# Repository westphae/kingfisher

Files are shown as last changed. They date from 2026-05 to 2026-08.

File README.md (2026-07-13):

# Kingfisher

Kingfisher is a flight data recorder for light aircraft. It runs on a
Raspberry Pi mounted in the cabin, reads sensors over IIO and ancillary
links, derives quantities like pressure altitude, magnetic declination,
and an AHRS-based attitude estimate, persists everything to a SQLite
flight database, and exposes a live cockpit UI over HTTP/WebSocket.

## Hardware

* **Main unit** mounted near the aircraft CG, inside the cabin.
  * Main controller is a `Raspberry Pi 5`.
  * Accel/gyro is a `ICM45686`.
  * GPS is a `NEO-M9N` attached via UART.
* **Pod unit** mounted out under the wing.
  * Pod controller is an `ESP32-C3-Mini-1`, variant `ESP32-C3FH4`.
  * Airspeed sensor is a `MS4525DO-DS5AI001DP`.
  * Static pressure (altimeter) sensor is a `BMP581`.
  * Magnetometer (compass) sensor is a `MMC5983MA`.

The pod is battery-powered and transmits sensor data to the main unit
wirelessly. See `internal/pod/` (Pi side) and `firmware/pod/` (ESP32
side) for the implementation.

## GPS

The `NEO-M9N` is wired to the Pi 5's GPIO UART (GPIO 14/15, header pins
8/10), enabled by `dtoverlay=uart0-pi5` in `/boot/firmware/config.txt`.

Kingfisher assumes the host wall clock is already sane. For offline operation,
discipline the Pi with `gpsd` + `chrony` first; see `docs/time-sync.md`.

**Pi 5 gotcha:** that UART is `/dev/ttyAMA0`, *not* `/dev/serial0`. On a
Pi 5 `/dev/serial0` points at the dedicated 3-pin debug-UART connector
(`ttyAMA10`), so gpsd must be told to use `/dev/ttyAMA0`. In
`/etc/default/gpsd`:

```
DEVICES="/dev/ttyAMA0"
GPSD_OPTIONS="-n -b -s 115200"
```

The `-b` (read-only) flag is deliberate. If you configured the M9N for 115200 baud
(saved to flash), you must also pass `-s 115200`; with `-b`, gpsd will not autobaud
and otherwise opens the port at 19200, which produces no fix and no TPV output. Left to manage the receiver,
gpsd subscribes a heavy set of UBX messages (NAV-SAT/SIG/POSECEF/…) that
saturate the link and drop the effective fix rate. Read-only keeps the
lean NAV-PVT-only stream the receiver is configured to emit, so we get a
clean 10 Hz.

For time discipline, prefer chrony's SOCK integration over SHM and keep
`chronyd` ahead of `gpsd` in the service order (and restart `gpsd` after any
`chronyd` restart). The repo-owned examples live in `deploy/time-sync/`. With PPS
wired, PPS disciplines the clock and the GPS serial source is marked `noselect`
(time-of-day only) — no per-receiver `offset` tuning is needed. See
`docs/time-sync.md`.

The receiver itself is configured once with `ubxtool` and the settings
are saved to its flash (they survive power-off). With gpsd running:

```bash
export UBXOPTS="-P 32.01"                      # M9N protocol version
ubxtool -z CFG-NAVSPG-DYNMODEL,7,7             # Airborne <2g (vs 0=portable)
ubxtool -z CFG-RATE-MEAS,100,7                 # 10 Hz (100 ms)
ubxtool -z CFG-RATE-NAV,1,7                    # 1 nav solution per measurement
```

To bump the link to 115200 and emit only UBX-NAV-PVT (do this with gpsd
*stopped*, talking to the port directly), set `CFG-UART1-BAUDRATE` to
`115200`, `CFG-MSGOUT-UBX_NAV_PVT_UART1` to `1`, and the other
`CFG-MSGOUT-UBX_NAV_*_UART1` items to `0`. The `,7` layer suffix writes
RAM+BBR+Flash so the config persists. The **Airborne dynamic model is the
most important setting** — the factory "portable" default filters motion
in ways that lag or drop fixes during climbs, descents, and turns.

### Rate (5 / 10 Hz)

The receiver always runs at 10 Hz; the GPS tab in the cockpit UI selects
the **recorded** rate (`rate_hz`, 5 or 10). Because gpsd is read-only,
kingfisher doesn't reconfigure the receiver — it decimates the 10 Hz
stream in software (`internal/gps`), publishing/recording every fix at
10 Hz or every other fix at 5 Hz. The setting persists in
`config.json` under `gps.rate_hz`.

### Timestamps (`ts_ns` vs fix time)

Each row in the `gps` table (and every other sensor table) has **`ts_ns`**: nanoseconds
on the Pi's disciplined wall clock. For GPS, **`ts_ns` is not the fix epoch** — it
is when kingfisher **received** the gpsd report. The receiver's fix time is stored
separately as the **`fix_time_unix_s`** column (typically **~600–700 ms earlier**
than `ts_ns` on this M9N + gpsd setup; that gap is receiver/pipeline lag, not clock
error).

For sensor fusion: align GPS with cabin IMU and pod data on **`ts_ns`**; use
**`fix_time_unix_s`** when you need GNSS solution time. Full per-source semantics
(buffered IIO, pod reconstruction, derived devices, fusion checklist) are in
**[`docs/timestamps.md`](docs/timestamps.md)**.

## Timestamps

All flight DB sensor tables store **`ts_ns`** (nanoseconds, Unix epoch) on the
Pi host wall clock (`CLOCK_REALTIME`), ideally GNSS-disciplined before recording.

| Source | `ts_ns` meaning (summary) |
|---|---|
| Buffered IIO (ICM45686, …) | Kernel capture time when `current_timestamp_clock == realtime` |
| Polled IIO | Time when the periodic sysfs read completed |
| GPS | Pi time when the TPV was **received**; fix epoch is **`fix_time_unix_s`** |
| Pod (BMP581, MS4525, MMC5983) | Sample time reconstructed onto Pi clock from pod uptime + `age_us` |
| Derived (AHRS, press_alt, geo, compass) | Time when the value was **computed** (inputs may be slightly older) |

See **[`docs/timestamps.md`](docs/timestamps.md)** for measurement error vs true
sample time, GPS fusion guidance, and implementation references.

## Building

```
go build ./cmd/kingfisher
```

Pod firmware lives under `firmware/pod/`; see
[`firmware/pod/README.md`](firmware/pod/README.md) for the wiring,
toolchain, and flashing steps.

## Running

```
./kingfisher
```

Kingfisher listens on **`http_addr`** (default **`:8080`**) and is meant to sit
behind a reverse proxy on the aircraft LAN. Configuration lives in
`~/.config/kingfisher/config.json`.

### HTTPS with Caddy (recommended)

[Caddy](https://caddyserver.com/) terminates TLS on port **443**, redirects HTTP
port **80** to HTTPS, and reverse-proxies to kingfisher on `localhost:8080`
(including WebSocket traffic for the live cockpit and `/terminal`).

Example Caddyfile (also in **`deploy/caddy/Caddyfile`**). Adjust the hostname and
LAN IP for your Pi:

```caddyfile
https://kingfisher.lan, https://kingfisher, https://192.168.10.1, https://192.168.86.151, https://127.0.0.1 {
    tls internal
    reverse_proxy localhost:8080
}

http://kingfisher.lan, http://kingfisher, http://192.168.10.1, http://192.168.86.151, http://127.0.0.1 {
    redir https://{host}{uri} permanent
}
```

`tls internal` uses a **local certificate authority** managed by Caddy — fine for
a private LAN; not a public-trusted cert.

**Install on Debian / Raspberry Pi OS** (official apt repo):

```bash
sudo apt install -y debian-keyring debian-archive-keyring apt-transport-https curl
curl -1sLf 'https://dl.cloudsmith.io/public/caddy/stable/gpg.key' \
  | sudo gpg --dearmor -o /usr/share/keyrings/caddy-stable-archive-keyring.gpg
curl -1sLf 'https://dl.cloudsmith.io/public/caddy/stable/debian.deb.txt' \
  | sudo tee /etc/apt/sources.list.d/caddy-stable.list
sudo chmod o+r /usr/share/keyrings/caddy-stable-archive-keyring.gpg \
  /etc/apt/sources.list.d/caddy-stable.list
sudo apt update && sudo apt install -y caddy
sudo cp deploy/caddy/Caddyfile /etc/caddy/Caddyfile
sudo caddy validate --config /etc/caddy/Caddyfile
sudo systemctl enable --now caddy
```

Keep kingfisher on the loopback port only:

```json
"http_addr": ":8080"
```

**Trust the CA**

On the Pi (so curl and local browsers trust HTTPS):

```bash
sudo caddy trust
```

On laptops, phones, and tablets, install Caddy's root certificate once. After
Caddy has started at least once, the file is usually:

```text
/var/lib/caddy/.local/share/caddy/pki/authorities/local/root.crt
```

Copy it to the device and add it to the system/browser trust store (or use
`sudo caddy trust` on each Linux machine). Until then, browsers show a
certificate warning — you can proceed for testing, but trusting the CA removes
the nag and enables secure-context APIs (clipboard, etc.) over HTTPS.

Open the cockpit at **`https://<pi-hostname-or-ip>/`** (port 443; HTTP on port 80
redirects automatically).

### EFB apps (ForeFlight, iFlyEFB)

Kingfisher can broadcast **Stratux-compatible GDL90** over UDP port **4000** so
tablets on the Pi access point receive GPS position and AHRS attitude without a
separate Stratux box. Enable in `config.json`:

```json
"gdl90": {
  "enabled": true,
  "static_ips": ["192.168.10.141", "192.168.10.40"]
}
```

On the Pi AP (NetworkManager + dnsmasq), list each tablet’s reserved IP in
`static_ips` — see **`deploy/efb/ap-setup.md`** for DHCP reservations, MAC
privacy settings, and verification.

**ForeFlight:** connect to the Pi Wi‑Fi → *More* → *Devices* → enable GDL90 at
**`192.168.10.1`**.

**iFlyEFB:** *Menu* → *About* → *Connected Devices* → Stratux/FlightBox;
*Setup* → *ADS-B* → Stratux/Flightbox (manual). Expect **GPS Data Only**.

Requires `ahrs.enabled` for attitude. Traffic and weather are not sent (no ADS-B
receiver). Check `/api/status` → `gdl90` for client count and last send time;
`tcpdump -i wlan0 udp port 4000` should show steady packets when an EFB is
connected.

### systemd user service (boot)

Kingfisher is normally run as your Pi login user (IIO device access, config under
`~/.config/kingfisher/`, flight DBs under `~/kingfisher/flights`). A **systemd user
unit** starts it at boot without keeping an SSH session open.

**Prerequisites:** gpsd and chrony configured per **`docs/time-sync.md`**. If you
use Caddy for HTTPS, enable **`caddy.service`** separately (system unit); start
kingfisher first so the reverse proxy has a backend on `:8080`.

1. **Install the binary** with `go install` (default: `$(go env GOPATH)/bin`, usually
   `~/go/bin`; override with `GOBIN` if you use it):

   ```bash
   cd ~/go/src/github.com/westphae/kingfisher
   go install ./cmd/kingfisher
   ```

2. **Install the user unit** from the repo example (path must match step 1):

   ```bash
   mkdir -p ~/.config/systemd/user
   bin="$(go env GOBIN)"
   [ -z "$bin" ] && bin="$(go env GOPATH)/bin"
   sed "s|__KINGFISHER_BIN__|$bin/kingfisher|g" \
     deploy/systemd/kingfisher.service.example \
     > ~/.config/systemd/user/kingfisher.service
   ```

3. **Enable linger** so the user service starts at boot (not only after login):

   ```bash
   sudo loginctl enable-linger "$USER"
   loginctl show-user "$USER" -p Linger   # expect Linger=yes
   ```

4. **Enable and start:**

   ```bash
   systemctl --user daemon-reload
   systemctl --user enable --now kingfisher.service
   ```

5. **Check status and logs:**

   ```bash
   systemctl --user status kingfisher.service
   journalctl --user-unit=kingfisher.service -f
   curl -s http://127.0.0.1:8080/api/status | head
   ```

   Use **`--user-unit`** (not `journalctl --user`): on Raspberry Pi OS the user
   manager logs to the **system** journal; there is no separate per-user journal
   file under `/run/user/$UID/journal`, so `journalctl --user` shows nothing even
   though `systemctl --user status` does.

The unit starts kingfisher **immediately** — there is no chrony pre-wait (the
old `kingfisher-prestart.sh` gate is retired). The UI and recording come up in
seconds on the RTC clock:

| Situation | Behavior |
|---|---|
| **RTC sane (normal)** | Timestamp-named flight DB; red cockpit banner until chrony locks |
| **Any chrony step/slew ≥ 20 ms** | Row in the DB's `clock_offsets` table (see `docs/timestamps.md`) |
| **RTC dead (clock reads 1970)** | DB named `unsynced_NNNN_<tail>.db`; renamed at close once true time is known |

Startup metadata, the `clock_offsets` mapping table, and the cockpit clock
badge/banner record discipline state. `RestartSec=30` retries a failed main
process.

**After upgrading:** `go install ./cmd/kingfisher`, then
`systemctl --user restart kingfisher.service`.

**Stop/disable:**

```bash
systemctl --user disable --now kingfisher.service
```

Example unit file: **`deploy/systemd/kingfisher.service.example`**.

### Browser terminal (optional)

Kingfisher can expose a full-screen web terminal at **`/terminal`** (footer link
on the cockpit page). It is **disabled by default**; enable in `config.json`:

```json
"terminal": {
  "enabled": true,
  "user": "eric",
  "authorized_keys": [
    "ssh-ed25519 AAAA... kingfisher-terminal"
  ],
  "allow_password": false,
  "session_timeout_min": 480,
  "max_sessions": 2
}
```

**Public-key login (recommended):** put one or more OpenSSH `authorized_keys` lines in
`authorized_keys` and set `user` to the Unix account the shell should run as. The
browser signs a one-time challenge with a private key stored locally (generate in
the terminal UI, or import an unencrypted Ed25519 `id_ed25519`). Your password is
never sent. Set `"allow_password": true` to keep PAM login as a fallback.

**Password login:** when `authorized_keys` is omitted, login uses **Linux PAM**
(same username/password as SSH). The shell runs as the authenticated user when
kingfisher runs as that user; logging in as a different user requires root or
`cap_setuid` on the kingfisher binary.

**Security:** with Caddy **`tls internal`** in front (see above), terminal traffic
including WebSockets is encrypted on the LAN. Without HTTPS, password login sends
credentials in cleartext; public-key login avoids sending passwords but session
cookies and shell I/O are still visible on the wire.

Building on Linux requires **`libpam0g-dev`** for CGO (`apt install libpam0g-dev`).

If you want DB filenames, session start times, and buffered IIO timestamps to be
meaningful immediately after boot, start kingfisher only after GNSS time sync is
healthy. `docs/time-sync.md` includes a `chronyc waitsync` systemd pattern and a
verification checklist. Per-table **`ts_ns`** semantics and sensor-fusion usage
(including GPS **`fix_time_unix_s`**) are documented in **`docs/timestamps.md`**.

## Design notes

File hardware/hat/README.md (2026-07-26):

# Kingfisher Sensor HAT (rev 0.2)

Custom Raspberry Pi HAT that consolidates the cabin sensors currently on SparkFun /
breakout boards + ribbon cable:

| Ref | Part | Role |
|-----|---|---|
| U1 | ICM-45686 | Cabin IMU (I²C `0x68`, INT → GPIO17) |
| U2 | BMP581 | Cabin baro / temp (I²C `0x47`) |
| U3 | AP2112K-3.3 | 5 V → 3.3 V for GPS |
| U4 | NEO-M9N | GNSS (UART0 + PPS → GPIO18); `V_BCKP` diode-OR’d |
| U5 | RV-3028-C7 | I²C RTC (`0x52`), `VBACKUP` ← CR2032 |
| BT1 | CR2032 + Keystone 3002 | Replaceable backup for RTC + GPS |
| D1, D2 | BAT54 | Schottky OR: `+3V3_GPS` / `VBAT` → `V_BCKP` |
| J1 | 2×20 pin socket | Mates **extended GPIO pins above the M.2 HAT+** (bottom side) |
| J2 | U.FL | Antenna → existing SMA bulkhead pigtail |

Form factor: official Pi HAT outline (65 × 56.5 mm, M2.5 holes 58 × 49).

**Why RV-3028 not DS3231?** DS3231 sits on `0x68` and would collide with the ICM.
**Why CR2032 not CR1220?** ~5× capacity for multi-year GPS/`V_BCKP` + RTC backup;
Keystone 3002 is a common replaceable HAT holder (check lid height).

See [docs/DESIGN.md](docs/DESIGN.md) for the backup topology, I²C map, retention
estimates, and the “what else” resilience shortlist (test points / DNP pull-ups
recommended; second watchdog / LED forest skipped).

## Open in KiCad

Requires **KiCad 9** (project generated against 9.0.2).

```bash
kicad hardware/hat/kingfisher-hat.kicad_pro
```

Project-local libraries:

- `libs/Kingfisher.kicad_sym` — ICM-45686, BMP581, NEO-M9N
- `libs/Kingfisher.pretty` — BMP581 land pattern (adapted from SparkFun Qwiic BMP581, CC-BY-SA 4.0)

Regenerate libraries / schematic scaffolding (stdlib only — **no uv project**):

```bash
python3 hardware/hat/scripts/build_libs.py
python3 hardware/hat/scripts/build_sch.py   # overwrites schematic
kicad-cli sch export netlist hardware/hat/kingfisher-hat.kicad_sch
```

Any future `pcbnew` automation must use **system** Python with apt KiCad
(`python3-pcbnew`), not a uv venv — the PCB API is not a PyPI package.

## Status (rev 0.2)

Done:

- HAT mechanical from KiCad Raspberry Pi HAT template (outline, holes, bottom GPIO socket)
- Custom symbols + BMP581 footprint
- **Loadable** schematic rev 0.2 (ICM, BMP581, GPS, LDO, U.FL, RV-3028, CR2032, diode-OR)
  — netlist exports 18 components; open in eeschema to tidy wire/label geometry
- PCB: 4-layer stack selected; major footprints placed (not yet routed); BT1/U5/D1–D2 placement TBD
- Design notes for RTC address, GPS backup, and resilience add-ons

Not done yet:

1. Schematic pin–label wiring cleanup + ERC green
2. Place BT1 / U5 / diodes / test points; full routing
3. Cardboard / 3D mockup (pin engagement + CR2032 lid clearance)
4. JLCPCB BOM / CPL export
5. Software: cabin BMP581 reader + `i2c-rtc` for RV-3028

## Attribution

- Board outline / GPIO placement: KiCad `RaspberryPi-HAT` template
- BMP581 pad geometry: adapted from [SparkFun Qwiic Pressure Sensor BMP581](https://github.com/sparkfun/SparkFun_Qwiic_Pressure_Sensor_BMP581) hardware (CC-BY-SA 4.0)
- NEO-M9N symbol derived from KiCad library `NEO-M8N` (same NEO pinout family)
- GPS backup idea: SparkFun NEO-M9N breakout (diode-OR backup supply; we use replaceable CR2032)

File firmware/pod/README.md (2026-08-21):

# Pod firmware

Rust no_std firmware for the wing-pod `ESP32-C3-Mini-1` (variant
`ESP32-C3FH4`). The pod associates to the cabin Pi's WiFi AP and
transmits postcard-encoded `Frame`s (defined in `pod_wire/`) over UDP.

**Status: Phase 3c — all three I²C sensors coded.** BMP581 uses NORMAL mode +
on-chip FIFO (PT frames); the poll loop drains all pending frames each tick with
per-sample capture times. Mag and airspeed use the tick poll loop with per-sensor
pending queues (default **10 Hz** = uplink rate). Uplink ships up to
`MAX_READINGS` readings total per datagram; firmware logs
`dropped … (pending full)` or `(batch full)` when a queue or the wire batch
overflows.
**No sensor is required** at boot; missing devices are re-probed every 5 s.

## Bill of materials

| Part | Role |
| --- | --- |
| ESP32-C3-Mini-1 (C3FH4) | MCU + radio |
| MS4525DO-DS5AI001DP | Airspeed (differential pressure), I²C 0x28 |
| BMP581 | Static pressure, I²C 0x46 (or 0x47 if SDO tied) |
| MMC5983MA | Magnetometer, I²C 0x30 |
| SparkFun Battery Babysitter | BQ27441 fuel gauge, I²C 0x55 (optional) |
| LiPo cell, 3.7 V nominal | Power (via Battery Babysitter or direct) |
| 3.3 V LDO (≥250 mA) | Regulator, e.g. AP2112-3.3 or MCP1700 |
| 2× 4.7 kΩ | I²C pull-ups (SDA / SCL → 3V3) |
| Pitot/static plumbing tubing  | Routes airflow to MS4525DO and BMP581 |
| Antenna (chip or U.FL pigtail)| 2.4 GHz |

The ESP32-C3-Mini-1 has an on-module PCB antenna; the variant with the
U.FL connector (`ESP32-C3-MINI-1U`) is preferable for a wing pod since
the module sits inside a (probably composite or sheet-metal) fairing.

## Wiring

BMP581 and MMC5983 run at **3.3 V** on the Qwiic bus. The **MS4525DO-DS5**
variant needs **5 V on VCC** (separate from the ESP 3.3 V); I²C lines still
join the same Qwiic chain (confirm your breakout is 3.3 V I²C-tolerant).
Use **4.7 kΩ pull-ups to 3V3** once on the bus; each Qwiic board may also
ship 2.2 kΩ — cut **I2C** on one board if the bus misbehaves when daisy-chaining.

| ESP32-C3 pin | Net | To |
| --- | --- | --- |
| `IO5` | `SDA` | Qwiic / MS4525DO, BMP581, MMC5983MA, BQ27441 |
| `IO6` | `SCL` | Qwiic / MS4525DO, BMP581, MMC5983MA, BQ27441 |

Desk bench with [SparkFun Pro Micro ESP32-C3](https://docs.sparkfun.com/SparkFun_Pro_Micro-ESP32C3/hardware_overview/) + Qwiic cable: firmware uses **IO5/IO6** (matches SparkFun `pins_arduino.h`). A plug-in Qwiic BMP581 (SEN-20170, default **0x47**) needs no extra wiring.

**Battery Babysitter (PRT-13777):** connect the Qwiic port to the same bus. Tie **VPU** to **3.3 V** (ESP `3V3`). A LiPo must be plugged into the Babysitter for the BQ27441 to respond. Pick **750** or **2000** mAh (or type a custom value) in cockpit Settings on the `bq27441` tab. The G1A data memory is RAM-only: unplugging the pack (ITPOR) restores ROM defaults (Design Capacity 1340 mAh). Firmware rewrites **Design Capacity** and **Design Energy** only (TI/SparkFun). It does **not** write State Qmax Cell 0 (`Qmax_mAh = QmaxCell0 × DesignCap / 16384`; default QmaxCell0 is 16384, so Qmax starts at Design Capacity) or Default Design Cap (chem-ID scale). Poking learned FCC into Qmax Cell 0 left FullChargeCapacity stuck at 1340.

Planned wing pod PCB may move the bus to **IO4/IO5**; update `main.rs` when that layout is fixed.
| `IO8`        | `LED`   | Status LED (active-low, with 1 kΩ)    |
| `IO3` (ADC)  | `VBATT` | LiPo cell + ÷2 voltage divider        |
| `3V3`        | `3V3`   | LDO output to all sensors             |
| `GND`        | `GND`   | Common ground                         |
| `IO18`/`IO19`| USB D-/+| USB-C connector for flashing          |
| `EN`         | `EN`    | 10 kΩ pull-up to 3V3, optional button |

**Bench Qwiic chain:** Pro Micro → BMP581 (0x47) → [MMC5983MA](https://www.sparkfun.com/products/19921) (0x30) → MS4525 (0x28) when powered. Firmware re-probes MS4525 every 5 s if it was missing at boot.

The native USB peripheral on `IO18`/`IO19` lets `espflash` talk
directly to the chip — no external USB-UART bridge needed. A single
USB-C connector with ESD protection is sufficient.

### Pitot plumbing

* MS4525DO has two pressure ports labelled `+` and `-`.
  - `+` → pitot (total) tube on a probe ahead of the wing leading edge
  - `−` → static port on the side of the pod
* BMP581 sits in a chamber connected to the same static port (it is a
  silicon MEMS device — keep it out of the airflow stream).
* Mount the MMC5983MA on the same PCB but as far as possible from
  current-carrying traces and the LiPo, and orient it so its X axis
  is aligned with the airframe longitudinal axis when the pod is
  level. Axis corrections happen on the Pi (see the plan), so an
  approximate mount is fine — just keep it consistent.

**TODO — MMC5983 data-ready `INT`:** Wire the breakout’s Qwiic **INT** pin (active-high,
hi-Z until enabled) to a spare ESP32-C3 GPIO on the wing PCB (candidate **IO7** on the
bench Pro Micro; document the net in the table above when fixed). Firmware already sets
`INT_meas_done_en` and polls `Meas_M_Done` over I²C today; still to do: EXTI/GPIO
interrupt handler, read the 7-byte `XOUT` burst on INT (no status polling in the hot
path), and coordinate bus access with the existing async poll task.

### Power & current budget

Steady-state draw with WiFi STA active is ~120 mA average and ~350 mA
peak on transmit. A 1000 mAh LiPo gives ≥ 5 h flight time at 50 Hz
mag / 10 Hz airspeed/static. The LDO must handle the TX peak; AP2112
is OK to 600 mA. Add a 22 µF tantalum + 100 nF ceramic at the LDO
output to keep the radio happy.

A 5 V boost option (so the pod accepts a wider supply range) is fine
to add downstream but doesn't change anything firmware-side.

## Toolchain

ESP32-C3 is a RISC-V 32-bit core (`riscv32imc`). The Rust ESP ecosystem
supports it natively under stable Rust — no nightly or xtensa-llvm
required (that's only the Xtensa-core ESP32 variants).

```bash
# Once per machine:
rustup target add riscv32imc-unknown-none-elf
cargo install espflash
```

`espflash` provides both `cargo espflash` (subcommand) and a standalone
`espflash` binary. It speaks USB-CDC directly to the C3 over the
on-module USB port, so no separate driver/bridge tool is needed on
Linux.

If you also need to read the on-chip serial console while running:

```bash
espflash monitor
```

## Build & flash

Once the source tree exists:

```bash
cd firmware/pod
cargo build --release             # builds the .elf
espflash flash target/riscv32imc-unknown-none-elf/release/pod --monitor
```

The `--monitor` flag stays attached after flash and prints `defmt`
log lines from the running firmware over the same USB connection.

### Pre-shared configuration

Until provisioning lands (v2), pod WiFi and UDP settings live in the
same kingfisher JSON config as the Pi runtime (`~/.config/kingfisher/config.json`).
See [`config.example.json`](../../config.example.json) for the `pod` block shape.

```json
"pod": {
  "wifi_ssid": "kingfisher",
  "wifi_password": "",
  "udp_addr": "192.168.10.1:47808",
  "battery_capacity_mah": 850,
  "burst_soc_pct": 30,
  "burst_window_s": 60,
  "burst_voltage_v_uncalibrated": 3.60,
  "protect_voltage_v": 3.50,
  "protect_soc_pct": 5,
  "low_debounce_s": 45,
  "modem_power_save": false,
  "buffer_max_readings": 128,
  "flush_interval_s": 3,
  "flush_high_watermark": 24
}
```

`pod.udp_addr` must be the AP gateway (`ipv4.addresses` on the Pi AP
connection) and the port kingfisher listens on. `build.rs` reads the
file at compile time and injects values into `src/cfg.rs` via `env!`.
Cross-machine builds: `KINGFISHER_CONFIG=/path/to/config.json cargo build --release`.

## Deferred bench validation (Phase 3c / MS4525)

Not required for Phase 4 firmware work. Run when 5 V is available for the
MS4525DO-DS5:

| Step | Action | Pass criteria |
|---|---|---|
| Power | Apply **5 V** to MS4525 VCC (3.3 V I²C on Qwiic) | Serial: `ms4525 attached at 0x28` within 5 s hot-attach |
| Flash | `cargo build --release` + `espflash flash` (FW `0x0003_0002` or later) | `uplink ok` with non-empty batches |
| Pi | `go run ./cmd/kingfisher` (not podprobe on `:47808`) | `pod` device: `static_*`, `mag_*` |
| Airspeed | Rest + light suction/blow on **+** port | `airspeed_dp_pa` ~0 at rest; moves with ΔP; `airspeed_temp_c` plausible |

## Verification

Pre-condition: Pi WiFi AP running; `~/.config/kingfisher/config.json`
`pod` block matches the AP; sensors on Qwiic (Pro Micro **IO5/IO6**).

1. **Flash**: `cargo build --release` then
   `espflash flash --monitor target/.../release/pod`. Monitor should show:
   - `pod: i2c scan: 0x47(id=0x50) … 0x30(id=0x30)` and `0x28(st=0)` when MS4525 powered
   - `pod: sensor board ready …` (ms4525 line optional if no 5 V)
   - WiFi + `sent Hello` + `uplink ok, … pkts`
2. **Kingfisher**: `go run ./cmd/kingfisher` — `pod` shows `static_*`, `mag_*`, and
   `airspeed_*` when MS4525 is on the bus.
3. **MS4525 bench** (5 V applied): `airspeed_dp_pa` near 0 at rest; suction/blow on
   the `+` port moves ΔP. Without 5 V, `ms4525 not present` is expected.

### Power protocol validation (see docs/pod-power.md)

Bench-verified 2026-07-14 with forced thresholds (temp `KINGFISHER_CONFIG`
with `burst_soc_pct: 100` / `protect_soc_pct: 100`, short `low_debounce_s`,
plus a temporary `CHARGE_CURRENT_A` bump so USB charge current doesn't force
Active):

1. **Burst cycling:** `power_mode` 3/4 in Status; radio drops between
   windows (Pi shows `burst_quiet`); each window drains the full backlog
   (tx counter jumps by ~backlog/8) and DB rows stay continuous across
   radio-off periods (max inter-row gap ≈ sample period, not window
   length). At 50 Hz static the 90% ring-fill trigger fires at ~27 s —
   expected.
2. **Protect:** `power_mode` 5 → 6 in Status, then USB/WiFi drop (deep
   sleep). Timer wake every `PROTECT_WAKE_CHECK_S`: gauge read pre-WiFi;
   recovered/charging resumes a normal boot (fresh uptime + Hello),
   still-low goes straight back to sleep.
3. **Keepalive:** exactly one Hello per association — the Pi's 5 s Ping
   refreshes `last_inbound` (a Ping that doesn't would re-Hello every
   30 s and re-trigger SetRate churn; that bug shipped in Phase 4 and was
   fixed here).

### BQ27441 gauge learning

Design capacity (`pod.battery_capacity_mah`, 750 or 2000 typically) is a **config write** to
the gauge after ITPOR or when 0x3C still shows the G1A factory 1340 mAh. Firmware patches
State subclass 82 **Design Capacity** (offset 10) and **Design Energy** (offset 12), then
SOFT_RESET. **Do not host-write Qmax Cell 0** (offset 0): TI’s default is 16384 Num, and
`Qmax_mAh = QmaxCell0 × Design Capacity / 2^14`. **Do not change Default Design Cap**
(offset 14): it is the chem-ID scale. The Pi may still Ack `QmaxCapacity` and store last FCC in
`pod.battery_learned_mah` for the Settings readout — that value is not programmed
into the chip.

The G1A has **no flash** for these parameters. Unplugging the LiPo JST sets ITPOR.
**Impedance Track learning** (Qmax, resistance profile) still needs a real
charge/discharge at representative load after Design Capacity is correct. Do not
re-enter CFGUPDATE every minute if FCC lags — that suspends gauging.

**Calibration run (bench or wing, pod at normal WiFi/sensor load):**

1. **Full charge** to 4.2 V (charger taper complete), then **rest 30–60 min**.
2. **Discharge** with the pod running normally until **~3.35–3.45 V under load**
   (or SOC ~5–10% once `full` reads near design capacity). That includes the
   discharge knee; **stop there** — do not chase ≤3.1 V for calibration.
3. **Rest ≥2 h** (overnight is fine), then **full charge** again.

One or two such cycles is usually enough. After that, partial cycles maintain
accuracy; repeat a full anchor cycle every few months or after long storage.

**Pass criteria:** serial `bq27441 design 2000 mAh verified` with `0x3C=2000`; live
`battery_capacity_full_mah` is the chip FCC (factory leftover ~1340 until IT
resims — not a Pi last-saved substitute); `battery_gauge_learned` once FCC is
70–120% of the configured pack; SOC tracks voltage on the next partial cycle.

**Cell note:** a single deep discharge to ~3.1 V loaded is unlikely to harm the pack
if it charges normally afterward, but it adds wear without much extra gauge benefit.
Treat **3.4 V under load** as the calibration target, not the operating floor.

**Status: Phase 4 — control plane and link keepalive.** Firmware answers Pi
`Ping` with `Pong`, gates `Hello` when the link is active (30 s rediscover),
handles `Cmd`/`Ack` (including `SetRate`), sends dynamic caps and periodic
`Status`. Pi assigns cmd seq, tracks pending `Ack`, and reverts failed rate changes.

### Persisted settings (Pi config)

Sampling rates set in the web UI are written to `~/.config/kingfisher/config.json`
under `pod.attrs` (e.g. `in_mag_sampling_frequency`) and survive power cycles.
Kingfisher reapplies
them on startup and after each pod Hello; changing config and saving also re-sends
`SetRate` to the pod. Firmware does not read this file — only the Pi pushes rates
over UDP after restart.

### Sampling rates and autonomic recovery (FW `0x0004_0002+`)

BMP581 uses on-chip FIFO at the configured ODR; MMC5983 runs in **continuous mode**
with **CM_Freq** matched to `SetRate` (1–100 Hz at BW=00). Each sample is a 7-byte
burst from `XOUT` after checking `Meas_M_Done` over I²C (see **TODO** above for GPIO
`INT`). Multiple mag readings per 100 ms tick are queued in the uplink batch like
static FIFO frames; airspeed uses the same pending queue (default 10 Hz). The firmware
enforces a **75 ms I²C work budget per 100 ms tick** and rejects unsustainable
combinations at `SetRate` time (Ack `ok=false`). Example: **50 Hz static + 50 Hz
mag is rejected**; **25 + 50** is OK. Hello **max Hz** shrinks when more sensors
are attached so the UI does not offer impossible pairs.

If reads fail repeatedly, a tick overruns (>80 ms of I²C), or many errors occur in
one tick, the pod **backs off** the last changed rate (or halves it) and runs
**I²C recovery** (re-init attached sensors, safe 10 Hz defaults). Serial log:
`pod: backing off …` / `pod: i2c recovery`. No wing visit required for that flight.

### Phase 4 verification

1. Flash FW `0x0004_0002` (or later); start kingfisher on the Pi AP.
2. Serial: `sent Hello` once at boot, then quiet; `uplink ok` when sensors present.
3. Pi log: no repeated `pod: ping` errors after the pod appears; `ack for_seq=…` when
   changing `sampling_frequency` on the pod settings channels (`mag`, `static`, `airspeed`) in the UI.
4. Stop kingfisher for ~30 s: Hello resumes on the pod serial log.
5. Hot-plug a sensor: next Hello lists only attached caps.

## Troubleshooting

* **`espflash` can't find a device**: hold the `BOOT` button while
  plugging USB-C, or pulse `EN` low while `IO9` is held low. If the
  C3 is in deep sleep the USB CDC interface disappears — same fix.
* **I²C reads return all-0xFF**: pull-ups missing or wrong rail; or
  two devices configured to the same address (rare here since all
  three are distinct).
* **WiFi never associates**: the Pi-side AP must be on a 2.4 GHz
  channel — the C3 has no 5 GHz radio. The bench AP also matters: a
  Pi 5 running `hostapd` on `wlan0` is the supported topology.
* **Packets arrive at the Pi but kingfisher never shows the pod**:
  check `tcpdump -i wlan0 udp port 47808` for raw frames. If frames
  are present, the issue is either the CRC (most likely — re-verify
  the postcard schema matches `pod_wire/`) or the kingfisher pod
  listener is bound to a different interface; confirm with `ss -lup`.

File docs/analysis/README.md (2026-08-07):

# Flight data analysis

Tools to catalog kingfisher SQLite sessions, grade sampling health, and keep an
ongoing ledger for modeling (compass, AHRS, performance) and cleanup.

## Quick start

Uses **uv** (workspace member `analysis/`; see [`docs/python.md`](../python.md)).
From repo root (Pi or workstation with a copy of `flights/`):

```bash
uv sync --all-packages   # or: uv sync --project analysis
uv run --project analysis python scripts/analyze_flights.py all
```

Outputs:

| Artifact | Default path |
|---|---|
| Catalog JSON | `~/kingfisher/analysis-cache/catalog.json` |
| Health JSON | `~/kingfisher/analysis-cache/health.json` |
| Motion windows | `~/kingfisher/analysis-cache/windows/` (parquet) |
| Noise study | `~/kingfisher/analysis-cache/noise/` + `docs/analysis/sensor_noise.md` |
| Full plan | [`PLAN.md`](PLAN.md) |
| Ledger (git) | `docs/analysis/ledger.md` |

Commands:

```bash
uv run --project analysis python scripts/analyze_flights.py catalog
uv run --project analysis python scripts/analyze_flights.py health --flights-only
uv run --project analysis python scripts/analyze_flights.py windows
uv run --project analysis python scripts/analyze_flights.py noise
uv run --project analysis python scripts/analyze_flights.py report
uv run --project analysis python scripts/analyze_flights.py cal-accel --json ~/kingfisher/calibration/cabin_accel_….json --plot
uv run --project analysis python scripts/analyze_flights.py windows --file 20260722T203620Z_n456t.db

# Bench cal UI (cabin accel six-face + cabin gyro still + pod mag TBD): [calibrate.md](calibrate.md)
# Roadmap status: [PLAN.md](PLAN.md)

# Legacy sampling plots (matplotlib):
uv run --project analysis python scripts/analyze_flight_sampling.py --help
```

Dependencies (locked in root `uv.lock`): Python ≥3.11, `numpy`, `matplotlib`, `pyarrow`, `pandas`.

## Layout

```
analysis/                 # Python package (importable from scripts/)
scripts/analyze_flights.py
docs/analysis/
  README.md               # this file
  ledger.md               # ongoing catalog (regen preserves hand notes)
~/kingfisher/
  flights/                # *.db (+ optional *.md sidecars)
  flights-archive/        # move no_info here after review
  analysis-cache/         # regenerable JSON
  imu_tempcal/            # bias/TCO experiments
  engine/                 # planned: engine-monitor dumps
  weather/                # planned: METAR/TAF/winds aloft/turb
```

Recording stays on the Pi. Heavy modeling can run on a workstation against an
`rsync`/`scp` of `flights/` (and later `engine/`, `weather/`).

## Classification

| Class | Rule (v1) |
|---|---|
| `flight` | GPS max groundspeed ≥ 40 kt, or sidecar `class: flight` |
| `taxi_only` | 5 ≤ max gs &lt; 40 kt |
| `soak` | Longer stationary session (desk/hangar/overnight) |
| `experiment` | Sidecar `class: experiment` or tags |
| `no_info` | Tiny (&lt;2 MB) or short (&lt;5 min) — archive candidate |

Override with a sidecar next to the DB, e.g. `20260621T185102Z_n456t.md`:

```yaml
---
class: flight
flightaware: https://...
engine_dump: ../engine/raw/foo.csv
tags: pattern, kcxo
---

Free-form notes…
```

## Motion windows (Phase 0)

Label every session in `flights/` (aircraft *and* desk soaks) into 1 s epochs,
then merge contiguous runs into segments:

| Label | Meaning |
|---|---|
| `stationary` | Still — use for calibration ("level windows") |
| `taxi` | GPS gs in taxi band (default 5–40 kt) |
| `flight` | GPS gs ≥ 40 kt |
| `transient` | Bump / pick-up, or motion without GPS taxi/flight (desk handling) |

Without reliable GPS, only `stationary` / `transient` are used (so desktop
sessions never become fake taxi/flight).

### Parquet layout (append-friendly)

One giant file would work for epochs (~1 Hz × hours × tens of sessions is only
tens–hundreds of MB), but **rewriting it on every run is painful**. Instead:

```
~/kingfisher/analysis-cache/windows/
  manifest.json
  epochs/session_id=<stem>/part.parquet    # 1 Hz labels + features
  segments/session_id=<stem>/part.parquet  # contiguous runs (small)
  segments_all.parquet                     # compacted segments (optional)
```

Re-running one session overwrites only that `session_id=` partition. Read with
pandas/pyarrow datasets:

```python
import pyarrow.dataset as ds
epochs = ds.dataset(".../windows/epochs", format="parquet", partitioning="hive")
segments = ds.dataset(".../windows/segments", format="parquet", partitioning="hive")
# or: pd.read_parquet(".../windows/segments_all.parquet")
```

## Health grades

For `class=flight` sessions:

- Per-table median Δt / mean Hz / gaps (threshold ≈ max(3×nominal, 250 ms))
- Aligned multi-sensor pod holes &gt;1 s → batch/link loss
- Coverage: time before first taxi, airborne minutes (gs≥40), after last motion
- Missing core cabin (`gps`, IMU, `ahrs`, …) or pod (`bmp581`, `mmc5983`, `bq27441`)

**Pre-session pod backlog is ignored for gap scoring.** Normal workflow is to
power the wing pod first, then start the cabin hub: aged UDP readings can land
with `ts_ns` before `_session.start_time`. Rates/gaps use only
`ts_ns >= start_time`. Pre-session row counts are noted but do not lower the
grade.

`icm45686_*` chip ODR in `sensor_attrs` (e.g. 800 Hz) vs ~10 Hz stored rows is
expected, not a dropout.

## Ledger hand notes

`docs/analysis/ledger.md` is regenerated by `report`. Content between
`<!-- HAND_NOTES_BEGIN -->` and `<!-- HAND_NOTES_END -->` is preserved.

## Modeling path (later)

| Goal | Primary inputs | Correlated later |
|---|---|---|
| Mag → compass | `mmc5983`, `geo`, taxi GPS | — |
| IMU → AHRS | `icm45686_*`, GPS, baro, temp | see `docs/icm45686-bias-compensation.md` |
| Pitot / airspeed | `ms4525`, baro, GPS | only flights with pitot tables |
| Performance | GPS, AHRS, howgozit | **engine monitor**, **weather** |

### Planned: engine monitor

Drop exports under `~/kingfisher/engine/raw/`, normalize + time-align to
kingfisher `ts_ns` / UTC, link from sidecar `engine_dump:`.

### Planned: weather

Observations and forecasts (METAR/TAF, winds and temperatures aloft, turbulence
products) under `~/kingfisher/weather/`, keyed by flight time and route/region.
Used for TAS/wind consistency checks and atmosphere context in flight models —
not required for v1 catalog/health.

## Related

- `scripts/analyze_flight_sampling.py` — earlier gap/plot tool; health logic is
  being folded into `analysis/health.py` (legacy script kept for now).
- `docs/timestamps.md` — what `ts_ns` means per source.

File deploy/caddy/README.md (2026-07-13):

# Caddy reverse proxy

Caddy terminates TLS in front of kingfisher (which stays plain HTTP on
`localhost:8080`) and serves it as HTTPS on the AP and home LAN. TLS keeps the
`eric` password (ssh + web terminal) unsniffable on the deliberately-open
`kingfisher` AP — see `deploy/system-rebuild-playbook.md` Appendix A.

## Files

- [`Caddyfile`](Caddyfile) — the site config. Install to `/etc/caddy/Caddyfile`.

```sh
sudo install -m 644 deploy/caddy/Caddyfile /etc/caddy/Caddyfile
sudo caddy validate --config /etc/caddy/Caddyfile
sudo systemctl reload caddy
sudo caddy trust          # trust the internal CA locally (for curl over https on the Pi)
```

## Trusting the internal CA (why devices show "Not Secure")

Caddy signs the site cert with its own **internal CA**, which no device trusts
by default. Each device must install and trust the CA **root** certificate
once. The root lives on the Pi at:

```
/var/lib/caddy/.local/share/caddy/pki/authorities/local/root.crt
```

> **The CA regenerates whenever the caddy data dir is wiped — i.e. on any SSD
> rebuild/reflash.** After a rebuild every device shows "Not Secure" again and
> must re-trust the *new* root. (This bit us on the 2026-07-12 rebuild.)

### Get the root off the Pi

It is root-owned, so copy it somewhere world-readable first, then pull it:

```sh
# on the Pi:
sudo cp /var/lib/caddy/.local/share/caddy/pki/authorities/local/root.crt /tmp/kingfisher-root.crt
sudo chmod a+r /tmp/kingfisher-root.crt

# on your workstation:
scp eric@kingfisher:/tmp/kingfisher-root.crt .
```

Then get `kingfisher-root.crt` onto each device (AirDrop, email, USB, a web
download — it's a public certificate, not a secret).

### iOS / iPadOS (the EFBs) — two steps, both required

1. Open `kingfisher-root.crt` on the device → **Settings → General → VPN &
   Device Management → Install** the profile.
2. **Then also enable full trust**: **Settings → General → About →
   Certificate Trust Settings** → toggle the "Caddy Local Authority" root
   **on**. Without this second step iOS installs but does **not** trust the CA,
   and Safari/EFB apps still reject HTTPS.

### macOS

Double-click the `.crt` → Keychain Access → add to the **System** keychain →
open it → Trust → **Always Trust**. (Or on the Pi itself, `sudo caddy trust`
already handles the local trust store.)

### Android

**Settings → Security → Encryption & credentials → Install a certificate → CA
certificate** → pick the file. Some apps ignore user CAs; browsers honour it.

### Linux workstation

```sh
sudo cp kingfisher-root.crt /usr/local/share/ca-certificates/kingfisher-root.crt
sudo update-ca-certificates
```

## Access control (app-enforced, AP-scoped)

**Enforcement lives in kingfisher, not Caddy** (see `internal/web/access.go`).
kingfisher binds `127.0.0.1:8080` (loopback), so Caddy is the sole ingress — a
public bind would let AP clients skip the gate by hitting `:8080` directly.
Caddy just terminates TLS and passes the real client IP:

```caddyfile
reverse_proxy 127.0.0.1:8080 {
    header_up X-Real-Client-IP {remote_host}
}
```

`{remote_host}` is the TCP peer and `header_up` overwrites any client-sent
value, so the IP kingfisher trusts cannot be spoofed.

Gated paths (return `403` for untrusted AP clients):

| Path | Why it's gated |
|---|---|
| `/terminal*` | browser root shell (page) |
| `/api/terminal/*` | its login, challenge, and PTY WebSocket |
| `/api/power/*` | `POST /api/power/off` is unauthenticated poweroff |
| `/api/access*` | the trusted-device management API itself |

The **only untrusted network is the open kingfisher AP** (`config.access.ap_subnet`,
default `192.168.10.0/24`), so the gate restricts *only there*: those paths are
blocked for AP clients whose IP is not in `config.access.trusted_ips`. Everything
**off** the AP is always allowed — loopback, the home LAN over `wlan1`, and any
future Tailscale peer — so no home subnet is hardcoded and it survives a network
change. The EFBs (`192.168.10.158`, `192.168.10.230`) are seeded trusted because
in the aircraft `wlan1` is down and the pilot's tablet is the sole external
control surface (the cockpit power-off button posts `/api/power/off`).

**Managing trusted devices:** in the cockpit UI, **More → Trusted devices** lists
the devices on the AP (from `/proc/net/arp`, filtered to the AP subnet) and lets
an already-trusted device grant/revoke each and give it a friendly name (the ARP
table has no hostname). Names and the trusted list persist in
`~/.config/kingfisher/config.json` under `access` — no config editing or Caddy
reload.

**Accepted limitations** (threat model, Appendix A): same-L2 IP spoofing defeats
this; and because only the AP is guarded, any non-AP network `wlan1` joins is
implicitly trusted for these paths.

Verify (uses the Pi's own AP address `192.168.10.1`, not a trusted device, as a
stand-in stranger):

```sh
curl -sk https://127.0.0.1/terminal -o /dev/null -w '%{http_code}\n'                              # off-AP → not 403
curl -sk --interface 192.168.10.1 https://192.168.10.1/terminal -o /dev/null -w '%{http_code}\n'  # AP stranger → 403
```

## The wlan1 (home-LAN) address

The `Caddyfile` lists `192.168.86.151`, the Pi's wlan1 address, as a **site
address** so Caddy serves TLS on it over the home LAN. It is DHCP-reserved on
the home router (by the wlan1 MAC), so it stays put; if it ever changes, update
only the two site-address lists. mDNS names (`kingfisher.lan`, `kingfisher`) are
also served and don't depend on the lease.

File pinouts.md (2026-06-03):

# Kingfisher
A Raspberry Pi-based project to gather sensor data for improving flight performance.

## Main Unit Header Pinout
--------------------------------------
|  ICM45686       | GPS              |
--------------------------------------
|  1 3.3V         |  2 5V            |
|  3 SDA (GPIO 2) |  4 5V            |
|  5 SCL (GPIO 3) |  6 GND           |
|  7 GPIO 4       |  8 TXD (GPIO 14) |
|  9 GND          | 10 RXD (GPIO 15) |
| 11 GPIO 17      | 12 GPIO 18       |
--------------------------------------

## GPS Pinout
-------
| GND |
| 5V  |
|     |
|     |
| RXD |
| TXD |
|     |
-------
Other side of board: PPS

### Notes:
* Enable UART0 (GPIO 14/15) on RPI5 with `/boot/firmware/config.txt: dtoverlay=uart0-pi5`
* GPIO 18 (physical pin 12) is the PPS input with `dtoverlay=pps-gpio,gpiopin=18`

## ICM45686 Pinout
-------
| VCC |
| GND |
| SCL |
| SDA |
|     |
|     |
| INT |
------- 

### Notes:
* Supports 8K FIFO buffer (default is 2K, extend to 8K by disabling APEX: SS 2.4)
* FIFO has 20-bit data format for high resolution
* Digital filters for sensors
* 1 MHz I2C
* User-configurable internal pull-up/pull-downs
* User-configurable ODR & FDR (FIFO Data Rate)
* GPIO 17 (physical pin 11) is the INT for the ICM45686 (GPIO 17 is the default in the driver).

## Case
* PLA+ not good for temp, PETG a little better, ASA might be optimal

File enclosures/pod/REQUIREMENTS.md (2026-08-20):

# Wing pod v3 — non-negotiable requirements

Source of truth for agents and humans editing `wing_pod_v3.py`.
After any geometry change: regenerate, then run `validate_pod.py` (must exit 0)
before calling an STL print-ready.

```bash
cd enclosures/pod && uv run --project .. python wing_pod_v3.py
cd enclosures/pod && uv run --project .. python validate_pod.py
```

## P0 — Build volume (governing constraint)

**This is the requirement that decides every other length in the design.** It
was only implicit in v2, and the cost of leaving it implicit was a 12 mm tail.

| ID | Requirement |
|----|---|
| P0 | Every printed part fits the **AnkerMake M5C** build volume **220 × 220 × 250 mm** with ≥10 mm margin in X/Y for skirt/brim — a rotated AABB of **210 × 210 × 250**. Body halves print flange-down and may be rotated **45° about Z**, so for a half of length `L` and height `H` the governing inequality is `(L + H)/√2 ≤ 210`, i.e. **`L + H ≤ 297 mm`**. Asserted at import and re-checked per exported solid. **Do not buy bed fit by silently shortening the nose or tail** — re-proportion the section, or split the part and say so. |

v2: 216 + 77 = 293 (and a 12 mm tail). v3: 235 + 61 = 296, 45° AABB 209.3 mm.

## Envelope & aero

| ID | Requirement |
|----|---|
| A1 | Overall **~235 × 52 × 61 mm** (L×W×H); asymmetric about the seam (thin left cover, wider right for the electronics land). `OUTER_H` is set by the battery pocket between the flange rails (see L1), `OUTER_W` by the board land. |
| A2 | The **entire outer mold line is ONE loft over ONE parametric section family** (`section_wire`). Nose, midbody and boattail are stations of that family. There is no `mid ∪ nose ∪ tail` fuse and there must never be one again. |
| A3 | Nose fairing ≥ **0.8 × D_eq**, boattail ≥ **1.1 × D_eq**. Nose mouth fairs into the SUN **Ø10.65 smooth barrel** with a print-durable lip (`NOSE_LIP_WALL` ≥ 1.5 mm radial — 0.7 mm PETG tore on the left half). Tips sit **on the seam**; v2 had to hold them off it to keep an OCCT fuse alive, and that constraint is gone. |
| A5 | **No planar freestream-facing butt** anywhere. This now holds *by construction*: the section laws are C1 (`_nose_law` has f'(1)=0, `_tail_law` has g'(0)=0), so the fairing↔midbody joins have no slope step to create one. |
| A6 | **Flat top** for the wing-fairing mate, running the full length aft of the nose: real chord width, genuinely planar (validated as planar faces at `z = OUTER_H`, not merely "near" it). Top edge may be square; a ~1.2 mm radius is kept so OCCT never sees a zero-length arc. |
| A7 | **Flat bottom** forward so the pod stands upright; the boattail sweeps it up. Bottom↔side edge carries an aero radius (`BOTTOM_EDGE_R`) that is **section-native** — a corner radius in the wire, not a post-hoc fillet. v2 disabled it entirely because a fillet would not fuse with the ogives. |
| A8 | Both halves reach a real nose tip (xmin ≈ 0). |
| A9 | Tail tip stays **fused** to each half (xmax ≈ `OUTER_L`); no dropped scrap, no flat nub. |
| A10 | The OML is **C1-continuous**: max slope jump across the section laws < 0.06. Validator samples 2000 stations. |
| A11 | Max boattail surface angle to the freestream ≤ **12°**. Each of the three tapers (left side, right side, bottom upsweep) is budgeted separately — a *proportional* split loads ~12 mm of the 15 mm width reduction onto the +Y side alone and measures 13.2°. |
| A12 | Report and bound **fineness ratio** (≥ 3.70) and **base/frontal** (≤ 0.70). Current: 3.71 and 0.61. Fineness is payload-limited, not shape-limited — `OUTER_H` is the 50 mm battery and `OUTER_W` is the board land. |

## Shell seal

| ID | Requirement |
|----|---|
| S1 | The closed L+R cavity has **no freestream openings** except: (1) Prandtl/SUN tip mouth, (2) multi-hole static array into the isolated BMP bay, (3) the **aft service panel** opening and its cluster cuts, (4) the **labyrinth drain**. **Nothing pierces the +Y skin except the static array** — the service cluster moved to the aft face precisely so the side skin has no cutouts and no local pad. No exterior battery door: the pack goes in from the open mating face before close-up. |
| S2 | Mating faces seal with an O-cord in the right-half groove and/or RTV on the flange. The groove **hugs the skin** (`WALL + GASKET_W/2`) so the battery notch cannot reach it. |
| S3 | Static-port holes open **only** into an isolated BMP plenum, formed by a **separate cup** (`static_bay.stl`) that seals to a flat land on the +Y wall with a foam/RTV gasket and four M2.5 into inserts (Qwiic gland in the cup). The BMP mounts and its inserts are heat-set on a **completely open wall** before the cup goes on. Integral walls plus a service window cannot do both jobs: the window must pass a heat-set iron yet leave a sealing frame, and at that board size it does neither — all four BMP bosses ended up behind the frame and the cover screws landed inside the board footprint. |
| W1 | **Minimum wall.** Stepping inward from the outer skin by `0.55 × WALL` along the surface normal must land in material at every sampled point, except inside a declared S1 opening. This is the direct gate on the v2 failure. |

## Interior must stay interior

| ID | Requirement |
|----|---|
| I1 | Flange rail, pitot bulkheads, electronics land, standoffs and static-bay walls are **intersected with the outer envelope** before union. No locating nubs as a board mount. |
| I2 | Built halves must not protrude outside `full_body_solid(0)` (extra volume ≈ 0). |
| I3 | Board mounts, static bay and static holes exist **only on `pod_right`**; left is cover + pitot cradle. Clamshell: heat-set inserts in the **right** flange; clearance + counterbore through the left. **Aft-panel inserts are also right-side only** — an insert boss runs along X and would straddle the seam if placed near y=0, so all four sit at y ≥ 5.5 and the flange runs aft to `OUTER_L − 6` to hold the left tail. |
| I4 | Mating face stays **open for install**, and the validator samples the cover's bay plus the battery and SUN insertion volumes to prove it. Every other check looks for *missing* material or material *outside* the envelope; none of them notices unwanted material sitting in the cavity. The flange is a **perimeter rail + local screw bosses**, not a bulkhead across the bay. |
| I5 | Boards **wall-mount** on the right +Y inner skin (XZ plane) on **raised standoffs** (PCB not flush on the land). Standoff/insert axes are **±Y** so heat-set irons enter from the open mating face — no floor posts in wells. |
| I6 | Each board's **3-D keepout** stays inside the cavity and clear of neighbours, the battery and the cradle, with `BOARD_GAP` between columns. **Every separately-printed part must also fit where it sits**: `pm_tray`, `static_bay` and `tail_panel` are built in assembly position and intersected against both halves. A part that is in neither half cannot foul either half until something checks — which is how `pm_tray`'s rim came to overlap the wall land by 1 mm. |
| I7 | **Every insert pilot must be physically reachable by a heat-set iron.** The validator sweeps a Ø`BOARD_POST_D` corridor along the iron's path — from the open mating face to the pilot for seam-access inserts — and fails if anything is in it. `insert_inventory()` in the model is the explicit list of all 44 inserts and the axis each is entered on. This is not a geometry property: the old static bay was a perfectly valid, watertight solid whose −Y frame simply left no corridor to the BMP's four pilots. Aft-panel inserts are entered from outside the base and are free by construction. |
| I8 | **Every board** mounts with M2.5 screws into heat-set inserts on standoffs (`STANDOFF_H` ≥ 4 mm), ≥2 insert positions each. The validator **fails** an empty `holes=[]` — that skip is how v2's wall-mount rework silently dropped the Pro Micro's fasteners. |

## Print / export (AnkerMake M5C)

| ID | Requirement |
|----|---|
| P1 | Each of `pod_left.stl`, `pod_right.stl`, `tail_panel.stl`, `static_bay.stl`, `pm_tray.stl` is a **single solid**. |
| P2 | Each STL is **watertight** (zero boundary edges after tessellation). |
| P3 | Tessellation tight enough for P2 (`tol ≤ 0.03`, `ang ≤ 0.05`). |
| P4 | Body halves export **flange/mating-face down**, curved outer up, **rotated 45°** for the bed diagonal. Signs are per-side; v2 shipped them swapped once and printed the flange on top. |
| P5 | SUN-B protrudes **45 mm** and is stopped by the Ø10.65→Ø11.76 step on the nose bulkhead's aft face. The aft pin must not bottom in the cup before that step seats: `SUN_RECESS_BOSS_LEN` ≤ cup depth − 2.5 mm (print-1: 0.5 mm extra was ~2 mm too long). |
| P6 | **All printed-joint screws** (clamshell, board, tray, static cover, aft panel) are **M2.5 into heat-set inserts** with **screw relief deeper than the insert**. No self-tap into PETG. LED holders use their own jam nuts. CAB-15464 USB ears are **M3 through-holes Ø3.3 + nuts behind the plate**. Rocker is snap-in. |
| P7 | Nose lip survives print/handling (`NOSE_LIP_WALL` ≥ 1.5 mm). |
| P8 | `static_bay.stl` is a single watertight solid, and prints **closed face down** so its flange tabs are a short overhang rather than a 29 mm bridge. |
| P9 | `pm_tray.stl` is a single watertight solid. |
| P10 | `tail_panel.stl` is a single watertight solid and prints flat, no supports. |

Slicer settings live in [`PRINT_RECIPE.md`](PRINT_RECIPE.md) — not in the STLs.

## Layout & pneumatics (do not silently change)

| ID | Requirement |
|----|---|
| L1 | Battery **68.5 × 5.9 × 49.3 mm** (X×Y×Z), **measured** 2026-08-18 ([`BATTERY_CALIPERS.md`](BATTERY_CALIPERS.md)) — **laid down**, not standing. Leads exit the **aft** edge, the only one with more than 2.5 mm of clearance. Y is thin across the seam. Pocket adds 1 mm/side in X/Y and 0.5 mm/side in Z. **The pocket must clear the flange rails**: usable height is `OUTER_H − 2×(WALL + BATT_SEAL_KEEP)`, and that inequality is what actually sets `OUTER_H`. The pocket notches interior material only and never reaches the sealing land or a screw boss. |
| L2 | Pitot: **ESA SUN-B**, protruding **45 mm**, clamped on its **Ø11.76 threaded band** — the feature ESA put there for mounting. Caliper ODs are the source; printed bores add per-station FDM allowance (print-1: 0.20 mm radial slip was OK on the aft barrel; 0.08 mm on the clamp was far too tight). |
| L3 | SUN aft barb → pitot → MS4525 `+`; middle → static → MS4525 `−`; forward TE capped. Multi-hole **skin** array → isolated BMP581 bay only, positioned at **40–60 % of body length** where a side port reads closest to freestream. |
| L4 | SUN barbs: **6 mm ID** hose → COTS reducer → MS4525 3/32″ ID (~2.38 mm). |
| L5 | Hose/Qwiic/USB **routes are a layout aid**, not geometry. `build_routes()` names every run and the assembly render draws them, so each one is shown to have somewhere to go before the pod is closed; the long runs use the corridor at y≈5–15, clear between the battery on the seam and the boards on the wall. `build_routes()` polylines are drawn in the QC PNGs and cut nothing, so the validator does not pretend to test them against real solids — v2's L5 check compared imaginary routes with real geometry. If a route ever needs real clearance, cut it and say so here. |
| L6 | Service cluster **locked and on the aft face**, on `tail_panel.stl`: SparkFun **COM-08837** rocker (E-Switch R1966A, snap-in **19.6 × 13.0** for a 2.0–3.0 mm panel — plate is 3.0 mm, no rebate), SparkFun **CAB-15464** Micro-B (10.5 × 7.5 window, M3 ears at **17 mm**, through-holes + nuts, RTV under the flange), two **Ø8.2 mm** holes for 5 mm chrome ABS LED holders. Stacked in Z: rocker high, USB centre, LEDs low. Switch → Babysitter **SYSOFF** (JP12 + GND); red LED = VOUT; blue = `!CHG!`. |
| L7 | SparkFun Pro Micro has **no OEM mounting holes**. It sits in `pm_tray.stl`, screwed to M2.5 insert standoffs. The tray's retaining rim runs in **-Y**, away from the wall — the board drops in from the open mating face. A rim running +Y retains nothing and fouls the land it bolts against. |
| L8 | **Labyrinth drain** at the aft end of the flat bottom (the cavity low point), clear of the battery and the flange rails: cavity → floor-level slot in the aft end wall → channel → down through the skin. No straight path from freestream to interior. |

## Process for agents

1. Read this file and `pod_enclosure.md` before editing.
2. Prefer changing params over inventing a new section family.
3. **Never** rebuild the OML as a union of separate solids. If the shape must
   change, change `section_params` / the scale laws.
4. After regen: `validate_pod.py` green; unique preview PNG name per revision.
5. Do not call STLs print-ready unless validate exits 0.
6. **Printed artifacts (`.stl` / `.step`) are committed only once the parts
   have been printed and checked**, and only with the user's explicit
   agreement for that commit. A green validator is not sufficient: every
   printed revision so far passed validation and still had defects that only
   the physical part revealed. The QC PNGs are small and meaningful, so they
   travel with the code. **P11** flags any STL not built from the current
   `wing_pod_v3.py`, so artifacts lagging the script is visible rather than
   silent. Verify reproducibility before an artifact commit: a fresh run must
   reproduce the STLs byte-for-byte.
7. Enclosure-only work stays on `master` (no PR) unless the user asks otherwise.

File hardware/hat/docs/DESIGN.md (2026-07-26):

# Kingfisher Sensor HAT — design notes (rev 0.2)

## Goals

Replace the rear-bay SparkFun NEO-M9N + ICM-45686 breakouts (and ribbon) with a
single board that plugs onto the **extra-tall GPIO header** protruding through
the official M.2 HAT+. Lower profile than the IDC ribbon connector.

CO sensing is **out of scope** (separate cabin CO monitor). Pod SHT45 humidity
is a later pod change, not on this HAT.

## Stack fit

```
X1200 UPS → Pi 5 → Active Cooler → M.2 HAT+ → [extended GPIO pins +9 mm]
                                              → this HAT (female socket on bottom)
```

Constraints from `enclosures/x1200_m2hat_stack.md`:

- Pins above M.2 HAT top: **9.0 mm**
- Current IDC ribbon stack: **~19.4 mm** above HAT — we must stay under that
- Corner M2.5 bolts currently start at M.2 HAT top; HAT may need longer bolts
  or light pin-only seating for v1 prototypes
- **CR2032 holder height** (Keystone 3002 ~5–6 mm above PCB) must clear the
  case lid — verify in cardboard/3D mockup before fab

**Action before fab:** 3D-print or cardboard blank with chosen female header
and confirm engagement + lid clearance (especially BT1).

## Electrical map (matches `pinouts.md`)

| Pi header | Net | Destination |
|---|-----|---|
| 1 | +3V3 | ICM, BMP581, RV-3028 |
| 2, 4 | +5V | AP2112K VIN |
| 3 | SDA | ICM + BMP581 + RV-3028 |
| 5 | SCL | ICM + BMP581 + RV-3028 |
| 6, 9, … | GND | common |
| 8 (GPIO14 TXD) | UART_TX | NEO RXD |
| 10 (GPIO15 RXD) | UART_RX | NEO TXD |
| 11 (GPIO17) | IMU_INT | ICM INT1 (active-low in DT) |
| 12 (GPIO18) | GPS_PPS | NEO TIMEPULSE |

All other GPIO pins are passed through the 40-pin socket (X1200 fuel gauge
`0x36` and PLD GPIO6 remain available on the bus).

### I²C addresses (cabin bus 1)

| Addr | Device | Notes |
|---|---|---|
| `0x36` | X1200 MAX17040 | existing UPS |
| `0x47` | BMP581 | SDO=1 |
| `0x52` | **RV-3028-C7** | RTC (not DS3231) |
| `0x68` | ICM-45686 | AP_AD0=0 |

**Why not DS3231?** Stock DS3231 is almost always at **`0x68`**, which collides
with the ICM. Moving the ICM to `0x69` (AP_AD0=1) is possible but forces a
device-tree / software change for no gain. Micro Crystal **RV-3028-C7** is a
common low-power I²C RTC at **`0x52`**, has a dedicated `VBACKUP` pin, and is
already in the KiCad symbol library with a SON-8 footprint.

DTO overlay (software follow-up): `dtoverlay=i2c-rtc,rv3028` (or equivalent
for the Pi 5 I²C-1 bus). Gives wall-clock before GPS/chrony lock; chrony/PPS
remain the in-flight truth once locked.

### Sensor strap notes

- **ICM-45686:** AP_CS → +3V3 (I²C mode); AP_AD0 → GND (`0x68`); 100 nF on VDD and VDDIO.
- **BMP581:** CSB → +3V3 (I²C); SDO → +3V3 (`0x47`); INT → GND (unused); 100 nF on VDD/VDDIO. No vias under package (Bosch).
- **RV-3028-C7:** VDD → +3V3; VBACKUP → **VBAT** (direct, no diode — RTC expects the cell); SCL/SDA on bus; INT/CLKOUT/EVI unused (NC or test pad).
- **NEO-M9N:** VCC from +3V3_GPS; **V_BCKP from diode-OR** (not tied to VCC); D_SEL open (UART+I2C); TIMEPULSE → PPS; RF_IN → U.FL. Follow u-blox integration manual for RF keepout / GND.

## Power

- Digital sensors + RTC on Pi **+3V3**
- GPS on dedicated **AP2112K-3.3** from Pi **+5V** (same approach as SparkFun M9N breakout; avoids starving the Pi 3V3 rail)
- LDO input/output caps per AP2112 datasheet (1 µF class)

## Backup power (CR2032)

### Cell choice: CR2032 (not CR1220)

| | CR2032 | CR1220 |
|---|---|---|
| Typical capacity | ~220 mAh | ~35–40 mAh |
| Holder | Keystone **3002** (common HAT part) | smaller, less common |
| Height | taller (~5–6 mm holder) | lower profile |
| Retention | years at µA loads | months–~1 year depending on GPS backup draw |

**Pick CR2032:** GPS `V_BCKP` + RTC backup are both microamp-class, but we want
multi-year cold-cabin / hangar storage without babysitting a tiny cell. Height
is the trade-off — check lid clearance. Replaceable holder (not soldered tab
cell) so the pilot can swap without desoldering.

### Topology (SparkFun-style, primary cell)

```
                 BAT54 D1
  +3V3_GPS ──|>|──┐
                   ├── V_BCKP ──► NEO-M9N pin V_BCKP
  VBAT ──────|>|──┘
         BAT54 D2

  VBAT ──────────────► RV-3028 VBACKUP
  BT1 CR2032 (+) = VBAT, (−) = GND
```

- **Do not** tie NEO `V_BCKP` to `VCC` — that loses ephemeris/RTC state on every
  power-off (the failure mode of a naive breakout clone).
- **Do not** provide a charge path into the CR2032 (primary LiMnO₂). Schottky
  OR from `+3V3_GPS` only *supplies* `V_BCKP` when the rail is up; when the rail
  is down, the cell feeds `V_BCKP` through D2. RTC `VBACKUP` is fed from `VBAT`
  directly (chip isolates internally).
- SparkFun’s NEO-M9N board uses a similar diode-OR (cell/supercap vs VCC). We
  prefer a **replaceable cell** over a supercap for hangar-week retention
  without a charge circuit.

### Current draw / retention (order-of-magnitude)

| Load | Typical | Source |
|---|---|---|
| NEO-M9N `V_BCKP` | ~15 µA (backup mode) | u-blox NEO-M9N datasheet (backup supply) |
| RV-3028 timekeeping on `VBACKUP` | ~45 nA | Micro Crystal datasheet |
| Combined (power off) | **~15 µA** | dominated by GPS |

CR2032 ~220 mAh → **~220e3 / 15 ≈ 14 000 h ≈ 1.6 years** continuous backup at
that draw (ideal; self-discharge and cold reduce this). In practice the aircraft
is powered often enough that calendar life / self-discharge dominate — still
plan on **annual cell check** at annual / condition inspection.

## PCB

- Outline: KiCad Raspberry Pi HAT template
- Copper: **4 layers** (RF / return for GPS)
- J1: pin socket on **bottom** copper (already in template)
- Major parts placed in rev 0.1; **routing TBD**; place BT1 / U5 / D1–D2 next

Suggested placement:

| Part | Approx. location |
|---|---|
| J1 | GPIO edge (template) |
| U1 ICM | near mid-left |
| U2 BMP581 | near mid-right |
| U4 NEO | center |
| J2 U.FL | toward outer edge for pigtail |
| U3 LDO | near GPS |
| U5 RTC | away from RF / near I²C |
| BT1 CR2032 | board edge, lid-accessible, clear of antenna |

Silk: mark ICM +X/+Y/+Z to match AHRS convention (verify against package pin-1 and TDK figure before fab).

## BOM notes (backup / RTC deltas)

| Ref | Value | Footprint / notes |
|-----|---|---|
| U5 | RV-3028-C7 | `Package_SON:MicroCrystal_C7_SON-8_1.5x3.2mm_P0.9mm` |
| BT1 | CR2032 (cell) | holder `Battery:BatteryHolder_Keystone_3002_1x2032` |
| D1, D2 | BAT54 | SOD-123 (or BAT54C dual if layout prefers) |
| C8 | 100 nF | RTC VDD decouple |

Do **not** populate a charging resistor/IC for BT1.

## What else along these lines? (resilience shortlist)

Given **X1200 UPS already present**, **chrony + PPS already in software**, and
tight stack/lid height, only add HAT features that earn their keep.

### Recommend (ship or leave pads)

| Item | Verdict | Why |
|---|---|-----|
| **I²C pull-ups (2×2.2–4.7 kΩ to +3V3)** | **Yes if bus needs them** | Pi usually has onboard pull-ups; with X1200 + HAT + ribbon history, measure SCL/SDA rise time. Prefer **DNP** footprints so we can populate only if the stack is flaky. |
| **Test points** | **Yes** | TP for `+3V3`, `+3V3_GPS`, `VBAT`, `V_BCKP`, SDA, SCL, UART_TX/RX, PPS, IMU_INT. Cheap, saves debug time in the aircraft. |
| **Power-good LED (Pi +3V3 or GPS 3V3)** | **One LED, optional** | Single green on `+3V3_GPS` (or +3V3) with ~1–2 mA resistor — confirms HAT power without a scope. Skip per-rail LED forest. |
| **SAFE_BOOT / nRPI_BOOT test pad** | **Pad only** | Handy if the stack bricks boot; no connector needed — just a labeled pad to GND. |
| **Series R on UART (22–100 Ω)** | **Optional DNP** | Helps edge-rate / EMI if the GPS UART rings; start without, add footprints if layout allows. |
| **HAT ID EEPROM (CAT24C256)** | **Keep template footprint, DNP OK** | Template already has it. Useful for `hat_map` / inventory; not required for kingfisher software today. |

### Skip

| Item | Why skip |
|---|---|
| **Second hardware watchdog** | Pi + systemd + X1200 cover brownout/reset; another WDT on the HAT is complexity without a clear failure mode. |
| **IMU / GPS “activity” LEDs** | Clutter, current, and no pilot value in a closed case; use the cockpit UI. |
| **Supercap on V_BCKP** | CR2032 diode-OR already covers hangar retention; supercap needs charge path and dies in days–weeks. |
| **Rechargeable ML-type cell** | Charge circuitry + aviation preference for primary coin cells you can swap dry. |
| **Separate RTC coin cell + GPS coin cell** | One CR2032 is enough at ~15 µA; two holders burn lid space. |
| **Extra baro / humidity on HAT** | BMP581 is enough for cabin pressure altitude; humidity deferred to pod. |
| **CO sensor** | Cabin CO monitor already exists. |

## Software impact (after hardware)

- ICM: existing `icm45686` overlay / kingfisher path — unchanged at `0x68`
- GPS: existing `uart0-pi5` + `pps-gpio,gpiopin=18` — unchanged; backup battery improves cold-start TTFF after power cycles
- BMP581 cabin: **new** — Linux IIO or userspace reader; altitude derive already has cabin pressure fallback
- RTC: **new** — `i2c-rtc` / `rv3028` overlay so the Pi has time before GPS lock; chrony remains primary when locked

## Fab checklist (later)

- [ ] Female header part number chosen for 9 mm pin engagement
- [ ] Lid clearance for Keystone 3002 + cell
- [ ] ERC / DRC clean (tidy label–pin wires in eeschema)
- [ ] u-blox RF review (short RF_IN, continuous GND, no cutouts under module)
- [ ] Place BT1, U5, D1/D2, test points; route
- [ ] JLCPCB: ICM + BMP581 + RTC + passives SMT; NEO module availability check
- [ ] Order 5 boards

## Schematic toolchain note

`scripts/build_sch.py` embeds symbols into `lib_symbols`. KiCad unit children
must keep the **short** name (`Name_0_1`), not `Lib:Name_0_1` — the latter
makes `kicad-cli` fail with “Failed to load schematic”. Regenerate with:

```bash
python3 hardware/hat/scripts/build_sch.py
kicad-cli sch export netlist hardware/hat/kingfisher-hat.kicad_sch
```

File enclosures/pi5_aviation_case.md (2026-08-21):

# `case/pi5_aviation_case.py` — hub enclosure script notes

Parametric CadQuery model of the cabin "hub" enclosure. **v3** (2026-07-17)
houses the full stack: Geekworm **X1200 UPS** (18650s down) → Raspberry **Pi 5**
(pogo-pin powered) → Active Cooler → official **M.2 HAT+** on 16 mm standoffs →
IDC ribbon connector on extended GPIO pins — plus the SparkFun NEO-M9N GPS and
ICM-45686 IMU in a rear bay. One script generates `case_base.{step,stl}`,
`case_lid.{step,stl}` (print-oriented, flipped), and `case_assembly.step`.

- Printer/material: AnkerMake M5C, PETG. Fasteners: M2.5 heat-set inserts
  (bay + lid posts); the stack mounts on its own metal standoffs (below).
- Outer envelope: **97.0 × 113.1 × 76.2 mm** (base 72.2 + lid 4).
- Hardware measurements + mounting rationale: **`x1200_m2hat_stack.md`**.
- Archives: `KingfisherCase.zip` = v1, `KingfisherCase2.zip` = v2 as printed
  (85×112×35, Pi + bay only, incl. the old `relief.png` render),
  `KingfisherPod.zip` = wing-pod **v1** insert (archived). Live pod model:
  [`pod/wing_pod_v3.py`](pod/wing_pod_v3.py) / [`pod/pod_enclosure.md`](pod/pod_enclosure.md).
- **OLED lid (2026-08-21):** SparkFun Qwiic OLED 1.3″ (LCD-23453, 128×64) recessed
  in the lid rear over the GPS bay, facing up, with a GPIO button to the +X
  side of the panel (toward the IMU). QC preview: `case/case_lid_oled_qc_20260821.png`.

## OLED lid IDs

| ID | Requirement |
|---|---|
| O1 | Viewing aperture ≥ active area 29.42×14.7 mm + 1 mm (`OLED_WIN_CLR`) |
| O2 | Underside pocket for PCB 41.0×27.5 mm (datasheet panel 34.5×23.0; **caliper-tune `OLED_PCB_*` before print**) |
| O3 | Qwiic cable slot into the GPS bay; do not pinch on lid close |
| O4 | Tactile button hole Ø7.2 mm, +X of the PCB (toward the IMU), clear of lid posts and flank vents |
| O5 | Window must not overlap cooler intake grille (`INTAKE_R`) |
| O6 | Keep flanking 3×22 mm exhaust slots left/right of the bezel |
| O7 | 1.5 mm visor around the window (cabin glare) |

Wiring: daisy-chain Qwiic from the SparkFun NEO-M9N in the bay (cut the OLED I²C pull-up jumper). Button is GPIO4 / pin 7 to GND pin 9 (active-low).

## Regenerating

Python deps are managed with **uv** (workspace member `enclosures/`, CadQuery
2.8.0; see [`docs/python.md`](../docs/python.md)):

```bash
uv sync --all-packages   # from repo root → ./.venv
cd enclosures/case && uv run --project .. python pi5_aviation_case.py
```

Exports land in the CWD — run from `enclosures/case/` so STEP/STL sit beside
the script.

**nlopt:** `uv sync` currently pulls an `nlopt` wheel (incl. aarch64). If that
ever regresses, the old fallback was a source build into
`~/.venvs/cadquery` (cmake + swig); prefer fixing the lock/wheel first.

## Coordinate system & layout

Origin = outer bottom-left-front corner. X = Pi long axis, Y = depth (stack in
front/low-Y, GPS/IMU bay behind/high-Y), Z = up. `io(x, y)` maps interior →
global coords (adds `WALL`). Interior size derives from contents; **all deck
heights derive from the Z-stack parameters** — `PI_DECK_Z` (Pi PCB top) is the
master deck that wall cutouts follow automatically.

```
Z-stack (abs mm): floor 3 → pads 5 → [20 standoffs] → X1200 25..26.6 →
  [4.5 pogo spacers] → Pi 31.1..32.7 → cooler →46.7 → HAT 48.7..50.3 →
  IDC ribbon conn →69.7 → headroom → lid underside 72.2
```

Top view: unchanged from v2 — stack forward, bay (GPS left, IMU right, SMA
bulkhead low on the +X wall) behind a 4 mm gap.

## Stack mounting (no inserts)

Four M2.5 M-F **20 mm standoffs** thread into the X1200's threaded bosses from
below; M2.5×20 screws clamp Pi + pogo spacers from above; **case screws
(M2.5×8 pan) come up from outside the floor** through counterbored holes in
Ø11×2 raised pads, into the standoffs' female ends. Bottom face stays flat for
Dual-Lock. Scheme proven by Printables model 1288473 (same stack) and
Geekworm's X1200-C1 case. Loose standoffs → poor pogo contact.

## Parameter groups (v3)

| Group | Key params | Notes |
|---|---|---|
| Shell | `WALL=3`, `LID_T=4` | `WALL_H`/`OZ` are now **derived** from the stack |
| Z-stack | `PAD_H`, `UPS_STANDOFF_H=20`, `UPS_UNDERSIDE=18.5`, `POGO_SPACER_H=4.5`, `HAT_STANDOFF_H=16`, `IDC_*`, `RIBBON_ON_TOP`, `STACK_HEADROOM=2.5` | `RIBBON_ON_TOP=False` (discrete harness instead of IDC) shortens the case ~10 mm |
| Base screws | `BASE_HOLE_D`, `BASE_CB_D/DEPTH` | counterbored flush from below |
| Clearances | `CLR_L=6` (FPC ribbon bulge + Pi/X1200 buttons), `CLR_F=4.3` (**drop-in past the front lid posts**, was Ethernet-limited), `IO_CLR=0`, `BAY_GAP`, `BACK_CLR` | |
| X1200 walls | `UPSC_*` (front USB-C charge window + interior pilaster → plug seats ~flush), `BTN_*` (left Ø17 finger recess, button ~6 mm inside the face), `LED_*` (left bank slot + Ø3.2 charge-LED light-pipe hole) | back-edge LEDs face the bay interior — unpiped by design |
| Inserts/bosses | `INSERT_*`, `BOSS_D`, `POST_*` | unchanged from v2 (bay pedestals + floating lid posts) |
| Pi/IO | `PI_*`, `USBC_X`, `IO_WIN_*` | I/O window + Pi USB-C cutout track `PI_BOT_Z` |
| Bay | `GPS_*`, `IMU_*`, `SMA_*`, cable clips (`INSTALL_CLIPS=False`) | unchanged from v2; **designed to be deletable wholesale** if a custom GPS/IMU HAT happens later |
| Vents | `INTAKE_*` (lid grille over cooler), `SLOT_W` + `vent_ys` | left-wall slots moved up to cooler level, two groups flanking the FPC keep-out |

## Guard asserts

The script self-checks on every run; keep these healthy when changing params:
cells-off-floor ≥1 mm; counterbore floor ≥2 mm; stack-to-lid headroom ≥2 mm;
FPC ribbon and button overhang inside `CLR_L`; **drop-in**: the assembled
stack lowers past the floating front posts (`PIy0` vs post OD — this is what
pins `CLR_F=4.3`); front-right post vs Ethernet; button hole above the floor;
vent slots outside the FPC keep-out; all v2 bay asserts (GPS↔IMU gap, SMA
position, clip spacing).

## v3 design notes

- The stack is assembled outside the case (standoffs → X1200 → spacers → Pi →
  cooler → HAT standoffs → HAT → pins/IDC), then drops in and is fastened by
  4 screws from below.
- The lid grille sits above the HAT; fan air comes through the lid, around the
  HAT edges, into the cooler; exhaust via left-wall slots at cooler level and
  the (large, open) I/O window.
- microSD access dropped (NVMe boot). Pi USB-C cutout retained for bench use.
- The X1200's fuel gauge (I2C 0x36) + power-loss GPIO run over the user's
  GPIO ribbon — a candidate future kingfisher battery device.
- Charging: X1200 USB-C is 5 V/5 A (2.3–3.2 A charge) — never from the Pi's
  own USB; see the VBUS over-current history in `~/.claude/CLAUDE.md`.
- Bench stack total measured 52.2 vs 53.3 summed — `STACK_HEADROOM=2.5`
  absorbs the disagreement in the safe direction.

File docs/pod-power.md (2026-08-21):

# Pod power protocol

The wing pod's power policy exists to serve one goal: **the stored data is the
product**. No stage ever discards sensor data to save power — low battery
defers delivery; only imminent LiPo damage stops collection.

## Why (assessment, July 2026)

Measured board draw (bq27441, 2026-07-11 flight): **~100 mA** ≈ radio
RX-always-on ~65-70 mA + CPU ~20-25 mA + sensors ~5 mA. 2000 mAh ≈ 20 h.
The retired Phase-4 "sleep" quiesced sensors (losing all data) while leaving
radio + CPU powered — ~10-20% saving for 100% data loss, and its 20% SOC
threshold was sized for the old 750 mAh pack.

Burst-cycle math: reconnect costs ~3 s at ~110 mA per cycle. At 60 s windows
that is +5 mA average on a ~30 mA radio-off floor; longer windows change
little (120 s saves only 2.5 mA more), so window length is a RAM choice, not a
power choice.

| Mode | Draw | 2000 mAh | Last 20% |
|---|---|---|---|
| Live streaming (today) | ~100 mA | ~20 h | ~4 h |
| Burst (radio off between syncs) | ~31-37 mA | ~55-65 h | ~11-13 h |
| Deep sleep (protect) | ~5 µA | — | — |

## The three stages (`firmware/pod/src/power.rs`)

1. **Active** — live streaming, exactly as before.
2. **Burst** — on battery with SOC ≤ `burst_soc_pct` (default 30%; voltage
   fallback `burst_voltage_v_uncalibrated` 3.60 V when FullChargeCapacity does
   **not** match the configured pack), debounced `low_debounce_s` (45 s): the radio is stopped
   (`esp_wifi_stop` via `radio.rs` — esp-radio 0.18 has no public stop/start;
   its event-driven state machine stays coherent with the raw calls). Sensors
   keep sampling at full rate into `burst.rs` — compact per-sensor rings
   (~149 KB .bss) sized for 50 Hz mag/static over one `burst_window_s`
   (default 60 s). Each window (or early at 90% ring fill) the radio comes up,
   the backlog drains as normal wire batches, and the radio goes back down.
   Ring overflow overwrites oldest and is counted in `dropped_readings`.
   Hysteresis +5% SOC / +0.05 V to return to Active; charging returns
   instantly.
3. **Protect** — voltage ≤ `protect_voltage_v` (3.50) or (only if FCC matches
   the configured pack) SOC ≤ `protect_soc_pct` (5%), debounced; immediate below 3.40 V:
   final drain + Status, then true deep sleep. `gauge_trusted` compares live FCC
   to the **configured pack**, not chip 0x3C — a factory 1340/1340 leftover must
   not SOC-trip Protect on a 2000 mAh pack (voltage floors still apply). Healthy
   voltage (above burst + 0.05 V) leaves Protect even if charging current has
   tapered off.

## Wire / Pi contract

No wire-format change. `Status.power_mode` values: 0 active, 1/2 legacy
quiesce-sleep (retired), 3 burst-collect, 4 burst-uplink, 5 protect-pending,
6 protect. Drained batches carry fresh `pod_uptime_us` with per-reading
`age_us`, so the Pi's EMA clock offset stays valid across bursts
(`tsClampPast` is 10 min to admit the backlog).

Pi side (`internal/pod`): burst/protect modes are not staleness-gated in
`LinkStats`; `burst_quiet` marks silence within one window + 90 s as healthy
(chip shows a neutral "burst" state, warn when overdue; "protect" warns).
The pod's `dropped_readings` counter is **no longer re-baselined after quiet
gaps** — since burst mode, anything the pod drops is stored-data loss and must
warn; only a counter reset (pod reboot) re-baselines.

## Modem power-save: verified working — ON in the aircraft config

esp-radio 0.18 has `Controller::set_power_saving(PowerSaveMode::Minimum)`
(unstable feature), set once on first association when
`pod.modem_power_save` is true. An initial bench run looked like the Pi's
brcmfmac AP dropped unicast to the dozing STA (re-Hello every 30 s, SetRate
never applied) — that was actually a pre-existing firmware bug:
`cmd::handle_datagram` did not `touch_inbound` for Ping frames, so the 5 s
keepalive never suppressed the 30 s Hello rediscovery. With that fixed,
power-save ran clean on the real AP (2 min, zero re-Hellos, cmds acked).
The build default stays false (conservative for fresh setups); the aircraft
config sets it true. Expected: ~100 → ~55-65 mA while staying fully live.

## Config (`~/.config/kingfisher/config.json`, `pod` section)

`burst_soc_pct` 30 · `burst_window_s` 60 · `burst_voltage_v_uncalibrated`
3.60 · `protect_voltage_v` 3.50 · `protect_soc_pct` 5 · `low_debounce_s` 45 ·
`modem_power_save` false. All build-time (`build.rs` → `cfg.rs`); the Pi reads
`burst_window_s` for the link-quiet allowance. Replaced: `sleep_soc_pct`,
`sleep_voltage_v_uncalibrated`, `sleep_debounce_s`, `sleep_emergency_voltage_v`.

## Deliberate v1 simplifications

- 60 s f32 rings instead of 5 min compressed: ~3 mA from optimal, no
  quantization layer. Revisit with delta/quantized packing if longer windows
  are wanted.
- Rings assume ≤50 Hz; higher rates shorten the effective window via the 90%
  early-uplink trigger rather than growing buffers.
- No flash-backed store: an AP outage longer than the ring keeps only the
  newest window (counted as drops).

## Bench hazard: charging the pod from Pi USB

Plugging the pod into the Pi's USB with a deeply discharged battery attached
makes the BQ25185 draw its full input current the instant VBUS appears
(charge current + ESP32 load, plus inrush). Under the Pi 5's default 600 mA
downstream budget this trips the RP1's *shared* VBUS over-current switch in a
continuous storm: **every** USB device drops, including a wifi dongle, so the
Pi can look dead while it is running fine (observed 2026-07-15; the 5 V rail
never sagged). The Pi now sets `usb_max_current_enable=1` (1.6 A budget,
5 V/5 A supply required). Even so: detach or pre-charge the battery before
connecting the pod to the Pi, or strap the BQ25185 ILIM ≤ 500 mA.

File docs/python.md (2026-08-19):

# Python tooling (uv)

Kingfisher’s Python side projects use **[uv](https://docs.astral.sh/uv/)** as a
workspace. From the repo root:

| Path | Purpose |
|---|---|
| `pyproject.toml` | Workspace root (`members = analysis, enclosures`) |
| `uv.lock` | Committed lockfile for both members |
| `.venv/` | Shared workspace venv (gitignored) |
| `analysis/pyproject.toml` | Flight DB catalog / health / windows (`numpy`, `matplotlib`, `pyarrow`, `pandas`) |
| `enclosures/pyproject.toml` | CadQuery case models |
| `hardware/hat/scripts/` | Stdlib only — **no** uv project; KiCad/`pcbnew` = apt |

```bash
# Install uv once (also in deploy/system-rebuild-playbook.md)
curl -LsSf https://astral.sh/uv/install.sh | sh

# Sync workspace (analysis + enclosures) into ./.venv
uv sync --all-packages

# Analysis CLI
uv run --project analysis python scripts/analyze_flights.py all

# Enclosure regen (cwd = script dir so STEP/STL land beside the script)
cd enclosures/case && uv run --project .. python pi5_aviation_case.py
cd enclosures/pod  && uv run --project .. python wing_pod_v3.py
```

Do **not** put KiCad’s `pcbnew` module in the uv venv — use Debian/RPi
`python3-pcbnew` for any PCB API scripts.

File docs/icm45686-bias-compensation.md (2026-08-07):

# ICM-45686 bias and temperature compensation

Plan for characterizing IMU bias vs die temperature, then applying a **two-step
correction pipeline** while **always persisting raw sensor readings** and
**logging on-chip offset registers at every startup**:

1. **Step 1 — pre-AHRS IMU bias layer** (two phases, same compensator):
   - **Phase 1a:** first-order temperature correction from characterized TCO/b₀
   - **Phase 1b:** inertial refinement when GPS + IMU indicate stationary
2. **Layer 2 — AHRS slow drift:** online bias states inside the AHRS engine to
   absorb residuals, nonlinearities, and effects Step 1 does not model

Scope: **ICM-45686 first** (cabin hub IMU). Pod and other IMUs follow once this
path is proven.

---

## Glossary

Terms used in the TDK/InvenSense datasheet and app notes:

| Term | Meaning |
|---|---|
| **ZRO** (Zero-Rate Output) | Gyroscope **bias**: the non-zero rate the sensor reports when it is not rotating. Specified as initial tolerance at 25°C and as change vs temperature (°/s/°C). Same idea as “gyro offset” or “zero-rate offset.” |
| **Zero-G output** | Accelerometer **bias**: the output when no linear acceleration is applied (except gravity on the vertical axis). Specified as initial tolerance (mg) and change vs temperature (mg/°C). |
| **TCO** (Temperature Coefficient of Offset) | How much **bias** changes per °C: Δbias/ΔT. For ICM-45686 the datasheet gives **±0.005 °/s/°C** (gyro, board-level) and **±0.15 mg/°C** (accel, board-level). AN-000257 uses TCO in offset budgeting: `offset_over_T = TCO × TempVar`. |
| **TCS** (Temperature Coefficient of Sensitivity) | How much **scale factor** changes per °C (%/°C). ICM-45686: **±0.01 %/°C** for both gyro and accel. Affects apparent bias when the true input is non-zero; usually second-order for our use case. |
| **LDO** (Low-Dropout regulator) | On-chip **voltage regulator** that generates stable supply/reference for the MEMS front end. Datasheet §4.18 “Bias and LDOs” refers to this **power/reference block**, not sensor zero-rate bias. LDO drift with temperature contributes to TCO indirectly but is not user-calibratable. |
| **OFFUSER** | User-writable **on-chip bias trim** registers (`GYRO_*_OFFUSER`, `ACCEL_*_OFFUSER`). Exposed in Linux IIO as per-axis **`calibbias`**. Range ±62.5 dps (gyro) / ±1 g (accel). |
| **BoardVar** | Offset variation from **PCB assembly, mounting stress, and bending** (AN-000257). Partly permanent after install; not captured by die temperature alone. |
| **BalancedGyro** | TDK hardware gyro architecture aimed at low vibration- and temperature-induced rate error; no public equations. |
| **RTC** (Runtime Calibration) | Marketing term for on-chip self-calibration using the internal temperature sensor; details in AN-000478 / factory tools, not fully in the public datasheet tables. |

---

## Background (official specs)

**Datasheet:** DS-000577 (ICM-45686, Rev 1.0). **Related:** AN-000257 (offset
budgeting), AN-000265 (calibration), AN-000478 (user guide), AN-000393 (PCB/assembly).

### Published bias vs temperature (board-level, −40°C to +85°C)

| Sensor | Initial bias @ 25°C | Δ bias / ΔT |
|---|---|---|
| Gyro (ZRO) | ±0.3 °/s (component, production tested) | ±0.005 °/s/°C (characterization) |
| Accel (zero-g) | ±10 mg (component, production tested) | ±0.15 mg/°C (characterization) |

Over a **20°C** cabin/OAT swing: ~**0.1 °/s** gyro and ~**3 mg** accel — small
vs initial offset but meaningful for AHRS integration over minutes if uncorrected.

### Die temperature

On-chip sensor; same formula the driver uses:

```
T(°C) = TEMP_DATA / 128 + 25     (16-bit register / high-res FIFO)
T(°C) = FIFO_TEMP_DATA / 2 + 25  (8-bit FIFO field)
```

Kingfisher already logs `temp_c` on ICM45686 IIO devices via buffered capture.

### What we have today

| Layer | Behavior |
|---|---|
| [`icm45686-mod`](../icm45686-mod) | FIFO + `in_temp_*`; `calibbias` → `OFFUSER` (writable while buffered; OFFUSER shadow across ODR/FS — local OOT) |
| [`internal/sensors`](../internal/sensors) | Publishes **raw** accel/gyro/temp to hub + flight DB; programs OFFUSER from Calibrate Accept without pausing capture |
| [`internal/sensors/attrs.go`](../internal/sensors/attrs.go) | **`calibbias` already in `SnapshotAttrs`** |
| [`internal/sensors/sensors.go`](../internal/sensors/sensors.go) | Full attr snapshot at **startup** → `sensor_attrs` table |
| [`internal/calibrate`](../internal/calibrate) | Cabin accel (6-face) + cabin gyro (still) → OFFUSER + `calibration.cabin_imu` |
| [`calibration.gyro_tco`](analysis/gyro_tco.md) | Piecewise \(\Delta b(T)\); Accept bakes OFFUSER to \(T_\mathrm{ref}\); soft UI peels \(\Delta b\) |
| Soft display | Boldface peels \(\Delta b(T)\) / soft constant bias when OFFUSER flags say so |
| [`internal/derive/ahrs.go`](../internal/derive/ahrs.go) | **SimpleAHRS**, no bias estimation; uses hub samples as-is |

Kernel presents **two** IIO devices: `icm45686-accel` and `icm45686-gyro`. Each
gets its own startup `sensor_attrs` snapshot (including per-axis `calibbias`).

**Gap:** No hub Step 1 compensator / virtual corrected IMU yet (soft UI peel is
display-only); AHRS still uses **SimpleAHRS**, which subtracts gyro bias state
`D1/D2/D3` but **never estimates it online** (unlike goflying **Kalman**
variants). Boot OFFUSER values live in `sensor_attrs` rows — sufficient if
queried; optional one-row metadata summary still nice-to-have.

---

## Goals

1. **Characterize** per-unit bias vs die temperature (lab + historical flights).
2. **Step 1 — pre-AHRS compensator** (single module, two phases):
   - **Phase 1a (temperature):** subtract `bias₀ + k×(T − T_ref)` per axis.
   - **Phase 1b (inertial refine):** when GPS + IMU indicate **stationary**
     inertial windows, nudge runtime trim on top of the temperature model.
3. **Layer 2 — AHRS slow drift:** enable online estimation of residual gyro/accel
   bias inside the AHRS filter (`D` / `C` in goflying) so heading/attitude
   integration is not poisoned by whatever linear temp model and ground cal miss.
4. **Never lose raw data:** flight DB tables keep **uncorrected** IIO values.
5. **Boot audit trail:** on-chip `OFFUSER` / `calibbias` logged on **every**
   kingfisher start (already happens via `SnapshotAttrs`; verify both accel and
   gyro devices, add tests/docs).
6. **ICM-45686 only** for v1; design Step 1 so other IMUs can plug in later.
   Layer 2 follows whichever AHRS provider kingfisher uses.

---

## Phase A — Analyze existing flight logs (starting point)

Before lab work, mine recent flight DBs on the Pi:

### Queries / plots

- **Temperature range:** min/max/mean of `temp_c` (or `temp`) on
  `icm45686_accel` / `icm45686_gyro` / merged `icm45686` tab data during flight.
- **Bias proxies during inertial windows:**
  - Ground/taxi: GPS speed &lt; ~2 kt, small angular rates → gyro mean ≈ bias.
  - Level static on ground: accel magnitude ≈ 1 g; residual after removing gravity
    in known attitude → accel bias proxy.
- **Slope estimate:** linear fit `bias_axis ~ temp_c` per axis; compare |k| to
  datasheet bounds (0.005 °/s/°C, 0.15 mg/°C).
- **On-chip trim at session start:** `sensor_attrs` where
  `attr='calibbias'` for `icm45686-accel` / `icm45686-gyro` at minimum
  `ts_ns` per flight DB.

### Deliverable

Short characterization note (even a section in this doc or a one-off script under
`scripts/`) with:

- Typical in-flight die temp range vs lab target range
- Observed bias stability and crude TCO per axis
- Whether temperature alone explains most drift or BoardVar / other effects dominate

Suggested script: extend [`scripts/analyze_flight_sampling.py`](../scripts/analyze_flight_sampling.py)
or add `scripts/analyze_imu_bias_temp.py`.

---

## Phase B — Lab temperature characterization

Deliberate **cold soak → warm-up → hot soak → cool-down** with kingfisher
recording continuously. Exercises a much wider ΔT than normal flight and
strengthens the linear (or low-order) fit.

### Protocol

1. **Setup**
   - Kingfisher running normal buffered IIO capture (hwfifo on ICM45686).
   - Unit **stationary** for entire run (on a foam pad; no handling during samples).
   - Log session notes in howgozit or aircraft notes field: “IMU temp cal run.”
   - Optional: mark phases via howgozit row or metadata key when phase changes.

2. **Cold soak**
   - Place entire kingfisher unit in freezer.
   - **Soak ≥ 2–3 hours** (colder than any in-air expectation).
   - While soaking: either pause recording or accept missing data; important part
     is **steady cold** before step (2).

3. **Cold → room warm-up**
   - Remove from freezer; leave **stationary** on bench.
   - Record **≥ 1–2 hours** as die temp rises toward ambient (capture transient +
     steady).

4. **Hot soak**
   - Place in controlled **hot box at 50–60°C** (below datasheet +85°C max, above
     any cabin temp).
   - **Soak ≥ 1–2 hours** at peak.

5. **Hot → room cool-down**
   - Remove from hot box; stationary bench cool-down **≥ 1–2 hours**.

6. **Safety**
   - No condensation on powered unit when moving cold → warm (bag/silica if needed).
   - Pi thermal limits: monitor throttling; hot-box setpoint may need to be Pi-safe
     even if die reaches target via soak time.

### Analysis

- Align `icm45686_gyro.anglvel_*` and `icm45686_accel.accel_*` with `temp_c`
  (merge on `ts_ns` or nearest-neighbor within one sample period).
- Per axis, per phase: fit  
  `bias_gyro = b0 + k_g × (T − T_ref)`  
  `bias_accel = a0 + k_a × (T − T_ref)`  
  Use robust regression (median bins by temp) if noise is high.
- Compare fits from cold→warm vs hot→cool for **hysteresis** (datasheet only
  specifies magnitude of TCO, not hysteresis).
- Store fitted coefficients in config (see below).

---

## Phase C — Implementation architecture

### Pipeline overview

Three distinct stages. **Step 1** is one pre-AHRS compensator with two phases;
**Layer 2** is inside the AHRS filter, not in the IMU compensator.

```mermaid
flowchart TB
  IIO[IIO raw samples]
  Store[(Flight DB raw tables)]
  HubRaw[Hub raw latest]

  subgraph step1 [Step 1 pre-AHRS IMU bias]
    P1a[Phase 1a temperature]
    P1b[Phase 1b inertial refine]
    P1a --> P1b
  end

  HubCorr[Hub corrected virtual device]

  subgraph layer2 [Layer 2 AHRS slow drift]
    AHRS[AHRS filter D and C states]
  end

  Derived[Derived devices / UI]

  IIO --> Store
  IIO --> HubRaw
  HubRaw --> P1a
  P1b --> HubCorr
  HubCorr --> AHRS
  AHRS --> Derived
```

| Stage | Where | Time scale | What it catches |
|---|---|---|---|
| **Step 1a** | `internal/derive/imubias/` | Per sample | Linear TCO, lab-fitted b₀ |
| **Step 1b** | Same module | Seconds–minutes (stationary dwell) | BoardVar, b₀ error, mild nonlinearity at current T |
| **Layer 2** | goflying AHRS (`D`, `C` states) | Minutes–hours (~√3600 s process noise in Kalman) | Residual gyro/accel bias, drift SimpleAHRS cannot see, in-flight effects Step 1 misses |

**Division of responsibility:**

- **Step 1** produces the best **sensor-centric** estimate of bias before fusion.
  Output is a corrected IMU stream; coefficients come from lab + ground inertial
  windows. Phase 1b may persist runtime trim across flights (config sidecar) but
  stays in the IMU layer.
- **Layer 2** treats whatever remains as **navigation-state bias** to be learned
  during flight. It must receive Step-1-corrected ω and a (not raw) so it is not
  duplicating the temperature work. It handles slow drift, hysteresis, and other
  unmodeled effects without requiring an explicit T input.

- **Persist raw only** in SQLite device tables (`icm45686_accel`, `icm45686_gyro`).
- **Corrected stream** feeds AHRS and optional UI; clearly named (e.g. virtual
  device `icm45686` or `icm45686_corr`) so replay distinguishes raw vs corrected.
- **Six-face Accept** writes accel bias and **gyro bias corrected to
  `calibration.gyro_tco.t_ref_c`** into `calibbias` / OFFUSER (volatile;
  reapplied from `devices.*.attrs` at boot). The ICM-45686 driver accepts
  `calibbias` writes while IIO buffers are live (briefly quiets the chip FIFO
  and shadows OFFUSER across ODR/FS changes), so kingfisher does not pause
  capture for programming. Soft UI peels piecewise \(\Delta b(T)\) (knees in
  `gyro_tco`); constant bias subtract is gated by `offuser_applied`. Do not
  also enable on-chip RTC/APEX bias paths that would fight OFFUSER.

---

### Step 1 — Pre-AHRS IMU bias compensator

Single goroutine/module subscribing to raw hub samples (accel, gyro, temp, GPS
fix for Phase 1b). Applies both phases before publishing the virtual corrected
device.

#### Step 1, Phase 1a — Temperature correction

Gyro (shipped): piecewise \(\Delta b(T)\) in `calibration.gyro_tco` (knees +
`delta_dps`, zero at `t_ref_c`). With OFFUSER baked to \(T_\mathrm{ref}\):

```
ω_temp_i = ω_raw_i − Δb_i(T)
```

Accel (still planned): linear or piecewise on Z only; X/Y soak TCO is mechanical.

- **Units:** table is °/s; convert to rad/s at the hub boundary.
- **Missing temp:** skip \(\Delta b\) (pass chip-corrected only) or last-known T
  with a staleness limit.
- UI already applies the gyro peel on the boldface line; wire the same helper
  into the AHRS feed when Step 1 lands.

#### Step 1, Phase 1b — Inertial refinement

Runs on **Phase 1a output** (`ω_temp`, `a_temp`). “Inertial” here means no
meaningful user-induced motion — not a free-inertial navigation frame.

**Detect (all required, thresholds tunable):**

- GPS fix valid, ground speed &lt; `v_thresh` (e.g. 2 kt)
- GPS track change rate small (optional)
- Gyro magnitude &lt; `ω_thresh` (e.g. 0.5 °/s) on temp-corrected rates
- Accel deviation from gravity vector &lt; `a_thresh` (attitude stable)
- Minimum dwell time (e.g. 5–10 s)

**Update:**

- Gyro: block mean of `ω_temp` → residual `δb`; slow IIR into runtime trim
  `b_trim` (additive to Phase 1a):  
  `ω_out = ω_temp − b_trim`.
- Accel: expected gravity in body frame (attitude from last good AHRS or level
  assumption on ground) → residual into `a_trim`.

**Persistence:**

- **In-flight:** `b_trim` / `a_trim` in memory; reset each boot unless loaded.
- **Across flights:** optional sidecar
  `~/.config/kingfisher/imu_bias_runtime.json` so lab `b0`/TCO in main config
  stay immutable; trim captures install-specific offset.

Phase 1b **does not** replace Layer 2: it only tightens the feed going into AHRS
on the ground and during long straight-and-level segments where gates pass.

**New code (Step 1 sketch):**

| Piece | Location |
|---|---|
| Config types | [`internal/config/config.go`](../internal/config/config.go) |
| Compensator | `internal/derive/imubias/` (new) — `Correct(raw, gps, cfg, runtime) → corrected` |
| Wiring | [`cmd/kingfisher/main.go`](../cmd/kingfisher/main.go) |
| AHRS input | [`internal/derive/ahrs.go`](../internal/derive/ahrs.go) — `findIMU` prefers corrected device |

---

### Layer 2 — AHRS slow drift (residual bias)

Inside the AHRS engine ([`goflying/ahrs`](../../goflying/ahrs)), not in `imubias`.

**Current kingfisher:** [`internal/derive/ahrs.go`](../internal/derive/ahrs.go)
uses **SimpleAHRS**, which applies `m.B − D` but leaves **`D1/D2/D3` at zero**
(no online learning). Accel bias **`C1/C2/C3`** similarly unused.

**Target:** AHRS consumes **Step-1-corrected** IMU and **estimates remaining
bias online**:

| State | Frame | Role |
|---|---|---|
| `D1,D2,D3` | Sensor / aircraft (per goflying convention) | Residual **gyro** bias, °/s |
| `C1,C2,C3` | Sensor | Residual **accel** bias, G |

**Implementation options (pick during review):**

1. **Switch kingfisher to Kalman AHRS** (`ahrs.NewKalman()` or staged variant) —
   already updates `D`/`C` in the update step with ~1-hour bias drift time
   constant (`tt := sqrt(3600)` in `ahrs_kalman.go`). Lowest new math; larger
   behavior change vs SimpleAHRS.
2. **Extend SimpleAHRS** with slow bias observers (e.g. ZUPT-style nudge of `D`
   when stationary, complementary to Step 1b but at AHRS rate and fused with
   attitude). Smaller diff; duplicate logic risk if not careful.
3. **Hybrid:** Kalman for bias states only — likely overkill; prefer (1) or (2).

**Layer 2 expectations:**

- Operates on **residuals** after Step 1; time constant **slower** than Phase 1b
  (minutes–hours vs seconds–minutes) so the two are not fighting.
- Captures nonlinear TCO, hysteresis, in-flight vibration rectification, and
  model error without explicit temperature terms.
- Optional: log effective `D`/`C` to flight DB (new virtual columns on `ahrs` or
  metadata snapshots) for post-flight audit.

**Wiring:**

| Piece | Location |
|---|---|
| Provider selection | [`internal/config/config.go`](../internal/config/config.go) — `ahrs.provider` |
| AHRS loop | [`internal/derive/ahrs.go`](../internal/derive/ahrs.go) — corrected IMU in `buildMeasurement` |
| Bias dynamics | [`goflying/ahrs/ahrs_kalman*.go`](../../goflying/ahrs) — tune process noise if needed |

### On-chip offsets at initialization

**Requirement:** every kingfisher start records `GYRO_*_OFFUSER` /
`ACCEL_*_OFFUSER` values.

**Current behavior:** [`sensors.Run`](../internal/sensors/sensors.go) calls
`SnapshotAttrs` → `st.LogAttrs` for each IIO reader at startup; includes
`calibbias` per channel.

**Plan tasks:**

1. **Verify** on hardware that both `icm45686-accel` and `icm45686-gyro` expose
   readable `calibbias` for x/y/z at boot.
2. **Test** attr snapshot includes all six gyro + six accel calibbias values
   (unit test with fake reader).
3. **Optional convenience:** duplicate boot snapshot into `metadata` keys
   `imu_icm45686_offuser_gyro_x` etc. for one-row audit (not required if
   `sensor_attrs` query is documented).

### Driver note — on-chip RTC / APEX

Before trusting lab fits, confirm [`icm45686-mod`](../icm45686-mod) init does
**not** enable EDMP/APEX bias tracking that would move the effective zero during
soak. If on-chip correction is active, either:

- Characterize **residual** bias after on-chip correction (still valid), or
- Disable APEX/EDMP for characterization runs (driver/register change; separate
  task).

Check AN-000478 and `inv_icm45600_core.c` power-on defaults.

---

## Configuration sketch

```json
{
  "imu_bias": {
    "icm45686": {
      "enabled": true,
      "t_ref_c": 25.0,
      "gyro": {
        "x": { "b0_dps": 0.0, "tco_dps_per_c": 0.0 },
        "y": { "b0_dps": 0.0, "tco_dps_per_c": 0.0 },
        "z": { "b0_dps": 0.0, "tco_dps_per_c": 0.0 }
      },
      "accel": {
        "x": { "b0_mps2": 0.0, "tco_mps2_per_c": 0.0 },
        "y": { "b0_mps2": 0.0, "tco_mps2_per_c": 0.0 },
        "z": { "b0_mps2": 0.0, "tco_mps2_per_c": 0.0 }
      },
      "inertial_refine": {
        "comment": "Step 1 Phase 1b — pre-AHRS stationary trim",
        "enabled": true,
        "gps_speed_max_kt": 2.0,
        "gyro_max_dps": 0.5,
        "min_dwell_s": 8.0,
        "update_gain": 0.01
      }
    }
  },
  "ahrs": {
    "provider": "kalman",
    "comment": "Layer 2 — enable online D/C bias; was simple (no bias learn)",
    "bias_drift_time_s": 3600
  }
}
```

Unit conversions when loading from lab fits:

- Gyro TCO: datasheet mg-style uses °/s/°C directly.
- Accel TCO: datasheet **mg/°C** → m/s²/°C via × 9.80665e−3.

---

## Implementation order

1. **Analysis tooling** — past-log temp range + bias slope script (Phase A). **Done**
   (`docs/analysis/gyro_tco.md`, soaks under `~/kingfisher/imu_tempcal/`).
2. **Lab run** — execute Phase B protocol; fill Step 1a coefficients in config.
   **Done** for gyro piecewise \(\Delta b(T)\) in `calibration.gyro_tco`.
3. **Cabin calibrate + OFFUSER** — six-face accel / still gyro Accept, soft UI peel,
   driver-safe `calibbias` while buffered. **Done** (see analysis [PLAN.md](analysis/PLAN.md)
   Phase 2–3 + [calibrate.md](analysis/calibrate.md)).
4. **Boot attr verification** — `calibbias` in startup `sensor_attrs` snapshot. **Done**
   (`SnapshotAttrs` includes `calibbias`).
5. **Step 1a online** — temperature compensator + virtual corrected device; AHRS still
   SimpleAHRS; verify raw DB unchanged. Soft UI already peels \(\Delta b(T)\); hub
   `imubias` virtual device still open.
6. **Step 1b** — inertial refinement in same `imubias` module (GPS gates, runtime trim).
7. **Layer 2** — AHRS provider with online `D`/`C` (likely Kalman); feed corrected
   IMU only; tune drift time constant; compare heading hold vs Step 1 alone.
8. **Cockpit** — optional display of Step 1 trim + AHRS `D` (later).
9. **Document** — update CLAUDE.md: raw → Step 1 → AHRS Layer 2 data flow.

---

## Testing

- Unit tests: Step 1a compensation math, Step 1b gate logic, config parse, missing-temp fallback.
- Replay test: load flight DB raw rows, apply Step 1 offline, compare to lab fit.
- Layer 2: AHRS tests with injected residual bias — verify `D`/`C` converge without
  fighting Step 1 (stationary ground segment in sim or recorded DB).
- Regression: [`internal/derive/ahrs_test.go`](../internal/derive/ahrs_test.go)
  updated for corrected IMU input and chosen AHRS provider.

---

## Future sensors

Same **Step 1** pattern after ICM-45686:

- Pod IMUs (if any), ICM-20948 cabin backup, etc.
- Shared `internal/derive/imubias` interface keyed by device name.
- Per-sensor config block and characterization (pod: use its own die temp when available).

**Layer 2** is sensor-agnostic once corrected IMU reaches AHRS.

---

## Open questions (refine before implement)

1. **Virtual device name** for Step 1 output: extend existing `icm45686` tab vs
   new `icm45686_corr`?
2. **UI:** show raw, Step-1-corrected, or both in cockpit IMU tab during bring-up?
   (Boldface already peels \(\Delta b(T)\) / soft constant bias on the raw tabs.)
3. **Hot box:** exact setpoint limited by Pi 5 enclosure thermal coupling to die?
4. **Write `OFFUSER` from software** after Step 1b trim — ever, or software-only?
   (Ground Accept already programs OFFUSER; driver makes live sysfs writes safe.
   Step 1b may stay software-only to avoid fighting a baked \(T_\mathrm{ref}\) trim.)
5. **Layer 2 provider:** full Kalman vs extended SimpleAHRS — trade integration
   risk vs bias-state maturity?
6. **Step 1b vs Layer 2 both active on ground:** ensure time constants / gates
   prevent double-counting stationary bias updates.

---

## References

- [ICM-45686 product page / DS-000577](https://invensense.tdk.com/en-us/products/motion-tracking/6-axis/icm-45686/)
- AN-000257 — Understanding IMU Sensor Offset (TCO, BoardVar, offset budgeting)
- AN-000265 — IMU Calibration Application Note
- AN-000478 — ICM-45605 & ICM-45686 User Guide
- [`docs/timestamps.md`](timestamps.md) — sample time bases for offline alignment

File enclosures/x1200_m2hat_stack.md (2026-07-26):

# X1200 UPS + M.2 HAT+ stack — measured dimensions (2026-07-17)

Eric's caliper measurements of the actual hardware, cross-checked against the
[Geekworm X1200 wiki](https://wiki.geekworm.com/X1200). Input data for the
`case/pi5_aviation_case.py` rework. Reference frame = Pi orientation:
**front** = USB-C/HDMI edge, **right** = Ethernet/USB edge, **left** = microSD
edge, **back** = GPIO edge. X1200 mounts beneath the Pi in the same orientation.

## X1200 UPS (beneath Pi)

| # | Item | Value |
|---|---|---|
| 1 | Cell orientation | 18650s face **down** (toward case floor) |
| 2 | PCB thickness | 1.6 mm |
| 3 | X1200↔Pi standoff (kit) | 4.5 mm (pogo-pin engagement height) |
| 4 | Underside depth (PCB bottom → cell/holder bottom) | 18.5 mm |
| 5 | Tallest Pi-facing parts | pogo pins, then the 4.5 standoffs |
| 6 | Board L×W | 85 × 56 (matches Pi); only the power button overhangs, 2.7 mm on the **left** edge |
| 7 | Mounting holes | match Pi 58×49 pattern; **threaded** (M2.5) |
| 8 | USB-C charge input | **front** edge, center 32.5 from right edge (= 52.5 from left), 8.8 w × 3.1 h, on PCB **top** side. Wiki: 5 Vdc 5 A in, 2.3–3.2 A max charge |
| 9 | Power button | momentary push (mirrors Pi power button; auto power-on enabled by default), **left** edge, 14.0 from back, protrudes 2.7; center 4.0 mm **below** PCB bottom |
| 10 | LEDs | **left** edge top-side: bank 13.0 wide centered on face, charge LED 10.0 from front (wiki: 25/50/75/100% charge level + power status). **Back** edge: two LEDs at 20 and 25 from left, top side |
| 11 | Electrical hookups used | I2C fuel gauge (wiki: Maxim @ 0x36) + power-loss GPIO, wired X1200 → Pi. XH2.54 5V outputs unused |
| 12 | Fastening | see mounting scheme below |

## M.2 HAT+ (above Pi, over the Active Cooler)

| # | Item | Value |
|---|---|---|
| 13 | Standoffs | 16 mm |
| 14 | Tallest above HAT top | extended GPIO pins +9.0; IDC ribbon connector (when attached) is 15.4 tall sitting on a pin-retention strip 4.0 above HAT top → ribbon stack tops out **19.4 above HAT** |
| 15 | Ribbon between Pi and HAT? | gap is 16.0, connector 15.4 — no working pin engagement in the gap; not viable as-is |
| 16 | FPC (PCIe) ribbon | **left** side, bulges ~5 mm past HAT edge |
| 17 | Mounting | all 4 holes, 58×49 pattern |

## Whole stack

| # | Item | Value |
|---|---|---|
| 18 | Bench total, battery bottom → GPIO pin top | **52.2** (computed from rows above: 18.5+1.6+4.5+1.6+16+1.6+9 = 53.3; ~1.1 mm disagreement → keep ≥1.5 mm design margin on heights) |

## Mounting scheme

Prior art for this exact stack
([Omer Droub, Printables 1288473](https://www.printables.com/model/1288473-case-for-raspberry-pi-5-with-geekwormsuptronics-x1),
[Thingiverse 7031272](https://www.thingiverse.com/thing:7031272)) uses M-F
standoffs threaded into the X1200 bosses from below plus M2.5×20 screws from
the Pi top. **Eric's measurements show that scheme doesn't close**: the boss
barrel is only ~6 mm of thread (4.5 post + 1.6 PCB), a 6 mm stud from below
fills essentially all of it, and the top screw has nothing left to grab —
the two fasteners fight over the same threads from opposite ends.

A second refinement (Eric again): a "bolt from the Pi top" is impossible —
the HAT spacers occupy the same four holes. The corner holes serve the whole
tower, so the bolt must start at the **HAT top** and the budget is:
HAT 1.6 + spacer 15.8 (measured; 16 nominal) + Pi 1.6 + barrel 6.1 = **25.1 mm
to exit the barrel**. M2.5×20 → 1 mm of post engagement; M2.5×25 → fills the
barrel but leaves nothing to attach the case standoff. Hence:

**Adopted scheme — one M2.5×30 through-bolt per corner (full-column clamp):**

1. 4× **M2.5×20 female-female standoffs** (hex brass; through-threaded or
   blind-tapped ≥6 mm/end) below the X1200. 20 mm floats the 18.5 mm cells
   1.5 mm over the floor (case pads add another 2 mm).
2. 4× **M2.5×30 bolts from the HAT top**: HAT → spacer → Pi → *through* the
   X1200 barrel → ~4.9 mm into the standoff top. One torqued column per
   corner; the barrel's thin threads are captured, not load-bearing. The bolt
   threads through ~22 mm of female thread (spacer + barrel) — optionally swap
   the HAT's threaded spacers for plain 16 mm tube spacers to avoid that.
3. 4× **M2.5×8 pan-head case screws from below** through the counterbored
   floor+pad (2.3 mm) into the standoff bottom (~5.7 mm engagement).
   Tip-collision check inside the standoff: 4.9 + 5.7 = 10.6 ≤ 20 → 9.4 clear.

Assembly: build the tower on the bench, spin the standoffs onto the
protruding bolt tips *before* torquing (aligns the threaded segments), torque,
drop in, base screws last. Loose joints → poor pogo contact. The 4.5 mm posts
are **fixed to the X1200** (confirmed). Bolt heads on the HAT top (~2.5 mm)
stay far below the IDC connector — no case-height impact.

## Case design decisions

- microSD access: **dropped** (NVMe boot).
- Cooling: keep lid grille + add side grilles; fan rarely runs but help it.
- Left wall: LED **light pipes** (side bank), recessed finger hole for the
  power button (guard against inadvertent press), FPC ribbon needs ~5 mm of
  left interior clearance (CLR_L 1.0 → ~6).
- Back wall: light pipes for the two back LEDs.
- Front wall: UPS USB-C should sit ~**flush** for easy cable insertion → local
  interior wall pad around the port (global CLR_F stays Ethernet-limited).
- Bottom exterior stays flat for Dual-Lock → counterbore the 4 base screws.

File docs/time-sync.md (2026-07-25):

# GNSS Time Sync

Kingfisher records everything against the host's `CLOCK_REALTIME` time base. The
flight DB filename, `_session.start_time`, buffered IIO timestamps on
`current_timestamp_clock == realtime`, pod wall-clock reconstruction, and
derived-stream timestamps all assume the Pi wall clock is already sane.

Per-table **`ts_ns`** semantics, GPS **`fix_time_unix_s`** vs row time, and
sensor-fusion guidance: **`docs/timestamps.md`**.

The intended deployment model is:

1. `gpsd` reads the M9N on `/dev/ttyAMA0` in read-only mode.
2. `chronyd` disciplines the Pi clock from gpsd over Unix-domain SOCK refclocks.
3. With PPS wired, gpsd also feeds a PPS SOCK; chrony disciplines the clock from
   PPS (sub-µs) and uses the UART SOCK only to number each PPS second
   (`lock GPS`). The UART source is `noselect`, so it never competes with PPS.
4. Kingfisher starts after chrony is healthy and reports live Pi-vs-GPS clock
   health in the cockpit header.

Repo-owned starting points live in `deploy/time-sync/`:

- `deploy/time-sync/gpsd.default.example` → `/etc/default/gpsd`
- `deploy/time-sync/chrony.conf.example` → `/etc/chrony/chrony.conf`
- `deploy/time-sync/99-pps-chrony.rules` → only if using kernel `refclock PPS`
  (not recommended here; see below)
- `deploy/time-sync/kingfisher-clock-check.sh` → `/usr/local/bin/` and
  `deploy/time-sync/kingfisher-clock-check.service` → `/etc/systemd/system/`
  (boot-time wrong-second check; see §8a)
- `deploy/time-sync/verify.md` — post-install checklist

## Hardware

| Signal | Pi 5 header | Device |
|---|---|---|
| M9N UART TX/RX | GPIO 14/15 | `/dev/ttyAMA0` |
| M9N PPS out | GPIO 18 (physical pin 12) | `/dev/pps0` via `pps-gpio` overlay |

PPS is optional for bring-up but recommended for flight recording accuracy.

## 1. Install packages

```bash
sudo apt install gpsd gpsd-clients chrony
sudo apt install pps-tools    # optional; provides ppstest
```

## 2. Configure gpsd

Copy `deploy/time-sync/gpsd.default.example` into **`/etc/default/gpsd`**
(or merge by hand):

```ini
START_DAEMON="true"
USBAUTO="false"
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

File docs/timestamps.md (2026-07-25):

# Timestamps in flight databases

Every sensor table in a kingfisher flight DB has a **`ts_ns`** column: nanoseconds
since the Unix epoch. Values are written exactly as each producer sets
`live.Sample.TsNs` — the store does not restamp rows at flush time.

All streams are intended to share one time base: the Pi host **`CLOCK_REALTIME`**
wall clock, ideally GNSS-disciplined via chrony (and PPS when wired). See
`docs/time-sync.md` for bringing that clock up before recording.

This document explains what `ts_ns` means per source, how close it is to the
**actual measurement instant**, and how to use timestamps for later sensor
fusion — especially GPS.
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

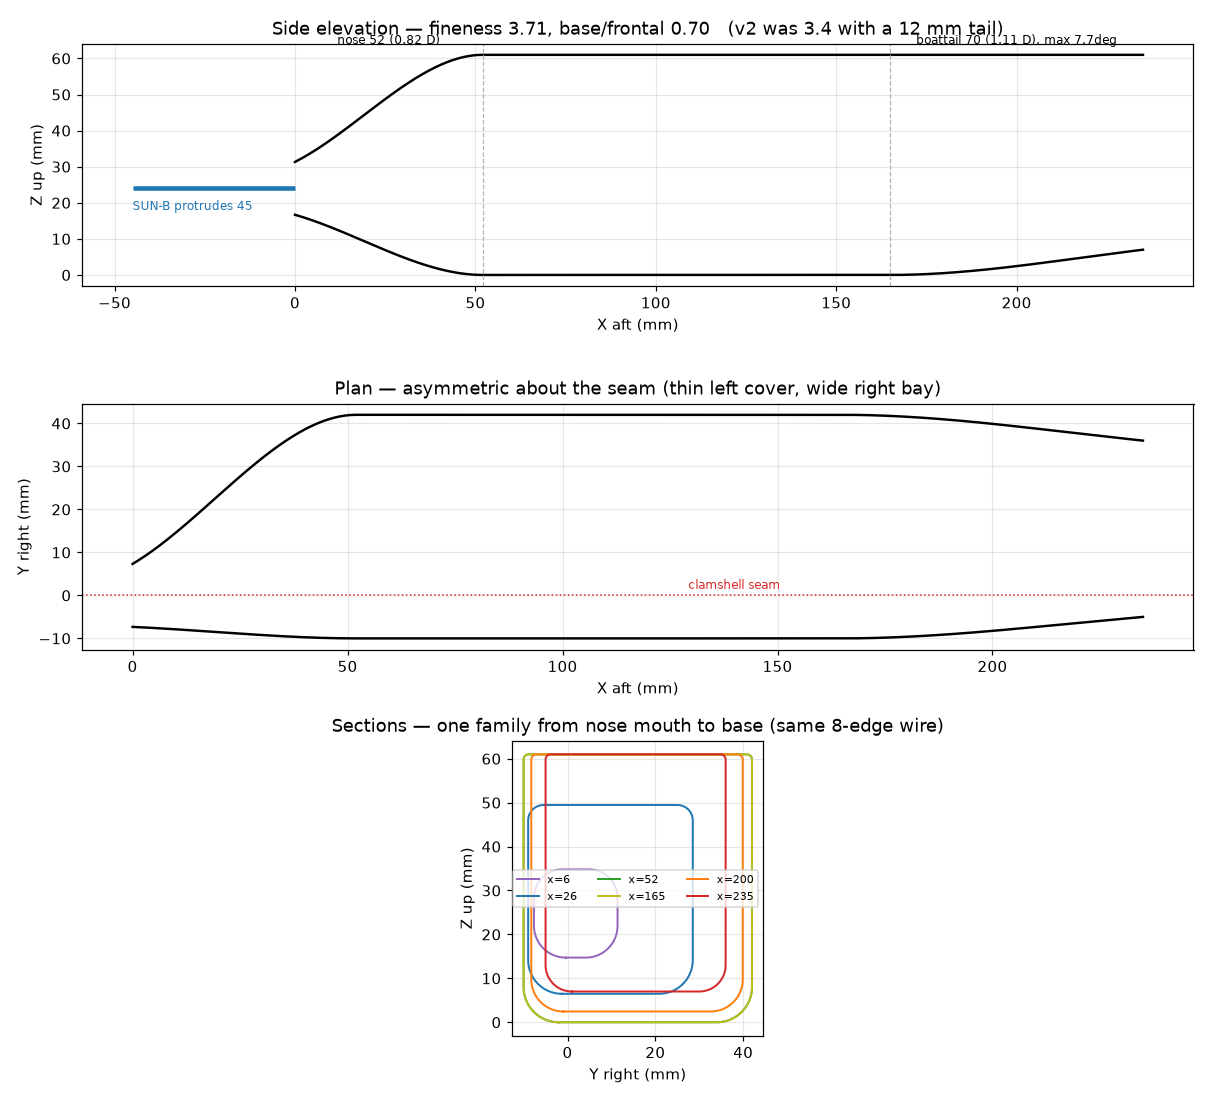
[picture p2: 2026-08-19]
enclosures/pod/pod_v3_235x52x61_profile.png

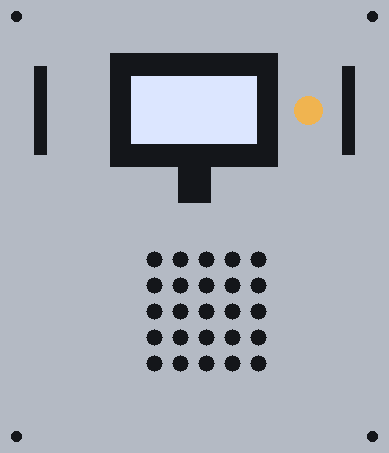
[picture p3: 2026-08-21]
enclosures/case/case_lid_oled_qc_20260821.png

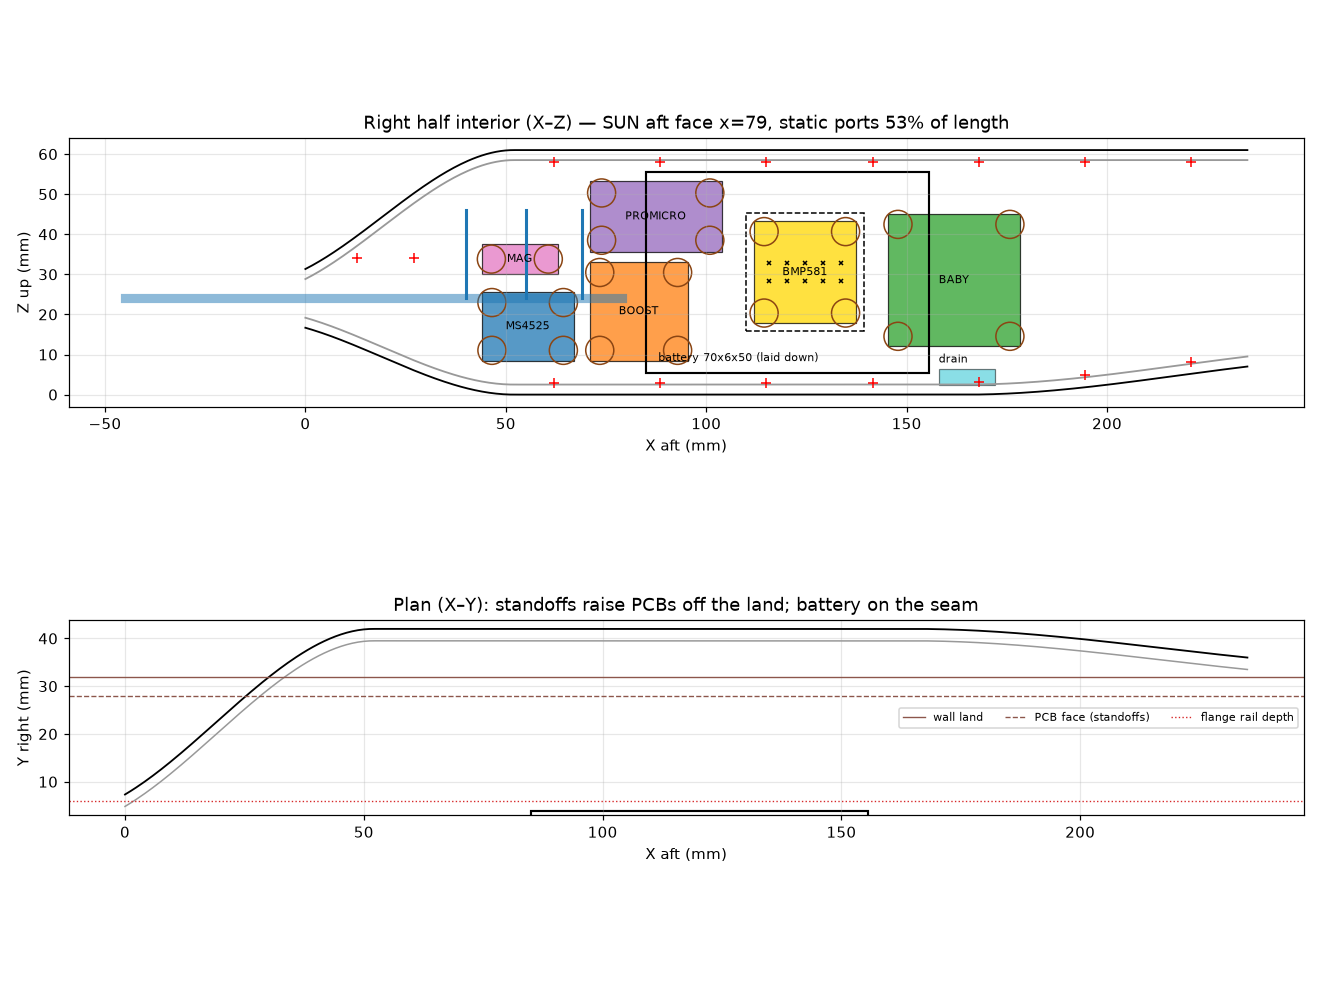
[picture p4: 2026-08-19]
enclosures/pod/pod_v3_235x52x61_interior.png

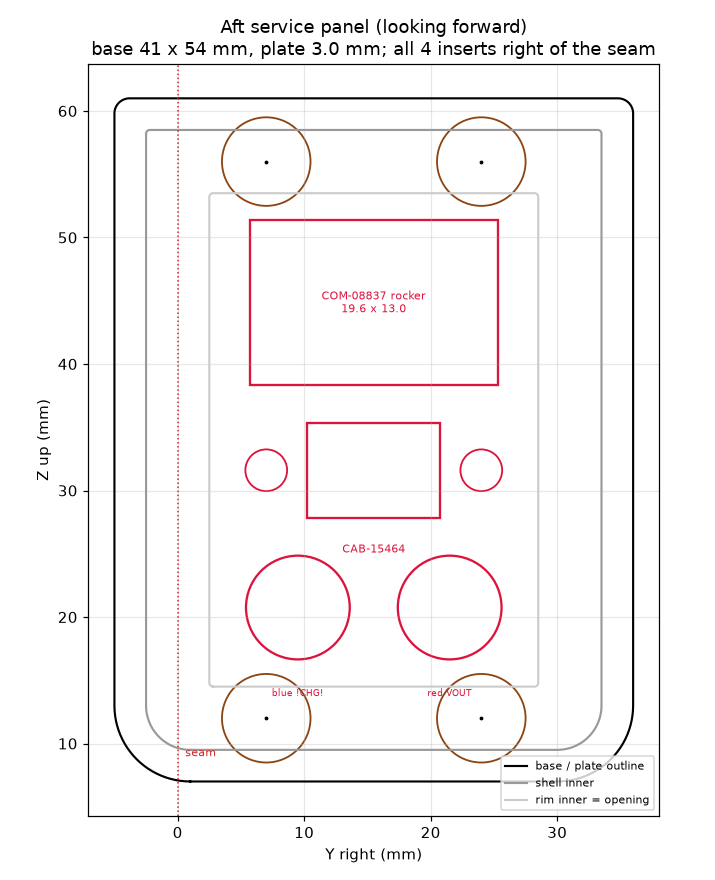
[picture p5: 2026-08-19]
enclosures/pod/pod_v3_235x52x61_aft_panel.png

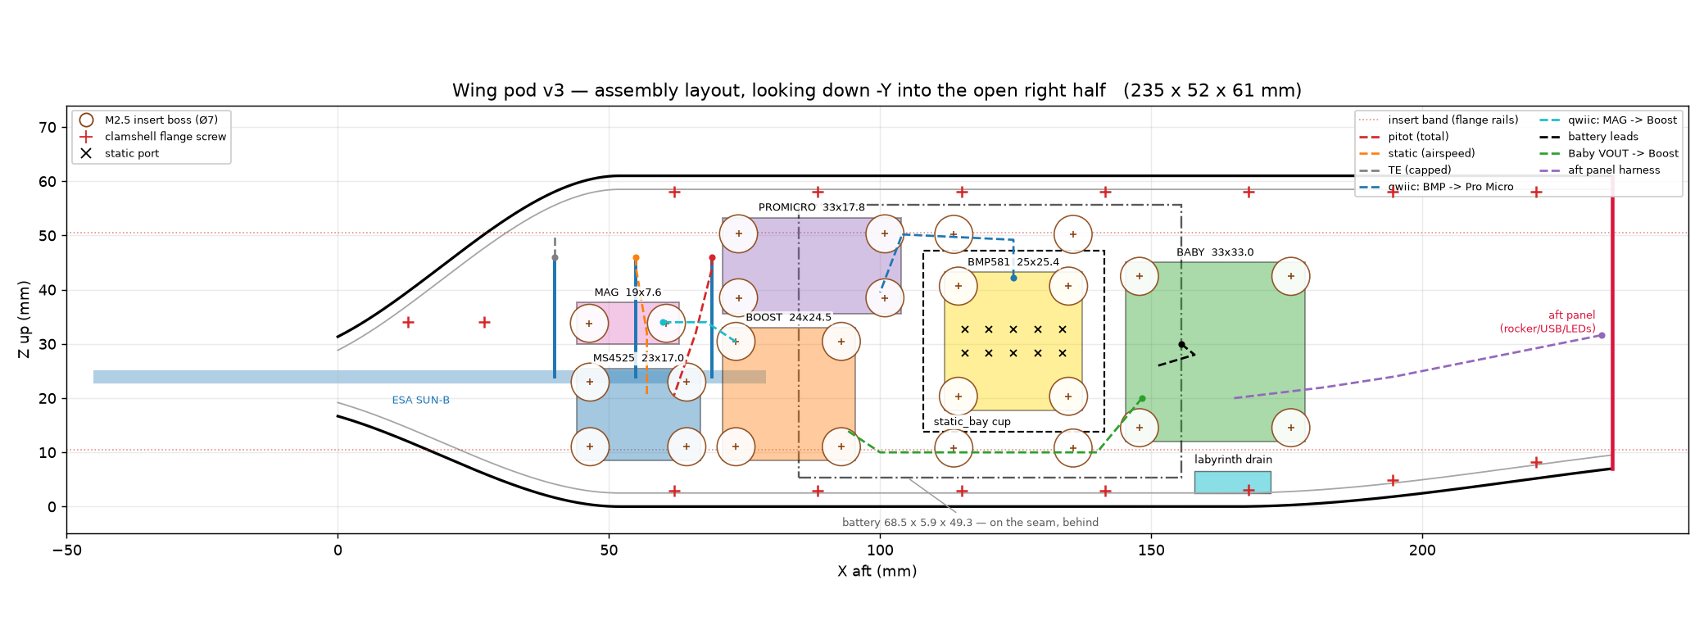
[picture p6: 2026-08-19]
enclosures/pod/pod_v3_235x52x61_layout.png

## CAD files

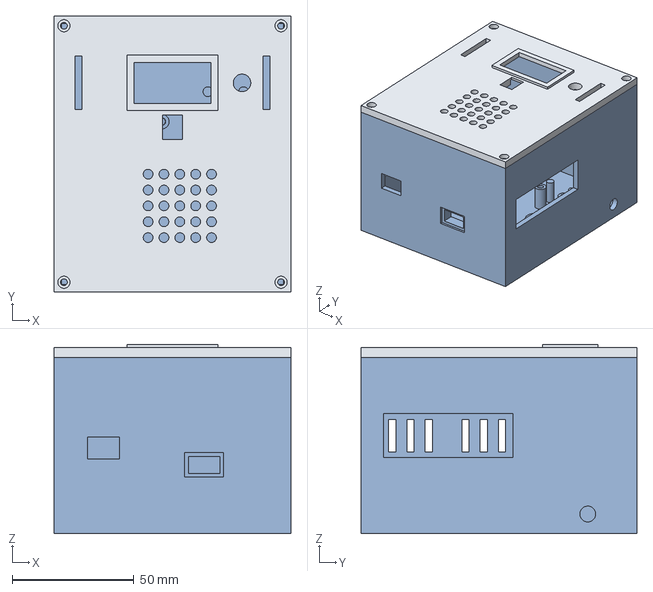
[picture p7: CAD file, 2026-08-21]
enclosures/case/case_assembly.step
97.0 x 113.1 x 77.5 mm
base
lid

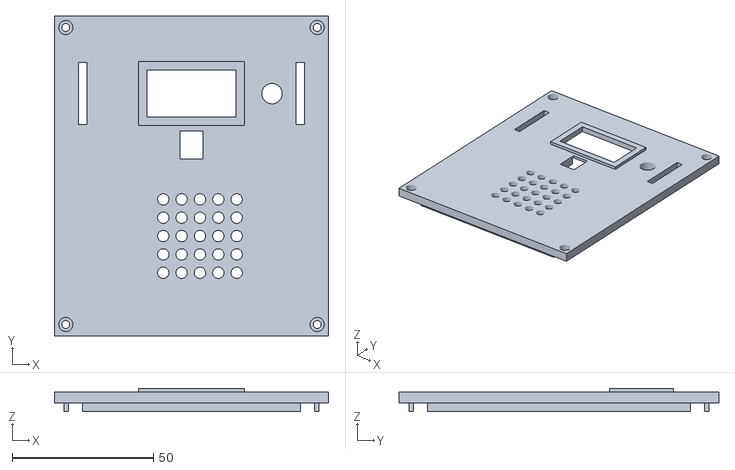
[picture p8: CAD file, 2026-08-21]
enclosures/case/_lid_asm.stl
97.0 x 113.1 x 8.30

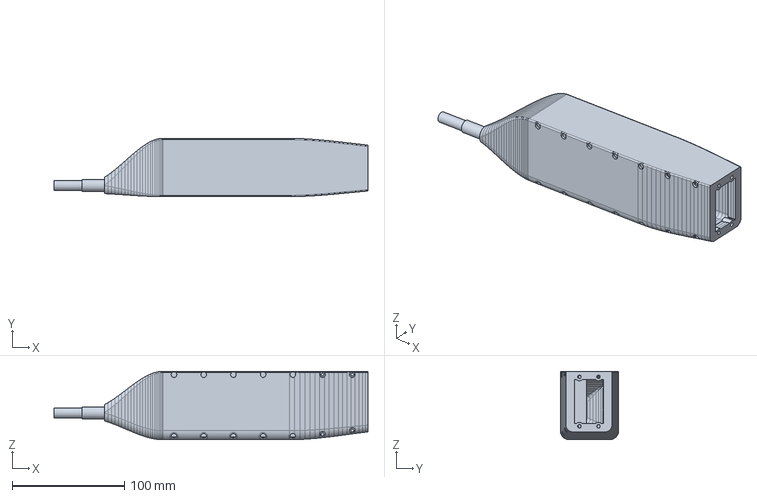
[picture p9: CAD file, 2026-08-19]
enclosures/pod/pod_assembly.step
280.0 x 52.0 x 61.0 mm

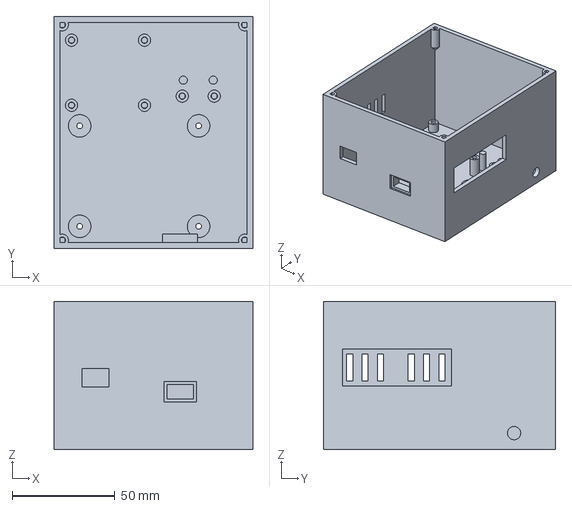
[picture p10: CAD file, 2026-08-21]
enclosures/case/case_base.step
97.0 x 113.1 x 72.2 mm

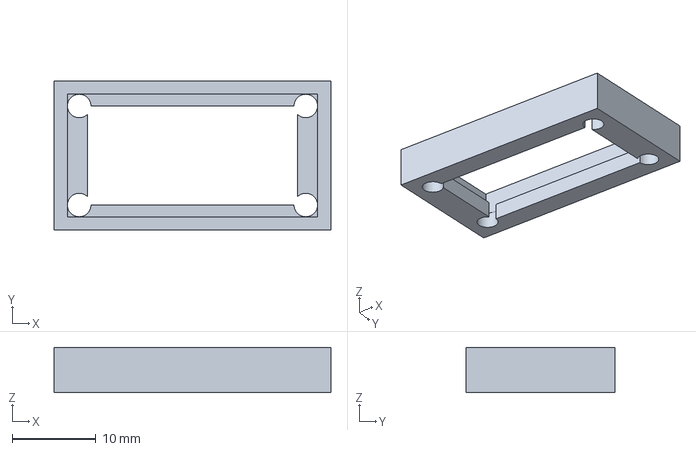
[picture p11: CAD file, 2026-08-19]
enclosures/pod/pm_tray.step
33.0 x 17.8 x 5.40 mm

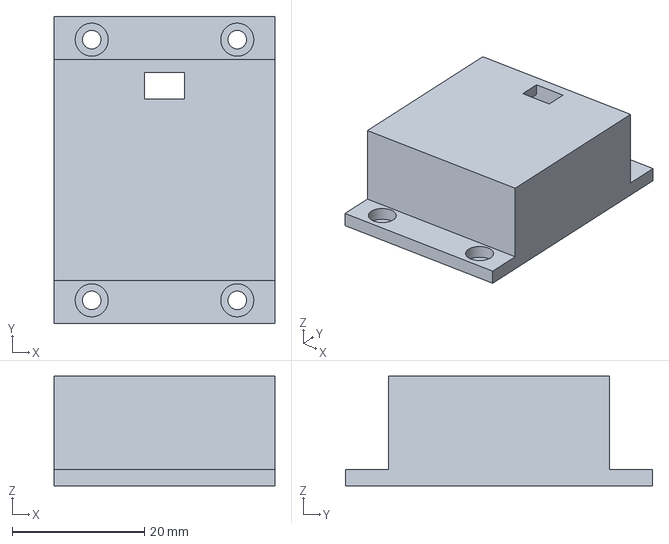
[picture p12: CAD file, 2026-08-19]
enclosures/pod/static_bay.step
33.4 x 46.4 x 16.6 mm

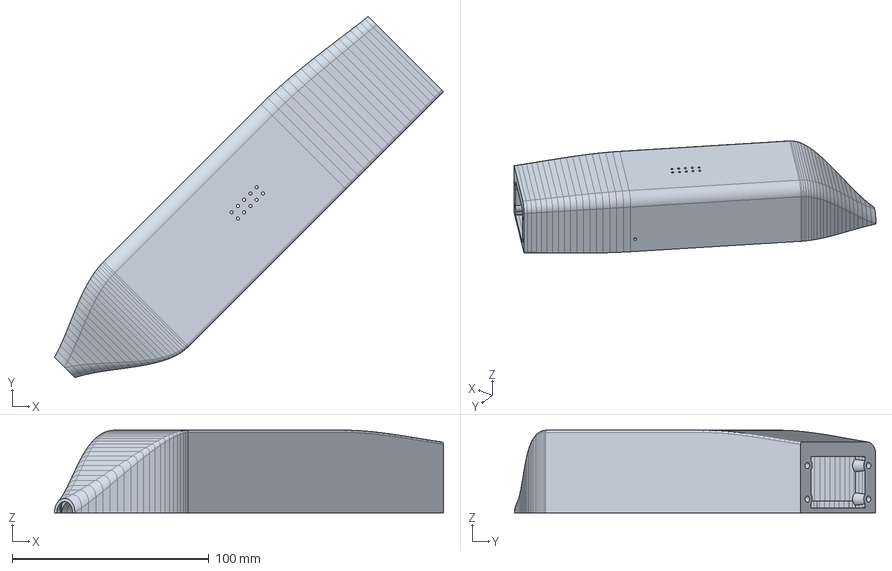
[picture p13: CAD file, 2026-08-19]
enclosures/pod/pod_right.step
197.5 x 183.4 x 42.0 mm

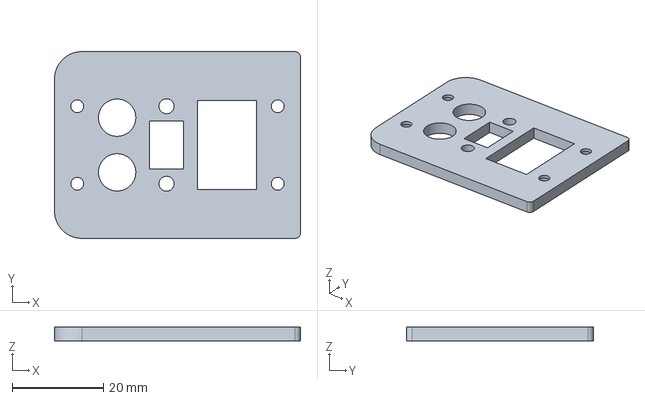
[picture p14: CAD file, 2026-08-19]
enclosures/pod/tail_panel.step
54.0 x 41.0 x 3.00 mm

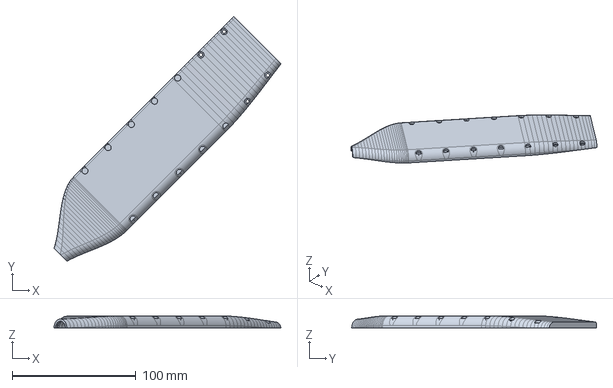
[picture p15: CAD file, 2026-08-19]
enclosures/pod/pod_left.step
183.3 x 197.5 x 10.0 mm

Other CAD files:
enclosures/case/case_lid.step
enclosures/case/case_base.stl
enclosures/case/case_lid.stl
enclosures/pod/pm_tray.stl
enclosures/pod/pod_left.stl
enclosures/pod/pod_right.stl
enclosures/pod/static_bay.stl
enclosures/pod/tail_panel.stl

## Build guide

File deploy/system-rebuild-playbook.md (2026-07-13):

# Kingfisher build playbook — Raspberry Pi 5 + NVMe SSD

Provisions a kingfisher flight-data-recorder host **from scratch**: a Raspberry Pi 5
running RPi OS Lite (trixie, arm64, kernel `6.18.34+rpt-rpi-2712`) on an NVMe SSD,
hostname `kingfisher`. It captures the full delta from a stock image — packages, boot
config, out-of-tree drivers, time sync, networking, and the app — so a fresh build is
reproducible end to end.

First distilled 2026-07-12; keep it current as the system evolves (etckeeper tracks
`/etc`, so most drift is self-documenting). Sections marked **[DISCUSS]** are collected
at the end under *Cruft* (deliberately not installed) and *Improvements*.

---

## Phase 0 — what you supply

Have these ready before you start (from a backup, a password manager, or created fresh).
None are reconstructable by the OS install:

| What | Where it goes | Notes |
|---|---|---|
| Wi-Fi client PSK | `/etc/NetworkManager/system-connections/*.nmconnection` | home-LAN uplink on wlan1 (Phase 10) |
| App config | `~/.config/kingfisher/config.json` | aircraft, pod, GDL90 clients, trusted devices |
| SSH `authorized_keys` | `~/.ssh/authorized_keys` | your key access |
| Flight data (optional) | `~/kingfisher/flights/` | restore from backup, or start empty |
| Go workspace | `~/go/src/github.com/westphae/*` | or re-clone from GitHub (Phase 12) |

Not needed: the NEO-M9N GPS keeps its config in its own flash — only re-run the `ubxtool`
sequence if it's ever factory-reset (DYNMODEL=7 Airborne <2g, 10 Hz, UART1 115200,
UBX-NAV-PVT only, saved to layer mask 7). SSH host keys and Caddy's internal CA are
generated on first run (expect one known_hosts prompt; tablets re-trust HTTPS once).

## Phase 1 — flash and first boot

1. Flash **Raspberry Pi OS Lite (64-bit, trixie)** to the SSD.
2. On the bootfs (FAT) partition before first boot:
   - `touch ssh`
   - `userconf.txt`: `eric:$(echo 'yourpassword' | openssl passwd -6 -stdin)`
     (a fresh install gives eric uid 1000; nothing here depends on the uid)
   - **Wi-Fi country / unblock** (else wlan is dead on first boot — bit us twice
     2026-07-12; there are THREE persistence layers and all must agree):
     1. regdom: append ` cfg80211.ieee80211_regdom=US` to `cmdline.txt` (keep it one line!);
     2. rfkill: on the rootfs write `0` into `/var/lib/systemd/rfkill/*:wlan` (image
        ships them as `1` = blocked; systemd-rfkill restores the state every boot);
     3. NetworkManager's own radio switch: if the system ever boots while blocked, NM
        writes `WirelessEnabled=false` to `/var/lib/NetworkManager/NetworkManager.state`
        and re-blocks the radios itself on every later boot even after 1+2 are fixed.
        Fix live with `sudo nmcli radio wifi on` (persists), or pre-seed the file on the
        rootfs with `[main]` + `WirelessEnabled=true`.
   - (optional, smooths headless bring-up) on the rootfs: pre-copy `Holonet.nmconnection`
     into `/etc/NetworkManager/system-connections/` (0600 root:root) so it joins the home
     LAN immediately; pre-set `/etc/hostname` + `/etc/hosts` (kingfisher) and
     `/etc/localtime → /usr/share/zoneinfo/Etc/UTC` — step 4 is then already done.
3. Partition plan — 128G root, rest `/home` (~804G on a 1TB SSD; the roomy root leaves
   space for e.g. /var/lib/docker). **Gotcha: the firstboot auto-resize REFUSES to grow
   root unless it is the last partition** — pre-creating p3 as a "growth boundary" silently
   disables the resize, leaving the 2.3G image-sized root. So lay it out yourself from any
   Linux machine with the SSD attached (shown as `/dev/nvme0n1`; before first boot or after,
   both work):
   ```sh
   sudo parted /dev/nvme0n1 -- mkpart primary ext4 128GiB 100%    # creates p3 (/home)
   sudo mkfs.ext4 -L home /dev/nvme0n1p3
   sudo e2fsck -f /dev/nvme0n1p2
   sudo parted /dev/nvme0n1 unit s print                          # note p3's start sector
   sudo parted /dev/nvme0n1 -- resizepart 2 268435455s            # = p3 start − 1
   sudo resize2fs /dev/nvme0n1p2
   ```
   Then add `/home` to fstab (mount p2 to reach its `/etc`):
   ```sh
   echo 'PARTUUID=xxxxxxxx-03  /home  ext4  defaults,noatime  0  2' >> <p2>/etc/fstab
   ```
   (real PARTUUID from `blkid`; it's the disk id + `-03`). `/home` starts empty; the user
   dir is created on first boot, and flight data is restored later (Phase 12) if you have a
   backup.
4. First boot basics:
   ```sh
   sudo hostnamectl hostname kingfisher
   sudo timedatectl set-timezone Etc/UTC
   sudo timedatectl set-local-rtc 0
   ```

## Phase 2 — base system

```sh
# etckeeper FIRST, so every subsequent config change is auto-tracked in git:
sudo apt update && sudo apt install -y etckeeper

# hardware watchdog: 15s (vendor file 40-rpi-enable-watchdog.conf already sets 1min;
# the 99- prefix is required to override it):
sudo mkdir -p /etc/systemd/system.conf.d
printf '[Manager]\nRuntimeWatchdogSec=15\n' | sudo tee /etc/systemd/system.conf.d/99-watchdog.conf

# passwordless sudo — via visudo:
#   eric ALL=(ALL) NOPASSWD: ALL
sudo EDITOR=vim visudo

sudo usermod -aG adm,dialout,plugdev eric      # plugdev is load-bearing (IIO access)

# free ttyAMA10 debug UART from the login getty (GPS uses ttyAMA0, but this was done deliberately)
sudo systemctl disable --now serial-getty@ttyAMA10.service

# ghostty terminfo (run FROM your workstation):
#   infocmp -x | ssh eric@kingfisher 'tic -x -'

# EEPROM (verify with: sudo rpi-eeprom-config)
#   BOOT_UART=1, BOOT_ORDER=0xf461 (SD first, then NVMe, then USB — SD-first means an
#   inserted card wins over the SSD; that's desirable while the SD is the fallback),
#   NET_INSTALL_AT_POWER_ON=1, FIRMWARE_RELEASE_STATUS="latest" in /etc/default/rpi-eeprom-update
```

## Phase 3 — apt packages

Third-party repos first:

```sh
# Caddy
sudo apt install -y debian-keyring debian-archive-keyring apt-transport-https
curl -1sLf 'https://dl.cloudsmith.io/public/caddy/stable/gpg.key' | sudo gpg --dearmor -o /usr/share/keyrings/caddy-stable-archive-keyring.gpg
curl -1sLf 'https://dl.cloudsmith.io/public/caddy/stable/debian.deb.txt' | sudo tee /etc/apt/sources.list.d/caddy-stable.list
# GitHub CLI
curl -fsSL https://cli.github.com/packages/githubcli-archive-keyring.gpg | sudo dd of=/etc/apt/keyrings/githubcli-archive-keyring.gpg && sudo chmod go+r /etc/apt/keyrings/githubcli-archive-keyring.gpg
echo "deb [arch=$(dpkg --print-architecture) signed-by=/etc/apt/keyrings/githubcli-archive-keyring.gpg] https://cli.github.com/packages stable main" | sudo tee /etc/apt/sources.list.d/github-cli.list
sudo apt update
```

Core install (everything the flight stack + your workflow actually uses):

```sh
sudo apt install -y \
  build-essential cmake pkg-config git gh vim tmux tree htop ncdu jq sqlite3 \
  gdb strace tcpdump stress rsync zip unzip p7zip-full \
  i2c-tools python3-smbus2 python3-pip python3-venv python-is-python3 \
  gpsd gpsd-clients pps-tools chrony \
  caddy libpam0g-dev \
  linux-headers-rpi-2712 \
  avahi-daemon network-manager
# SDR / airband stack (only if keeping airband — see Improvements):
sudo apt install -y rtl-sdr librtlsdr-dev libshout3-dev libmp3lame-dev libfftw3-dev libconfig++-dev libpulse-dev libsoapysdr-dev
```

**[DISCUSS — cruft, deliberately omitted]**: `cursor` (side-loaded .deb IDE + its
`50-cursor.conf` sysctl), `mkvtoolnix`, `ghostscript`, `poppler-utils`, `qpdf`,
`python3-pymupdf`, `python3-pypdf`, `cifs-utils`, `ntfs-3g`, `lua5.1`, `luajit`,
`rpi-connect-lite` (installed but off), `rpi-usb-gadget`, `usb-modeswitch`,
`rpicam-apps-lite`, `kms++-utils`, `v4l-utils`, `mkvtoolnix`, `firmware-atheros/libertas/mediatek/realtek`
(unless the wlan1 dongle needs one — check `lsusb`/`dmesg` for which firmware wlan1 loads!).

## Phase 4 — toolchains (non-apt)

```sh
# Go (tarball, NOT apt) — check go.dev/dl for current version:
wget https://go.dev/dl/go1.26.4.linux-arm64.tar.gz
sudo rm -rf /usr/local/go && sudo tar -C /usr/local -xzf go1.26.4.linux-arm64.tar.gz

# Rust + espflash (ESP32-C3 pod firmware flashing):
curl --proto '=https' --tlsv1.2 -sSf https://sh.rustup.rs | sh
cargo install espflash

# uv (python):
curl -LsSf https://astral.sh/uv/install.sh | sh

# atuin (shell history; installer adds the .bashrc hooks itself):
curl --proto '=https' --tlsv1.2 -LsSf https://setup.atuin.sh | sh
atuin import auto     # then restore ~/.local/share/atuin/ from a backup to keep history

# Claude Code:
curl -fsSL https://claude.ai/install.sh | bash    # (or current official method)

# ~/.bashrc additions (drop the stratux path — cruft):
export GOPATH=$HOME/go
export PATH=$HOME/.local/bin:$HOME/go/bin:${PATH}:/usr/local/go/bin
[ -e "$HOME/.ssh/agent.sock" ] && export SSH_AUTH_SOCK="$HOME/.ssh/agent.sock"
```

## Phase 5 — boot configuration

Append to `/boot/firmware/config.txt` (under `[all]`) — this is the complete delta vs stock:

```ini
dtparam=i2c_arm=on
dtparam=i2c_arm_baudrate=100000

# --- Flight sensor stack ---
#dtoverlay=icm20948      # NOT used: 0x68 address conflict with icm45686 (both 0x68)
dtoverlay=icm45686,int_trigger=8
#dtoverlay=mmc5983ma                     # disabled: mag lives on the ESP32 pod
#dtoverlay=i2c-sensor,bmp280,addr=0x77   # disabled: sensor unplugged
dtoverlay=uart0-pi5
dtoverlay=pps-gpio,gpiopin=18
dtparam=rtc_bbat_vchg=3000000

# --- NVMe ---
dtparam=pciex1_gen=3   # Gen 3 (~900 MB/s vs ~450 default); not RPi-certified but verified
                       # error-free on this HAT + Kingston NV3 (2026-07-12). If dmesg ever
                       # shows AER corrected-error spam or nvme timeouts, remove this line.
```

Gotchas encoded there: `int_trigger=8` is **mandatory** (INT1 wired active-low; default
edge-rising probes but never interrupts); 3.0 V RTC charge is the correct value for the
official cell — do not raise; the two `dtoverlay` lines for icm45686/mmc5983ma are added
automatically by `make install` in Phase 6, so add the rest and let make handle those
(or add all and make will skip).

`/boot/firmware/cmdline.txt`: append `cfg80211.ieee80211_regdom=US` to the single line.

## Phase 6 — out-of-tree kernel modules + overlays (DKMS)

The IMU and magnetometer drivers are custom builds, managed by **DKMS** (adopted
2026-07-12 — each repo now carries a `dkms.conf`; commit them!). DKMS auto-rebuilds
both modules on every kernel upgrade. What motivated this: an mmc5983ma module built by
hand was found dead after a 6.18.33→.34 kernel bump — in the plane that's a dead sensor.

```sh
sudo apt install -y dkms    # (if not already via Phase 3)
mkdir -p ~/go/src/github.com/westphae && cd $_
git clone https://github.com/westphae/icm45686-mod    # vendored mainline inv_icm45600 driver
git clone https://github.com/westphae/mmc5983ma-mod

# modules via dkms:
sudo ln -sfn $PWD/icm45686-mod  /usr/src/icm45686-1.0
sudo ln -sfn $PWD/mmc5983ma-mod /usr/src/mmc5983ma-1.0
sudo dkms add icm45686/1.0 && sudo dkms build icm45686/1.0 && sudo dkms install icm45686/1.0
sudo dkms add mmc5983ma/1.0 && sudo dkms build mmc5983ma/1.0 && sudo dkms install mmc5983ma/1.0

# overlays + config.txt lines (module part now handled by dkms — do NOT run plain `make install`):
(cd icm45686-mod  && make dtbo && sudo make dtbo_install config_enable)
(cd mmc5983ma-mod && make dtbo && sudo make dtbo_install)   # dtbo staged but overlay stays
#   commented in config.txt — the mag is on the ESP32 pod, not the Pi bus (decided 2026-07-12)
sudo reboot
```

Verify after reboot: `dkms status` shows both installed; `ls /sys/bus/iio/devices/`
shows the IMU devices; `grep 17 /proc/interrupts` counts up when the IMU samples.
Note: if the driver source changes, rebuild with
`sudo dkms remove <name>/1.0 --all && sudo dkms add/build/install <name>/1.0`.

## Phase 7 — non-root IIO access chain (three files + group)

All three ship in the mod repos' `etc/` dirs; contents for reference:

`/etc/udev/rules.d/99-iio.rules`:
```
SUBSYSTEM=="iio", GROUP="plugdev", MODE="0660"
SUBSYSTEM=="iio", KERNEL=="iio:device*", \
    RUN+="/bin/sh -c 'chgrp -R plugdev /sys%p && chmod -R g+rwX /sys%p'"
SUBSYSTEM=="iio", KERNEL=="trigger[0-9]*", \
    RUN+="/bin/sh -c 'chgrp -R plugdev /sys%p && chmod -R g+rwX /sys%p'"
```

`/etc/tmpfiles.d/iio.conf`:
```
z /sys/kernel/config/iio/triggers/hrtimer 0775 root plugdev - -
```

`/etc/modules-load.d/iio-trig-hrtimer.conf`:
```
iio-trig-hrtimer
```

## Phase 8 — time sync (GPS + PPS → chrony)

1. `/etc/default/gpsd`:
   ```
   START_DAEMON="true"
   USBAUTO="false"
   DEVICES="/dev/ttyAMA0 /dev/pps0"
   GPSD_OPTIONS="-n -b -s 115200"
   GPSD_SOCKET="/var/run/gpsd.sock"
   ```
   (`-b` read-only is required to preserve the receiver's lean 10 Hz NAV-PVT stream;
   `-s 115200` because `-b` disables autobaud. `/dev/ttyAMA0` NOT `/dev/serial0`.)

2. `/etc/chrony/chrony.conf` — three edits to the stock file:
   - change `makestep 1 3` → `makestep 0.5 3` (never step mid-flight)
   - **comment out the default `pool 2.debian.pool.ntp.org iburst`** (GPS-only time — see Improvements #6)
   - add:
   ```
   refclock SOCK /run/chrony.clk.ttyAMA0.sock refid GPS precision 1e-1 offset 0.0 delay 0.1 poll 2 filter 3 noselect
   refclock SOCK /run/chrony.pps0.sock refid PPS precision 1e-7 lock GPS poll 2
   ```
   (GPS is `noselect` on purpose — gpsd's NMEA SOCK latency wanders per-restart; PPS is
   the sole timekeeper, locked to GPS for the second numbering. Do not "fix" the offset.)

3. `/etc/chrony/conf.d/logging.conf`: `log tracking measurements statistics`

4. `/etc/udev/rules.d/99-pps-chrony.rules`:
   ```
   KERNEL=="pps*", GROUP="_chrony", MODE="0660"
   ```

5. Helper scripts + unit (all in kingfisher repo `deploy/time-sync/`):
   ```sh
   sudo install -m 755 deploy/time-sync/kingfisher-resync-time.sh /usr/local/bin/
   sudo install -m 755 deploy/time-sync/kingfisher-clock-check.sh /usr/local/bin/
   sudo install -m 644 deploy/time-sync/kingfisher-clock-check.service /etc/systemd/system/
   sudo systemctl daemon-reload && sudo systemctl enable kingfisher-clock-check.service
   ```

6. `/etc/sudoers.d/kingfisher-resync` (mode 0440, validate with `visudo -cf`):
   ```
   eric ALL=(root) NOPASSWD: /usr/local/bin/kingfisher-resync-time.sh, /usr/bin/chronyc
   ```

7. Codify the restart ordering (chronyd creates the SOCK refclock sockets; gpsd connects
   to them) — `/etc/systemd/system/gpsd.service.d/chrony-order.conf`:
   ```ini
   [Unit]
   After=chrony.service
   PartOf=chrony.service
   ```
   Verified 2026-07-12: `systemctl restart chrony` now restarts gpsd automatically and
   both refclocks resume samples. (`kingfisher-resync-time.sh` also still does it explicitly.)

## Phase 9 — journald (persistent, SSD-sized, spam-guarded)

`/etc/systemd/journald.conf.d/99-persistent-capped.conf` (the `99-` prefix must sort
after the vendor `40-rpi-volatile-storage.conf` that forces volatile):

```ini
[Journal]
Storage=persistent
SystemMaxUse=2G
SystemMaxFileSize=128M
MaxRetentionSec=6month
SyncIntervalSec=30s
RateLimitIntervalSec=30s
RateLimitBurst=5000
```

## Phase 10 — networking

```sh
# Access point (open network — see Improvements #1):
sudo nmcli con add type wifi ifname wlan0 con-name kingfisher ssid kingfisher \
  802-11-wireless.mode ap 802-11-wireless.band bg 802-11-wireless.channel 6 \
  802-11-wireless.powersave 2 ipv4.method shared ipv4.addresses 192.168.10.1/24 \
  connection.autoconnect yes connection.autoconnect-priority 100

# Client networks: copy the saved .nmconnection files into
# /etc/NetworkManager/system-connections/ (root:root, mode 0600), then
# nmcli con reload    — or re-add with nmcli device wifi connect.
```

`/etc/NetworkManager/dnsmasq-shared.d/kingfisher-efb.conf` (EFB DHCP reservations):
```
dhcp-host=5c:33:7b:ec:ab:2d,192.168.10.158,Pixel-8-Pro
dhcp-host=f8:b1:dd:97:60:81,192.168.10.230,iPad-Mini
```

`/etc/avahi/avahi-daemon.conf` deltas from stock: `enable-wide-area=yes`,
`publish-workstation=yes`, `ratelimit-interval-usec=1000000`, `ratelimit-burst=1000`.

## Phase 11 — Caddy

`/etc/caddy/Caddyfile` (canonical copy + full README in repo `deploy/caddy/`):
```
https://kingfisher.lan, https://kingfisher, https://192.168.10.1, https://192.168.86.151, https://127.0.0.1 {
	tls internal
	# kingfisher binds 127.0.0.1:8080 and enforces the AP trusted-device allowlist
	# itself; Caddy terminates TLS and passes the unspoofable real client IP.
	reverse_proxy 127.0.0.1:8080 {
		header_up X-Real-Client-IP {remote_host}
	}
}
http://kingfisher.lan, http://kingfisher, http://192.168.10.1, http://192.168.86.151, http://127.0.0.1 {
	redir https://{host}{uri} permanent
}
```
`sudo systemctl reload caddy`. The internal CA regenerates on a fresh build → re-trust the
new root cert on the tablets (see `deploy/caddy/README.md`; `sudo caddy trust` locally for
curl over https). `192.168.86.151` is the Pi's wlan1 address — DHCP-reserve it on the home
router so it stays put; mDNS (`kingfisher.lan`) also works and doesn't depend on the lease.

## Phase 12 — kingfisher app

```sh
cd ~/go/src/github.com/westphae
git clone https://github.com/westphae/kingfisher
# go.mod replace directives need the siblings — REQUIRED for the build:
git clone https://github.com/westphae/go-iio
git clone https://github.com/westphae/goflying
git clone https://github.com/westphae/geomag
git clone https://github.com/westphae/magkal

cd kingfisher && go install ./cmd/kingfisher
sudo install -m 755 deploy/poweroff/kingfisher-poweroff.sh /usr/local/bin/   # (path per repo)

# sudoers drop-in /etc/sudoers.d/kingfisher-poweroff (0440):
#   eric ALL=(root) NOPASSWD: /usr/local/bin/kingfisher-poweroff.sh

# user unit (template in repo, sed __KINGFISHER_BIN__ → ~/go/bin/kingfisher):
mkdir -p ~/.config/systemd/user
sed "s|__KINGFISHER_BIN__|$HOME/go/bin/kingfisher|g" \
  deploy/systemd/kingfisher.service.example > ~/.config/systemd/user/kingfisher.service

# log-spam guard drop-in ~/.config/systemd/user/kingfisher.service.d/log-rate-limit.conf:
#   [Service]
#   LogRateLimitIntervalSec=30s
#   LogRateLimitBurst=300

sudo loginctl enable-linger eric        # user service starts at boot — silent failure if missed
systemctl --user daemon-reload && systemctl --user enable --now kingfisher.service

# restore flight data + config from backup (optional; the app runs with empty dirs):
#   rsync -a <backup>/kingfisher/ ~/kingfisher/
#   rsync -a <backup>/.config/kingfisher/ ~/.config/kingfisher/
# A restored config.json must keep "http_addr": "127.0.0.1:8080" — the app binds
# loopback so Caddy is the sole ingress; a public bind lets AP clients skip the
# trusted-device allowlist by hitting :8080 directly.
```

## Phase 13 — airband receiver **[KEEP — decided 2026-07-12, active project]**

```sh
git clone https://github.com/rtl-airband/RTLSDR-Airband.git   # v5.2.0 as of 2026-07-12; cmake build
cd RTLSDR-Airband && mkdir build && cd build
cmake -DCMAKE_BUILD_TYPE=Release .. && make -j$(nproc) && sudo make install   # → /usr/local/bin/rtl_airband

# /etc/udev/rules.d/99-rtl-sdr.rules:
#   SUBSYSTEM=="usb", ATTRS{idVendor}=="0bda", ATTRS{idProduct}=="2838", SYMLINK+="rtl_sdr", MODE="0664", GROUP="plugdev"
#   SUBSYSTEM=="usb", ATTRS{idVendor}=="0bda", ATTRS{idProduct}=="2832", SYMLINK+="rtl_sdr", MODE="0664", GROUP="plugdev"
# /etc/modprobe.d/no-rtl.conf:
#   blacklist dvb_usb_rtl28xxu
```
Note: rtl_airband has historically been **run ad hoc, with no systemd unit enabled**
(repo `westphae/kingfisher-airband` has `deploy/airband.service`). Decide whether to
service-ify it or keep running it by hand.

## Phase 14 — verification checklist

```sh
vcgencmd get_throttled                    # 0x0 on bench power
cat /sys/bus/pci/devices/0001:01:00.0/current_link_speed   # 8.0 GT/s (PCIe gen3)
sudo dmesg | grep -iE 'aer|nvme.*timeout'  # no corrected-error spam at gen3
chronyc tracking                          # Reference ID ...(PPS), within ~15-20s of GPS fix
chronyc sources -v                        # GPS noselect + PPS locked
ss -xp | grep chrony                      # gpsd connected to both SOCKs
ls /sys/bus/iio/devices/                  # icm45686 + mmc5983ma present
systemctl --user status kingfisher        # active; journalctl --user-unit=kingfisher
curl -k https://192.168.10.1/             # caddy → app (from an AP client)
iw dev wlan0 get power_save               # off
journalctl -b -u 'systemd-fsck*'          # clean
sudo dmesg | grep "setting system clock"  # RTC held time across a cold boot
```

---

# CRUFT — deliberately not installed

These were found as junk on an earlier build and are intentionally left out; don't add
them back without a reason.

1. **Default `pi` user** — a fresh install with `userconf.txt` naming eric avoids the
   stock `pi` account entirely.
2. **Cursor IDE** — dev tool, not part of the unit. **Decision: omit**
   (reinstall ad hoc if wanted; its `/etc/sysctl.d/50-cursor.conf` goes with it).
3. **PDF/media tooling** (ghostscript, poppler-utils, qpdf, pymupdf/pypdf, pdfplumber,
   mkvtoolnix) — was for one-off Cursor-agent data analysis. **Decision: omit** (use `uvx`).
4. **`/opt/stratux/bin` in PATH** — **Decision: omit** (already dropped from the Phase 4 PATH line).
5. **Backup-file litter** (`chrony.conf.bak.*` ×6 etc.) — **Decision: omit**; etckeeper
   (now installed) replaces the habit.
6. **`rpi-connect-lite` / `mpris-proxy`** — don't install; rpi-connect is a relay/tunnel
   service, forbidden by the security posture (Appendix A).
7. **`rfkill_default.conf`** — **Decision: omit.**
8. **`rpi-usb-gadget`, `usb-modeswitch`, `cifs-utils`, `ntfs-3g`, `lua5.1/luajit`,
   camera/video stacks** (`rpicam-apps-lite`, `v4l-utils`, `kms++-utils`) — no evidence of use.
9. **bmp581-mod / icm42688-mod / icm20948-mod build trees** — experiments superseded by
   icm45686+mmc5983ma. They live only in ~/go/src (no system footprint); keep the repos,
   just don't install them.
10. **Wi-Fi firmware for other vendors** (atheros/libertas/mediatek/realtek) — keep only
    what wlan1's chipset actually needs (check before omitting).

# IMPROVEMENTS — forward-looking notes. The items already folded into the phases above
# (DKMS, watchdog, chrony→gpsd ordering, etckeeper) are marked inline. Power root-cause
# of the 2026-07-11 failure: an aging battery pack sagging below 40% charge — a proper
# aircraft supply is still needed (#4).

1. **Secure the AP.** The `kingfisher` network is **open** (no WPA). Anyone at the tiedown
   can join, get DHCP, reach the app and the GDL90 stream. Add WPA2-PSK
   (`wifi-sec.key-mgmt wpa-psk`); EFB apps handle it fine. Biggest single win.
2. **DKMS for the two kernel modules.** Today a routine `apt full-upgrade` that bumps the
   kernel silently breaks the IMU/magnetometer until you rebuild by hand — in the plane
   that's a dead sensor stack. Packaging icm45686-mod and mmc5983ma-mod as dkms modules
   makes rebuilds automatic. (Interim: `apt-mark hold linux-image-rpi-2712` before flights.)
3. **Hardware watchdog.** Pi 5 has one; set `RuntimeWatchdogSec=15` in
   `/etc/systemd/system.conf.d/watchdog.conf` so a hung system reboots itself in flight
   instead of needing a power pull.
4. **Power** (root cause of the 2026-07-11 failures): fit a proper 5 V/5 A supply from the
   aircraft bus. Undervoltage is now surfaced — kingfisher's `system` telemetry device polls
   the 5 V rail + `get_throttled` and shows a cockpit warning. Longer term: the supercap/UPS
   clean-shutdown path (the poweroff API and script already exist — a GPIO shutdown button
   via `dtoverlay=gpio-shutdown` is a cheap interim step).
5. **Codify the chrony→gpsd restart ordering** instead of remembering it: drop-in
   `/etc/systemd/system/gpsd.service.d/chrony-order.conf` with `PartOf=chrony.service`
   (+ existing `After=`), so restarting chrony automatically restarts gpsd.
6. **NTP fallback when GPS is absent.** The Debian pool is commented out, so indoors the
   clock free-runs from RTC. Consider re-adding the pool (it's ignored while PPS is
   selected, and wlan1 provides it a path when present) — or leave GPS-only if you prefer
   determinism; discuss.
7. **sshd hardening**: with keys in place, `PasswordAuthentication no` (the AP is open —
   see #1 — so ssh is exposed to anyone who joins).
8. **Put /etc under version control** (`sudo apt install etckeeper`, git backend). Every
   future tweak is then self-documenting — this playbook stops going stale, and the
   `.bak.*` litter habit dies.
9. **Automatic flight-data backup**: a timer that rsyncs `~/kingfisher/flights` to your
   workstation/cloud whenever wlan1 is online; 3.1 G of irreplaceable data currently
   lives on one device in an aircraft.
10. **Disable `apt-daily*` timers** (or set them `Persistent=false` + a maintenance window):
    background apt during preflight/flight adds I/O and, with #2 unsolved, could even
    swap a kernel out from under the sensors.
11. **Caddyfile hostnames**: replace the hardcoded home-LAN IP `192.168.86.151` with the
    mDNS name only, or add a wildcard — the IP changes with DHCP.
12. **fstrim** is already on (`fstrim.timer`) and fstab uses `noatime` — good for the SSD;
    nothing to do, just noting it's covered.

---

# Appendix A — Security posture (decided 2026-07-12)

**Threat model (Eric's, deliberate):** proximity threats (airport ramp, hangar
neighbors, formation traffic) are ACCEPTED — the AP stays **open**, ssh keeps
password auth, no firewall/fail2ban/WPA2. The concern that matters is internet
exposure while developing from home. Prefer lighter security; don't re-litigate this.

**The one rule that is the internet security:**

> **Never port-forward to this machine, and never run a relay/tunnel service on it**
> (rpi-connect was purged for this reason). Behind home NAT the Pi is unreachable
> from the internet; on the AP, only radio-range devices exist. That's the perimeter.

**Minimal viable set (all already in place):**
1. No port forwarding / no tunnel services — see above.
2. One decent password on `eric` — it gates ssh and the web terminal, and with
   `NOPASSWD: ALL` sudo it is effectively root. Protect it accordingly.
3. Caddy TLS (`tls internal`) — keeps that password unsniffable on the open AP.
   Zero ongoing cost; keep it.
4. journald persistence + etckeeper — not security, but the audit trail.

**Explicitly skipped (don't add back without a threat-model change):** WPA2 on the
AP, key-only sshd, fail2ban, nftables/ufw, port knocking.

**Web terminal + power API — gated to trusted AP devices** *(kingfisher-specific)*:
`/terminal` is a root-equivalent shell and `POST /api/power/off` is unauthenticated; on
the open AP both are one URL away for anyone in radio range. kingfisher enforces an AP
trusted-device allowlist itself (`internal/web/access.go`):

- it binds `127.0.0.1:8080`, so Caddy is the **sole ingress** — a public bind would let
  AP clients skip the gate by hitting `:8080` directly;
- it returns `403` on `/terminal*`, `/api/terminal/*`, `/api/power/*`, and `/api/access*`
  for AP-subnet clients whose IP is not in `config.access.trusted_ips`; everything off the
  AP (loopback, home LAN, Tailscale) is always allowed;
- Caddy passes the real client IP via `header_up X-Real-Client-IP {remote_host}` (Phase 11),
  which overwrites any client-sent value and so cannot be spoofed.

Manage the list from the cockpit UI (**More → Trusted devices** — lists AP clients, lets a
trusted device grant/revoke and name each); the EFBs are seeded trusted. Known limitation
(accepted): same-L2 IP spoofing defeats an IP allowlist — outside the threat model. Full
notes in `deploy/caddy/README.md`.

**Remote access from outside home (optional, when wanted):** do NOT port-forward —
install **Tailscale** on the Pi + laptop (zero-config WireGuard mesh; Pi reachable
from your devices anywhere, no open ports, nothing else gains access). The secure
option is also the convenient one here.

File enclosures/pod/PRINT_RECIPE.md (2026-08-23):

# Wing pod v3 — AnkerMake print recipe

Slicer settings for `pod_left.stl`, `pod_right.stl`, `tail_panel.stl`,
`static_bay.stl`, and `pm_tray.stl` on an **AnkerMake M5C** in **PETG**. STLs do not carry support or
slice settings — use this recipe in AnkerMake Studio (or PrusaSlicer with an
M5C profile).

Geometry / export contracts: [`REQUIREMENTS.md`](REQUIREMENTS.md). Layout:
[`pod_enclosure.md`](pod_enclosure.md). SUN-B fit: [`SUN_B_CALIPERS.md`](SUN_B_CALIPERS.md).

## Before slicing

1. Regenerate + validate (must exit 0):

   ```bash
   cd enclosures/pod && uv run --project .. python wing_pod_v3.py
   cd enclosures/pod && uv run --project .. python validate_pod.py --stl-only
   ```

2. Import each STL as a **single solid**. If Studio complains about a corrupt /
   multi-body mesh, re-export; do not “fix” in the slicer.
3. **Do not rotate or move anything** — orientation *and bed position* are baked
   into every STL. All five parts are exported already **centred on the bed**
   (110, 110) and sitting on z=0. If your slicer offers "load at model
   position", use it; if it auto-centres, that is the same result.
   A part parked on the origin corner slices with its skirt/brim at negative
   X/Y and the job is rejected with *"a toolpath outside the print area"*.
4. **Bed-edge budget.** Body halves leave **11.2 mm** from the part edge to the
   bed edge (X binds on `pod_right`, Y on `pod_left`). Everything drawn outside
   the object shares that margin:

   ```
   brim width + skirt distance + (skirt loops x ~0.45) <= 11.2 mm
   ```

   Skirt distance is measured **from the brim**, not the object. The stock
   6 mm skirt distance on top of a 5 mm brim is 11.4 mm and the job is rejected
   with *"a toolpath outside the print area"*.

   | Brim | Skirt | Loops | Outermost | |
   |------|-------|-------|-----------|--|
   | 5 | off | - | 5.0 | **use this** |
   | 5 | 3 | 1 | 8.4 | ok, keeps a flow check |
   | 5 | 6 | 1 | 11.4 | rejected |
   | 8 | 6 | 1 | 14.4 | rejected |

   The M5C draws its own prime line, so the skirt is not needed for priming.
   Do **not** drop the skirt below ~2 mm: printed flange-down, the first layer
   *is* the mating face, and a skirt that fuses to it leaves a ridge on the
   sealing surface (S2).

## Orientation (as-exported)

| File | On the bed | Notes |
|---|---|---|
| `pod_plate.stl` | **Outer skin DOWN**, cavity up, **45°** diagonal | Board plate — the part you reprint |
| `pod_bowl.stl` | Same | Deep half: SUN cradle, battery, aft rim |

**Outer skin down, not flange down.** Flange-down puts the cavity ceiling and
every inward-hanging feature over open air; print-3 came out packed with
support throughout the inside. Measured on the real halves at a 45° threshold:

| part | flange-down | outside-down |
|---|---|---|
| plate | 11782 mm² support, 2096 bed | **8399** (−29 %), **5288** bed |
| bowl | 12337 mm² support, 2610 bed | **8666** (−30 %), **6037** bed |

The flank is flat over the whole midbody, so the first layer is a large flat
face instead of a thin flange ring. Two consequences worth knowing:

- The **mating face is now the top surface**. Give it enough top layers to come
  out flat, and check it with a straightedge before trusting the gasket (S2).
- The **aero skin takes the bed finish**, and the brim attaches to its
  perimeter. Print on a smooth sheet if you want a smooth outer surface, and
  expect to dress the brim witness line near the parting line.
| `tail_panel.stl` | Large face down | Aft service plate — the face with the counterbores goes **up** |
| `static_bay.stl` | **Closed face down** | BMP plenum cup; tabs overhang slightly at the top |
| `pm_tray.stl` | Large face down | Pro Micro clamp tray |

Print one half at a time if the diagonal + skirt crowds the bed. The SUN-B
adapter is purchased metal — not printed.

## Supports

| Part | Supports | Why |
|---|---|-----|
| `pod_left` / `pod_right` | **On** | Ogive outer, hollow shell, SUN cradle, standoffs (right) leave overhangs above ~45° |
| `tail_panel` | **Off** | Flat plate |
| `static_bay` | **Off** | Shallow cup, tabs are a short overhang |
| `pm_tray` | **Off** | Flat tray |

Suggested support settings (tune after first preview):

- Type: **tree / organic** if available (cleaner on the outer skin); else normal
- Overhang threshold: **45–50°**
- Top Z contact / interface: on (easier peel from PETG)
- Prefer **not** filling small holes (static array, insert pilots, cradle bore,
  and especially the **labyrinth drain** — its channel is a 2 mm internal
  passage) if the slicer offers paint-on; clear those in preview

After a good slice, **File → Save Project** as a `.3mf` next to the STLs if you
want a reusable Studio snapshot (mesh + these settings). Plain mesh-only 3MF
export usually drops support/config.

## Material & quality (starting point)

Use the stock **AnkerMake M5C + PETG** profile, then:

| Setting | Suggested |
|---|---|
| Nozzle | 0.4 mm |
| Layer height | 0.20 mm (0.16 mm if outer fairing finish matters more than time) |
| Walls / perimeters | ≥ 3 |
| Top / bottom layers | ≥ 4 |
| Infill | 15–25% gyroid or grid |
| Bed adhesion | Brim **5 mm**, skirt **off** (see step 4 — 11.2 mm to the bed edge) |
| Cooling | PETG-moderate (avoid max fan on first layers) |

Temperatures: follow your PETG brand / Studio preset. Dry filament if the outer
skin looks fuzzy or stringy.

## After print

1. Remove supports carefully from the outer skin (cosmetic + aero face).
2. Deburr mating flange, SUN cradle bore / barb bay, panel USB/rocker/LED holes,
   static holes, screw paths.
3. Install **M2.5 heat-set inserts** in the **right** flange + **every board
   standoff** (including Pro Micro clamp posts) + the four static-bay land inserts + the
   four **aft-panel** bosses (no self-tap, no nubs). Flange and board inserts go
   in from the **open mating face** (iron along Y) before installing PCBs; BMP
   through the static-bay window; aft-panel inserts from **outside the base**
   (iron along X). Left cover is clearance only. Same pilot/depth/screw-relief
   scheme as the hub case. Seat the Pro Micro in `pm_tray.stl` and screw the
   tray down, mount the BMP581 and heat-set its inserts on the OPEN wall, then screw `static_bay.stl` over it on a foam/RTV gasket.
4. **Populate `tail_panel.stl` on the bench, before it goes on the pod** — this
   is the whole point of it being a separate plate. Snap in the COM-08837
   rocker (SYSOFF → JP12 / GND; leave onboard S1 OFF). RTV the CAB-15464 flange
   and fasten with M3 + nuts (trim the included 14 mm screws or use M3×8). Press
   the 5 mm LEDs into their chrome holders and fit the jam nuts: red = VOUT (pod
   powered), blue = `!CHG!`. Leave a service loop on the harness — the plate has
   to come away from the base to be worked on.
5. Dry-fit L/R halves around the **SUN-B** (barbs up; **45 mm** protruding; the
   Ø10.65→Ø11.76 step seated on the nose bulkhead; aft recess on the locating
   boss) before final assembly. Plumb 6 mm hose → COTS reducer
   → MS4525; cap the forward TE barb.

## Checklist

- [ ] `validate_pod.py` green on the STLs you are about to load
- [ ] No slicer rotation **or repositioning** on either half
- [ ] Brim 5 mm and skirt off (or skirt ≤ 3 mm); no toolpath crosses the bed boundary in preview
- [ ] Supports on for both body halves; preview cleared of plugged holes
- [ ] Labyrinth drain channel open in preview (2 mm internal passage)
- [ ] `tail_panel` populated on the bench before fitting to the base
- [ ] Brim on; fits bed at 45°
- [ ] Inserts heat-set before first assembly torque
- [ ] SUN-B dry-fit + hose routing checked before flight hardware

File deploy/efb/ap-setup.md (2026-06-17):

# Pi AP setup for EFB apps (ForeFlight, iFlyEFB)

Use when the Pi runs the **`kingfisher`** Wi‑Fi access point (NetworkManager
`ipv4.method: shared` on `wlan0`, typically **`192.168.10.1/24`**) and tablets
should receive GDL90 from kingfisher.

Kingfisher broadcasts Stratux-compatible GDL90 on UDP port **4000**. Enable in
`~/.config/kingfisher/config.json`:

```json
"gdl90": {
  "enabled": true,
  "static_ips": ["192.168.10.141", "192.168.10.40"]
}
```

On a NetworkManager AP, DHCP is served by **dnsmasq**. Kingfisher’s lease
parser expects **isc-dhcp** format (`dhcpd.leases`), so **`static_ips` is the
reliable client list** on this topology until dnsmasq lease parsing lands.
`dhcp_leases` in config is ignored for discovery here; reservations below keep
those IPs stable.

## 1. DHCP reservations (recommended)

Pin each tablet by MAC so it always gets the same address in the pool
(`192.168.10.10`–`192.168.10.254`).

### Find MAC addresses

After a device joins `kingfisher`:

```bash
sudo cat /var/lib/NetworkManager/dnsmasq-wlan0.leases
```

Columns: `epoch MAC IP hostname clientid`.

### Disable randomized Wi‑Fi MAC

iOS and Android may use a **different MAC per network**. Turn that off for
`kingfisher` or reservations will drift:

- **iPad:** Settings → Wi‑Fi → `i` on `kingfisher` → **Private Wi‑Fi Address**
  → **Off**
- **Android:** Wi‑Fi → `kingfisher` → details → **Privacy** / **MAC address
  type** → **Use device MAC** (wording varies by OEM)

Forget the network, rejoin, and confirm the MAC in the leases file again.

### Add dnsmasq host entries

```bash
sudo tee /etc/NetworkManager/dnsmasq-shared.d/kingfisher-efb.conf <<'EOF'
dhcp-host=aa:bb:cc:dd:ee:01,192.168.10.141,iPad
dhcp-host=aa:bb:cc:dd:ee:02,192.168.10.40,Pixel
EOF
```

Replace MACs and IPs with yours. Restart the hotspot:

```bash
nmcli connection down kingfisher && nmcli connection up kingfisher
```

On each device: **Forget** `kingfisher`, reconnect, verify the assigned IP in
Wi‑Fi details.

### Match `static_ips`

List the same IPs in `gdl90.static_ips` and restart kingfisher.

## 2. Device-side static IP (optional)

Prefer Pi DHCP reservations. If you set a manual IP on the tablet instead:

| Field | Value |
|---|---|
| IP | e.g. `192.168.10.141` |
| Subnet mask | `255.255.255.0` |
| Router / gateway | `192.168.10.1` |
| DNS | `192.168.10.1` |

Still add that IP to `gdl90.static_ips`.

## 3. EFB app settings

**ForeFlight:** connect to `kingfisher` → *More* → *Devices* → enable GDL90 at
**`192.168.10.1`**.

**iFlyEFB:** *Menu* → *About* → *Connected Devices* → *Wireless Device* →
Stratux/FlightBox; *Setup* → *ADS-B* → select Stratux/Flightbox manually
(auto-detect often fails). Heartbeat should increment; expect **GPS Data Only**
(no ADS-B traffic/weather from kingfisher).

**Android:** disable smart network switching / “switch to mobile data when Wi‑Fi
is poor”; force-quit other aviation apps if GDL90 does not bind.

Requires `ahrs.enabled` for attitude.

## 4. Verify

```bash
curl -s http://127.0.0.1:8080/api/status | jq .gdl90
sudo tcpdump -i wlan0 -n udp port 4000
```

Expect `clients` ≥ 1, rising `msgs_sent`, and `192.168.10.1` → each tablet IP
on port 4000.

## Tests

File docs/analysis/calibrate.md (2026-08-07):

# Stationary calibration

Bench procedures for cabin ICM-45686 (accel and gyro separately) and pod mag
(MMC5983). Guided UI: cockpit **More → Calibrate** (`#/calibrate`).

## Cabin accelerometer (6-face)

1. Place the case on a **table**, on each of six faces (`+Z…−Y`), any order.
2. **Do not** tip by hand — motion corrupts \(\lVert a\rVert = g_0\).
3. App detects the face from the dominant accel axis + sign.
4. Hold still → green countdown (~2.5 s) → ~8 s hub average → next face.
5. Accept programs **accel** `calibbias` (OFFUSER) and saves diagonal scale
   (software-only) into `calibration.cabin_imu`.

## Cabin gyro (still dwell)

Six-face gyro means showed no meaningful orientation dependence (face scatter
~0.002–0.015 °/s). Gyro cal is therefore a **single** still average:

1. Place the case on the table in **any** stable orientation.
2. Stillness is monitored for the **whole** ~30 s window (accel variance +
   ‖ω‖); the UI warns if you bump/tilt. Accept remains allowed (imperfect but
   better than nothing — e.g. in-flight).
3. ~**30 s** hub average of `icm45686-gyro` (+ die `temp_c`).
4. Accept bakes OFFUSER to \(T_\mathrm{ref}\):
   \(\mu_\mathrm{ref}=\bar\omega-\Delta b(T_\mathrm{cal})\) using
   `calibration.gyro_tco` — see [gyro_tco.md](gyro_tco.md).
5. UI boldface peels \(\Delta b(T)\) only after `gyro_offuser_applied`.

OFFUSER programming writes `calibbias` while capture stays live — the ICM-45686
driver quiets the chip FIFO briefly and shadows values across ODR/FS changes.
Accept uses `SetNoNotify` so a config save does not needlessly restart buffers.

Accel and gyro Accepts merge into the same `calibration.cabin_imu` object and
do not overwrite each other’s fields. Artifacts:
`~/kingfisher/calibration/cabin_accel_*.json` and `cabin_gyro_*.json`.

## Pod magnetometer (6-face)

Same place-and-hold ritual on the pod case; diagonal soft-iron + hard-iron.

## OFFUSER / soft display

| Flag | Soft constant bias | Soft other |
|---|---|---|
| `accel_offuser_applied` | skip accel \(l\) | scale \(k\) always soft |
| `gyro_offuser_applied` | skip gyro constant | \(\Delta b(T)\) always soft when table present |

Legacy `offuser_applied` alone is treated as both sensors programmed (migrated
on config load).

**Flight DB samples stay raw** (IIO after on-chip OFFUSER).

## Fits (magkal analogs)

| Target | Model |
|---|---|
| Accel | \(a_{\mathrm{corr},i}=k_i(a_{\mathrm{raw},i}-l_i)\), \(\lVert a_{\mathrm{corr}}\rVert\approx g_0\) |
| Gyro | Bias = mean \(\bar{\boldsymbol{\omega}}\) over one still dwell @ \(T_\mathrm{cal}\) |
| Mag | Diagonal soft-iron + hard-iron from opposite-face pairs |

**Full \(3\times3\,K\)** is not fit from six faces alone.

Quality:

- Warn if mean \(\lVert a_{\mathrm{corr}}\rVert\) is >0.5% from \(g_0\).
- Warn if face off-axis residual is large (case skew; still accepted).
- Mag: warn if \(\lVert B\rVert\) scatter after correction is large.

## Offline

```bash
uv run --project analysis python scripts/analyze_flights.py cal-accel \
  --json ~/kingfisher/calibration/cabin_accel_….json --plot
```

See also `analysis/cal_accel.py`, [PLAN.md](PLAN.md) Phases 2–3, and
[`../icm45686-bias-compensation.md`](../icm45686-bias-compensation.md) (driver
OFFUSER contract).

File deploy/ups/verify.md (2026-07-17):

# X1200 UPS HAT — bring-up & verification

The Geekworm X1200 (2×18650, 1S2P) powers the Pi 5 via pogo pins and exposes:

- **MAX17040 fuel gauge** — I²C bus 1 @ `0x36` (cell voltage + modeled SOC; no
  current sense). Bus 1 is shared with the icm45686 IMU at `0x68` (kernel
  driver) — userspace must never address 0x68.
- **Power-loss detect** — GPIO6, input: 1 = external power present, 0 = lost.
- **Charge control** — GPIO16: drive high = disable charging. Kingfisher
  deliberately **never claims GPIO16**; unclaimed (Pi pull-down) it stays at
  the board default, charging enabled.

Policy: run-to-floor. On power loss the recorder keeps recording and powers
off cleanly (flush + WAL checkpoint, then the poweroff sudo helper — see
`deploy/poweroff/verify.md`) only when a debounced floor is reached:
SOC ≤ 10% (on battery) or cell ≤ 3.20 V (any state). Optional
`shutdown_after_s` ride timer, off by default.

## 1. One-time host setup

```sh
sudo modprobe i2c-dev
echo i2c-dev | sudo tee /etc/modules-load.d/i2c-dev.conf
ls -l /dev/i2c-1        # root:i2c — the service user must be in group i2c
```

`dtparam=i2c_arm=on` must be set in `/boot/firmware/config.txt` (it already
is on kingfisher). The service user also needs group `gpio` for
`/dev/gpiochip0`.

## 2. Hardware sanity (HAT attached)

```sh
i2cdetect -y 1                 # 36 present, 68 shows UU (kernel-owned IMU)
i2cget -y 1 0x36 0x08 w        # VERSION: 0x0200 byte-swapped -> 0x0002
i2cget -y 1 0x36 0x02 w        # VCELL: swap bytes, ×1.25/1000/16 -> volts
i2cget -y 1 0x36 0x04 w        # SOC:   swap bytes, /256 -> percent
gpioget --chip gpiochip0 --bias=pull-up 6    # "active" with power present
```

(`i2cget -w` words are SMBus little-endian; kingfisher's raw reads are
MSB-first and need no swap.)

## 3. Enable

`~/.config/kingfisher/config.json`:

```json
"ups": { "enabled": true }
```

Defaults: 1 Hz poll, SOC floor 10%, voltage floor 3.20 V, ride timer off.
Restart the service; journal shows `ups: MAX17040 present (version 0x0002)`.

## 4. Verify

- `curl -s localhost/api/status | jq .ups` → `present: true, ac_ok: true`.
- Header shows the `⚡ NN%` chip; `ups` device tab lists live values.
- `sqlite3 <flight.db> "SELECT * FROM ups ORDER BY ts_ns DESC LIMIT 3"`.

## 5. Bench power-loss test

Pull the X1200's USB-C input (batteries installed):

- Chip flips to `🔋 NN%`; `ac_ok=0` rows land in the DB; after ~2 min of
  measurable discharge an estimated time remaining appears.
- Re-plug: chip returns to `⚡`, on-battery timer resets.
- To exercise the shutdown path without draining the pack: temporarily set
  `"shutdown_soc_pct"` just below the current SOC, pull input, wait 3 polls →
  clean shutdown, then poweroff. On repower check the breadcrumb:
  `SELECT value FROM metadata WHERE key='ups_shutdown'`.

## Notes

- The X1200 auto-powers the Pi when input power appears, and drops its output
  a few seconds after it stops detecting a running Pi. Verify on the bench
  what it does after `systemctl poweroff` on this board revision; if it holds
  5 V, use the HAT's switch for storage so the cells don't drain.
- Never power the Pi through its own USB-C while the HAT is attached; use
  unprotected flat-top 18650s per Geekworm's guidance.
- Charging at cabin temps above ~45 °C is outside Li-ion charge spec — mind
  hot-day ground soaks.

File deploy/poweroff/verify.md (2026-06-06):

# Cockpit power off

The header **OFF** button calls `POST /api/power/off`, which pauses recording
(flush + WAL checkpoint), shuts down kingfisher cleanly, then runs
`/usr/local/bin/kingfisher-poweroff.sh` to `sync` and `systemctl poweroff`.

## Install helper

```bash
sudo install -m 755 deploy/kingfisher-poweroff.sh /usr/local/bin/
sudo tee /etc/sudoers.d/kingfisher-poweroff <<'EOF'
eric ALL=(root) NOPASSWD: /usr/local/bin/kingfisher-poweroff.sh
EOF
sudo visudo -cf /etc/sudoers.d/kingfisher-poweroff
```

Replace `eric` with your Pi login user. Optional override in `config.json`:

```json
"clock": {
  "poweroff_helper": "/usr/local/bin/kingfisher-poweroff.sh"
}
```

## microSD hygiene

- Prefer **OFF** (or `systemctl --user stop kingfisher` then `sudo poweroff`) over
  cutting aircraft power while the Pi is running.
- Kingfisher checkpoints SQLite WAL on pause and on DB close; the helper runs
  `sync` twice before poweroff.
- Use a quality card; keep free space on the boot volume (status drawer shows DB
  volume free bytes).
- After unclean power loss, run `fsck` on the card before the next flight if
  the Pi fails to boot or SQLite reports corruption.

The user systemd unit example sets `TimeoutStopSec=45` so SIGTERM shutdown has
time to flush before systemd sends SIGKILL.

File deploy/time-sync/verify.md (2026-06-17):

# Time-Sync Verification

Use after configuring `gpsd` and `chrony` per `docs/time-sync.md`.

## 1. gpsd sees the receiver

```bash
systemctl is-active gpsd    # must be active, not just gpsd.socket
cgps -s
```

Check that:

- the device is `/dev/ttyAMA0`
- fixes keep updating
- GPS time is non-zero

## 2. PPS (if wired)

```bash
ls -l /dev/pps0
sudo ppstest /dev/pps0
gpsmon    # look for "PPS offset:" near sub-millisecond
```

## 3. chrony is using GPS / PPS

```bash
chronyc tracking
chronyc sources -v
chronyc sourcestats
```

Check that:

- GPS and PPS have non-zero **Reach** (octal column in `sources -v`)
- with pool commented out: **`#* PPS`** within ~1 min of 3D fix, and **`#? GPS`**
  (serial source present but `noselect` — the `?` is **expected**, not an error)
- GPS **`sourcestats` Offset** ≈ serial latency (a few hundred ms is fine with
  `noselect`); PPS offset in µs
- `Leap status` is normal after lock

If Reach stays 0 after a chrony restart:

```bash
sudo systemctl restart chronyd && sleep 2 && sudo systemctl restart gpsd
```

## 4. kingfisher agrees

Open the cockpit UI and confirm the header clock badge shows:

- a fresh GPS fix age
- skew under about 250 ms once settled (fix-epoch lag ~650 ms is normal)
- no persistent `startup fallback` warning after a clean synchronized boot

### Boot-time wrong-second check

If `kingfisher-clock-check` is installed (see `docs/time-sync.md` §8a):

```bash
journalctl -b -u kingfisher-clock-check
```

Expect `OK: ... within latency band — second-numbering looks correct`. A
`WARN: ... possible WRONG-SECOND clock error!` means PPS locked to the wrong UTC
second (check the GPS fix/almanac and RTC sanity) — it never changes the clock.

## 5. Troubleshooting

See the table in `docs/time-sync.md`. Common fixes:

- enable and start `gpsd.service` at boot
- restart `gpsd` after every `chronyd` restart
- if both GPS and PPS sit `#x` (“no majority”), ensure the GPS refclock has
  `noselect` (`docs/time-sync.md` §4) — do **not** tune `offset`
- comment `pool pool.ntp.org` for offline GPS/PPS discipline

## 6. In-flight resync helper (optional)

For the cockpit **Restart time services** button (`POST /api/clock/resync` level
`full`), install the helper and grant passwordless sudo to the kingfisher runtime
user:

```bash
sudo install -m 755 deploy/time-sync/kingfisher-resync-time.sh /usr/local/bin/
sudo tee /etc/sudoers.d/kingfisher-resync <<'EOF'
eric ALL=(root) NOPASSWD: /usr/local/bin/kingfisher-resync-time.sh, /usr/bin/chronyc
EOF
sudo visudo -cf /etc/sudoers.d/kingfisher-resync
```

Set `clock.resync_helper` in `~/.config/kingfisher/config.json` if you use a
non-default path. **Retry sync** (light) uses `chronyc reselect` only and needs no
sudo. Auto-retry runs the light path on a cooldown when unsynced with a fresh GPS
fix.

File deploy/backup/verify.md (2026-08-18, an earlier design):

# Flight-data backup — setup & verification

Pushes closed flight DBs from the Pi (`~/kingfisher/flights`) to the home NAS
whenever the Pi is on the home LAN. The aircraft has ~6 GB of irreplaceable flight
data on a single device; this closes that gap without any manual `rsync`.

- **NAS:** an **Asustor AS5304T (ADM)** at `192.168.86.40`, share **`Public` →
  `/volume1/Public`**, target `Public/data/kingfisher/flights`. (The ADM web admin
  at `https://192.168.86.40:5679` is unrelated to the backup transport.)
- **Transport (config `TRANSPORT`):** `rsyncd` (ADM Rsync Server — the "rsync" you
  enabled; Asustor's supported path, no shell account, scoped to the share) or
  `ssh` (rsync over SSH — encrypted + key-based, but ADM restricts admin SSH so it
  may refuse with "connection closed"/"not allowed at this time"). **Default and
  recommended: `rsyncd`.**
- **Triggers:** NM dispatcher on **wlan1 up** (primary) + an **hourly timer**
  fallback. Both no-op when wlan1 has no address (i.e. in the aircraft) or the NAS
  is unreachable.
- **Safety:** additive only (no `--delete`); the live DB and every `-wal`/`-shm`
  sidecar are excluded, so only closed, consistent DBs are copied. Runs `Nice=10 /
  idle` I/O so it never contends with the recorder.

## Files

| File | Installs to |
|---|---|
| `kingfisher-flight-backup.sh` | `/usr/local/bin/` (0755) |
| `kingfisher-backup.conf.example` | `/etc/kingfisher-backup.conf` (0640 root:eric) |
| `kingfisher-flight-backup.service` | `/etc/systemd/system/` (0644) |
| `kingfisher-flight-backup.timer` | `/etc/systemd/system/` (0644) |
| `90-kingfisher-backup` | `/etc/NetworkManager/dispatcher.d/` (0755, root) |

## 1. NAS side (one-time, in ADM)

1. **Create the target folder.** ADM → File Explorer → under **Public** create
   `data/kingfisher/flights` (on disk: `/volume1/Public/data/kingfisher/flights`).

Then set up **one** transport:

### Option A — `rsyncd` (recommended)

2. ADM → **Backup & Restore → Rsync Server** → enable it.
3. Add a backup user (e.g. `kingfisher`) with a password, and grant it the module
   that maps to the **Public** share. Note the **module name** — set `RSYNC_MODULE`
   and `RSYNC_USER` in the conf to match (defaults assume module `Public`).
4. On the Pi, drop the password into the secret file (referenced by `RSYNC_SECRET`):
   ```sh
   mkdir -p ~/.config/kingfisher
   printf '%s' 'THE_RSYNC_PASSWORD' > ~/.config/kingfisher/backup.secret
   chmod 600 ~/.config/kingfisher/backup.secret     # rsync refuses it otherwise
   ```

### Option B — `ssh`

2. ADM → **Services → Terminal & SNMP → SSH** → enable, port 22 (Administrators
   group only; use `admin` or another admin account as `SSH_USER`).
3. Generate + authorize a dedicated key on the Pi:
   ```sh
   ssh-keygen -t ed25519 -N '' -C 'kingfisher-flight-backup' -f ~/.ssh/kingfisher_backup
   ssh-copy-id -i ~/.ssh/kingfisher_backup.pub -p 22 admin@192.168.86.40
   ssh -i ~/.ssh/kingfisher_backup admin@192.168.86.40 'ls -ld /volume1/Public/data/kingfisher/flights'
   ```
   Optionally harden: prefix the new `authorized_keys` line on the NAS with
   `from="192.168.86.151",restrict ` so the key works only from the Pi's wlan1 IP
   and can't open a shell.
   > If SSH returns "connection closed"/"not allowed at this time", ADM is
   > restricting admin SSH — use Option A.

## 2. Pi side — install

```sh
cd ~/go/src/github.com/westphae/kingfisher
sudo install -m 755 deploy/backup/kingfisher-flight-backup.sh    /usr/local/bin/
sudo install -m 640 deploy/backup/kingfisher-backup.conf.example /etc/kingfisher-backup.conf
sudo chown root:eric /etc/kingfisher-backup.conf
sudo install -m 644 deploy/backup/kingfisher-flight-backup.service /etc/systemd/system/
sudo install -m 644 deploy/backup/kingfisher-flight-backup.timer   /etc/systemd/system/
sudo install -m 755 deploy/backup/90-kingfisher-backup /etc/NetworkManager/dispatcher.d/

sudoedit /etc/kingfisher-backup.conf      # set TRANSPORT + fill that block
sudo systemctl daemon-reload
sudo systemctl enable --now kingfisher-flight-backup.timer
```

## 3. Verify

```sh
# Manual run (must be on the home LAN, wlan1 up):
sudo systemctl start kingfisher-flight-backup.service
journalctl -u kingfisher-flight-backup.service -n 40 --no-pager
# Expect: "excluding active DB <name>" (if recording), then "backup complete".

# Confirm files landed (rsyncd):
rsync rsync://kingfisher@192.168.86.40/Public/data/kingfisher/flights/ \
  --password-file ~/.config/kingfisher/backup.secret | tail
# ...or (ssh):
ssh -i ~/.ssh/kingfisher_backup admin@192.168.86.40 'ls /volume1/Public/data/kingfisher/flights | tail'

# Timer scheduled?
systemctl list-timers kingfisher-flight-backup.timer --no-pager

# Dispatcher wired:
sudo /etc/NetworkManager/dispatcher.d/90-kingfisher-backup wlan1 up
journalctl -u kingfisher-flight-backup.service -n 10 --no-pager
```

### No-op cases (all expected, logged, exit 0)

- **In the aircraft** (`wlan1` down): `"wlan1 has no global address; not home — skipping"`.
- **NAS off/unreachable:** `"192.168.86.40:<port> unreachable; skipping"`.
- **Overlapping run:** `"another backup is already running; skipping"`.

### Notes

- **No `--delete`:** the NAS keeps every DB ever pushed even after the Pi's local
  copy is cleaned. Prune the NAS side manually if it ever grows too large.
- **Active DB:** the DB kingfisher currently holds open is skipped (detected from
  `/proc/<pid>/fd`, else the newest `.db`) and is picked up on the next run once
  the flight closes. Sidecars are never copied, so closed DBs are consistent
  snapshots (the store's startup sweep + graceful-close cleanup keep closed DBs
  sidecar-free anyway).
- **First sync** copies the whole backlog and may take hours over wifi;
  `--partial` makes it resumable across dropped connections. The oneshot has
  `TimeoutStartSec=infinity` so a long rsync is not killed at the hourly timer
  tick (`flock` still skips overlapping starts).

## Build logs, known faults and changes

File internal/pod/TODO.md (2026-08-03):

# Pod ↔ Pi: attrs in flight DB and wire

## Done (Pi)

- `sensor_attrs` rows for wing chip devices (`bmp581`, etc.) with `location=pod` on Hello,
  config reload (diff), and successful `SetRate` Ack.
- Rows include `sampling_frequency` plus Hello cap metadata (`min_hz`, `max_hz`,
  `default_hz`) when caps are known.

## Later: Hello carries applied chip attrs

Today `Hello` only advertises `SensorCap` (min/max/default Hz). The firmware
already applies BMP581/MMC5983/MS4525 driver settings at boot, but the Pi infers
rates from `config.json` + caps, not from an explicit attr snapshot on the wire.

**Plan:**

1. Extend `pod_wire::Hello` (or nested cap struct) with optional applied attrs
   per sensor (ODR, oversampling, filter, etc.) — postcard-stable field adds.
2. Populate in `firmware/pod/src/hello.rs` from actual driver state after init.
3. Pi: on `applyHello`, log those rows to `sensor_attrs` (source of truth =
   pod, not Pi cache).

## Done: BMP581 OSR / IIR via SetAttr

`AttrKey::{BmpOsrPress,BmpOsrTemp,BmpIirPress,BmpIirTemp}` + firmware
`bmp_cfg` / `bmp581` apply path. Config keys:

- `in_bmp581_sampling_frequency` (cruise default **25**)
- `in_bmp581_oversampling_pressure` / `_temp` (multipliers; default **32** / **2**)
- `in_bmp581_iir_pressure` / `_temp` (coeffs 0=bypass,1,3,…; default **3**)

## Done: MMC5983 bandwidth via SetAttr

`AttrKey::MmcBandwidth` + firmware `mmc_cfg` / IC1 BW apply. Config keys:

- `in_mmc5983_sampling_frequency` (cruise default **20** — exact CM_Freq step)
- `in_mmc5983_bandwidth` (100 / 200 / 400 / 800 Hz; cruise **100** = lowest noise)

## Later: more configurable chip registers

- MS4525 attrs via the same `SetAttr` pattern.
- MMC5983 periodic SET (`En_prd_set`) if long-flight offset drift needs it.
- Ack + rollback for BMP/MMC attrs (today optimistic cache like DesignCapacity without chip confirm).
- Log attr changes to `sensor_attrs` on successful Ack.

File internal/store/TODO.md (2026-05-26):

# Flight DB: metadata table

The `metadata` table is created at DB bootstrap but **nothing writes to it yet**
(`SetMeta` exists in `store.go` but has no callers). `_session` holds the
startup snapshot; `sensor_attrs` holds per-device configuration history.

## Future uses for `metadata`

- Final geomagnetic declination after GPS lock (today only `_session.declination`
  is seeded to 0 at startup).
- Pod firmware version / wire revision echoed from `Hello` (complement `_session.version`).
- Effective `config.json` hash or path at flight start for reproducibility.
- User flight notes mirrored from config if we want them queryable without parsing config.
- AHRS tuning or calibration blobs that do not fit `sensor_attrs` rows.

Handle in a later pass; do not block pod attr logging on this.

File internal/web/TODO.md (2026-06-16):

# Web UI — deferred cleanup

Low-priority findings from the 2026-06-05 adversarial review of the Howgozit +
iPad-tap work. The medium-priority items (silent `patchCell` save failures; three
overlapping row-dialog flush mechanisms) were fixed in that pass. The items below
are cleanup/consistency, not correctness-critical — safe to defer.

## Bloat / churn residue

- **L1 — Duplicated field-parsing.** `parseRowAddFieldPanel` (`static/howgozit.js`)
  and `parseNewColumnForm` are ~80% identical (type/unit/step/options/uppercase).
  Extract a shared `parseFieldDefinition(root)` so fixes apply to both.
- **L3 — Dead variable `mounted`** (`static/howgozit.js`): assigned in `mount()`,
  never read. Remove, or use it to assert mount before API calls.
- **L7 — Orphaned CSS** `.instList` / `.instList li` / `.instIcon`
  (`static/app.css`): referenced in no JS/HTML (grep-confirmed). Confirm the
  instruments view markup, then delete.

## Improperly-applied-patch leftovers

- **L2 — Vestigial `*-wired` guards.** `wireCompassSettings` / `wireAirspeedSettings`
  (`static/app.js`) open with a `dataset.compassWired/airspeedWired === '1'` guard,
  but `renderAttrs` strips that attribute immediately before calling them, so the
  guard never fires. Either delete the guard lines or stop stripping the attribute —
  given the `innerHTML`-replace render model, deleting the guard is correct.
- **L5 — `rowid` equality inconsistency.** `patchCell` uses raw `r.rowid === rowid`
  while every other lookup uses `Number(r.rowid) === rid`. Works today (JSON ids are
  numbers); brittle if the API ever returns a string id. Normalize to one form.

## Consistency / hygiene

- **L4 — `.clockWarn` orphan class.** Used in `static/app.js` to highlight clock
  cause / stale-GPS warnings, but no CSS rule exists. Add
  `.clockWarn { color: var(--warn); font-weight: 700; }`. (May predate the 2026-06-05
  batch — verify.)
- **L6 — Two `escapeHtml` implementations.** `app.js` `escapeHtml` escapes only
  `& < >` (relies on a separate `escapeAttr` for attribute contexts); `howgozit.js`
  `escapeHtml` also escapes `"`. Both individually safe; consolidate to one shared
  util to avoid a future mismatch.
- **L8 — CSS hygiene (optional).** Tap-target magic numbers `44px`/`52px` (~15×) →
  `--tap-target` / `--btn-height` vars; hardcoded accents `#ff7ce0`, `#051125` →
  vars; near-duplicate `.hgz-row-*` dialog-button rules → a `.hgz-btn` base; 7×
  deprecated `-webkit-overflow-scrolling: touch` (no-op on modern iOS) droppable.

## Surfaced by the new JS tests (internal/web/jstest)

- **`parseTimeToTsNs` incomplete colon input** (`static/howgozit.js`): empty HH
  or MM parts in legacy `HH:MM[:SS]` input are rejected (returns null). Digit
  forms `HHMM` / `HHMMSS` are preferred.

## Related (surfaced while fixing M1)

- `addRow` and `deleteRow` (`static/howgozit.js`) still fail silently via
  `console.error` (no pilot-visible feedback), unlike cell edits now. `createLog`
  uses `alert()`. Consider a single small toast/error surface for all
  howgozit mutations so the UX is uniform.

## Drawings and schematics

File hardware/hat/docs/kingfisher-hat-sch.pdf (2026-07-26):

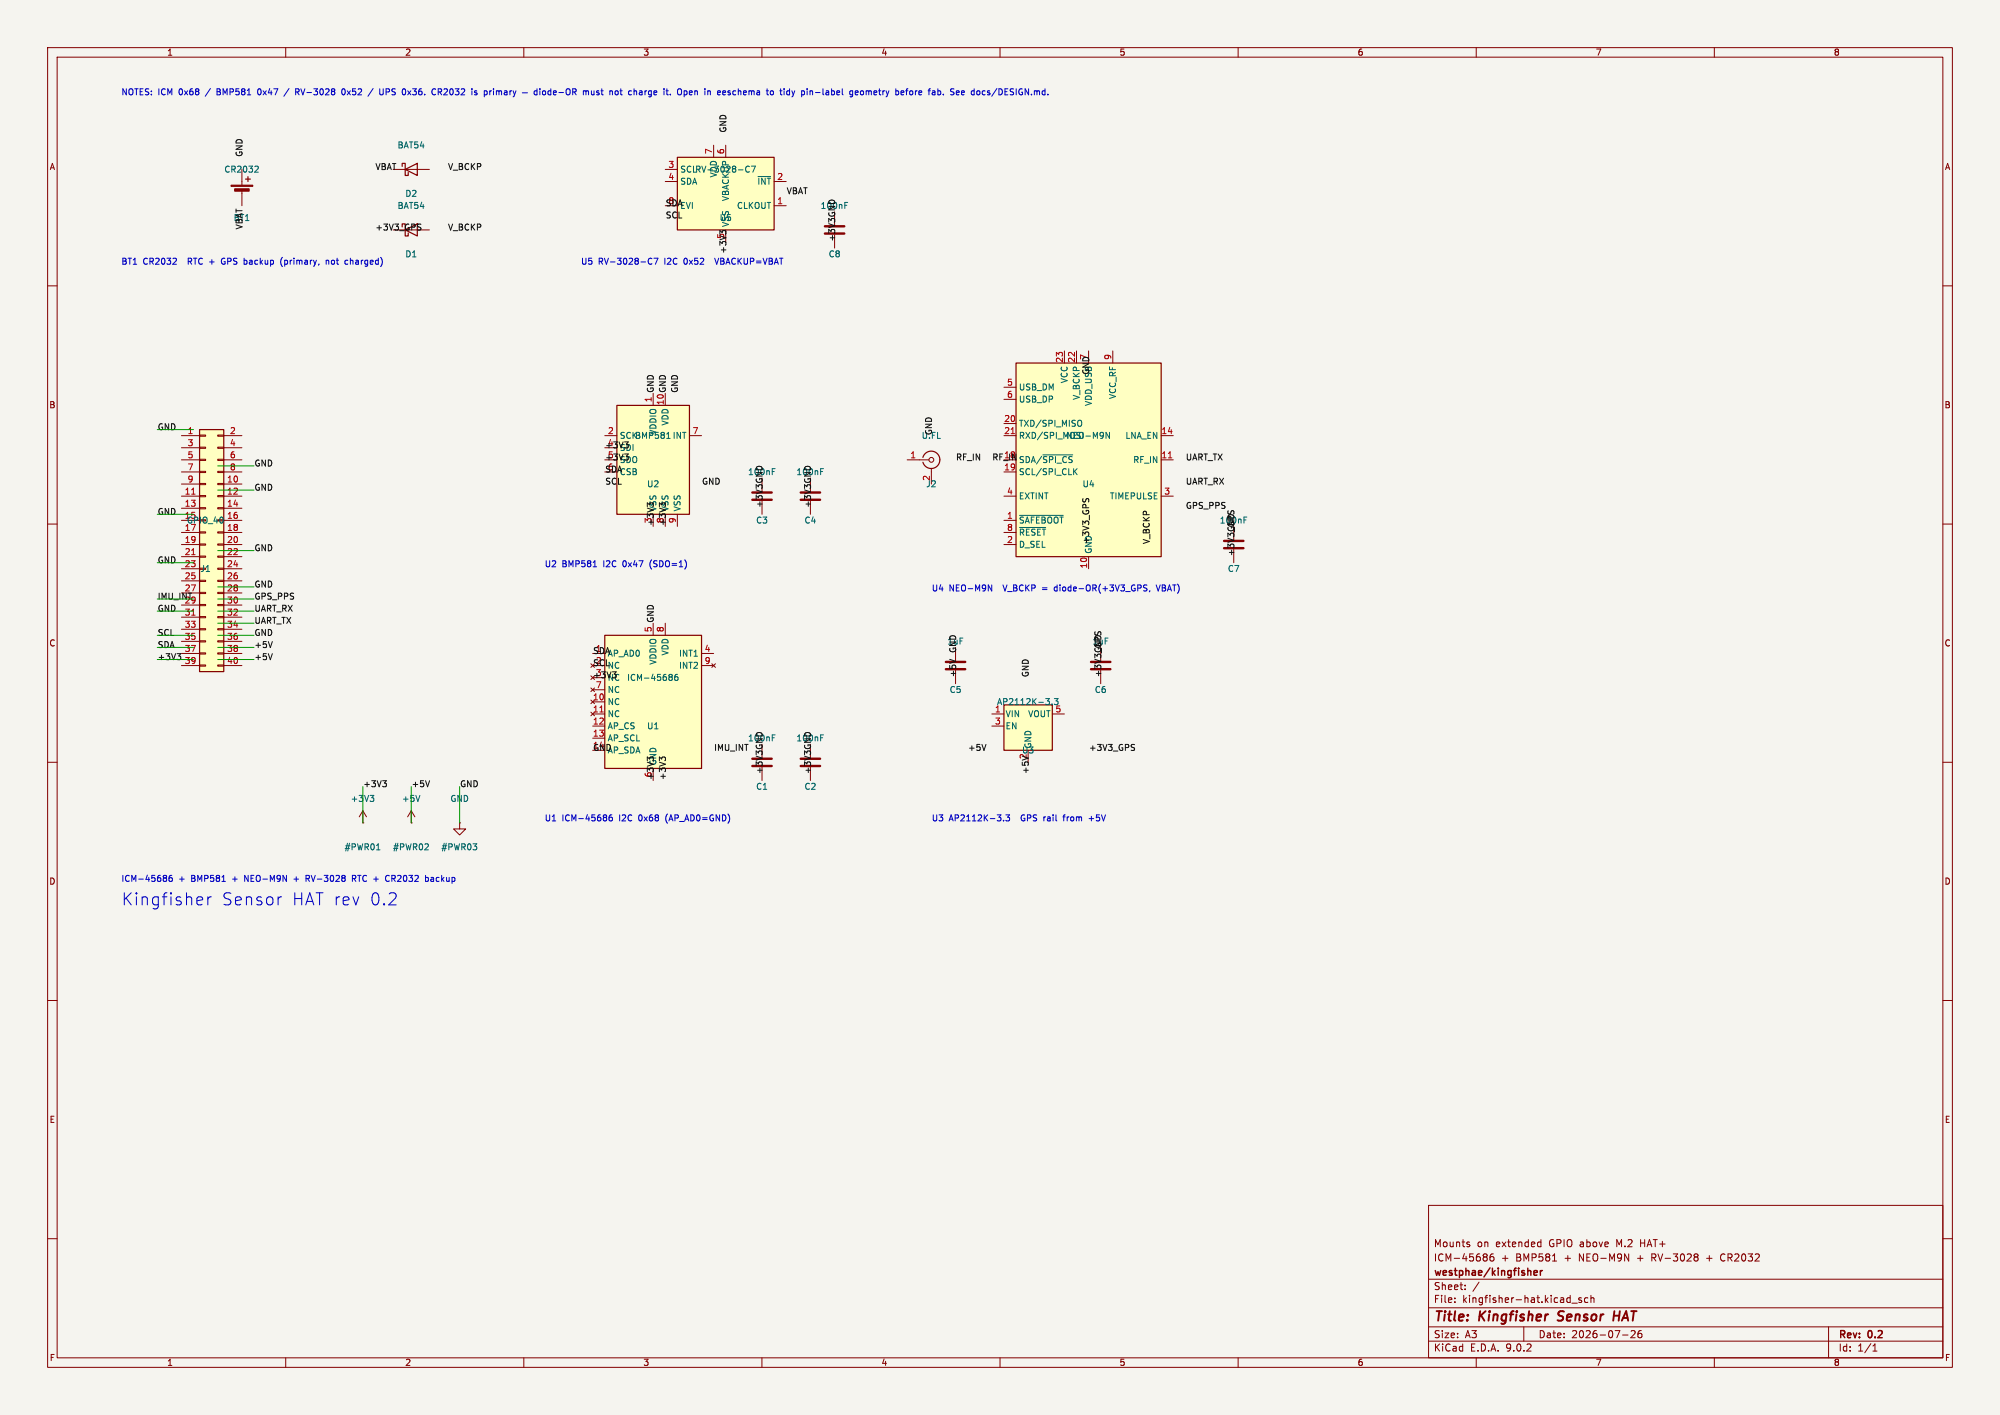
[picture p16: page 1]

Id: 1/1 Title: Kingfisher Sensor HAT

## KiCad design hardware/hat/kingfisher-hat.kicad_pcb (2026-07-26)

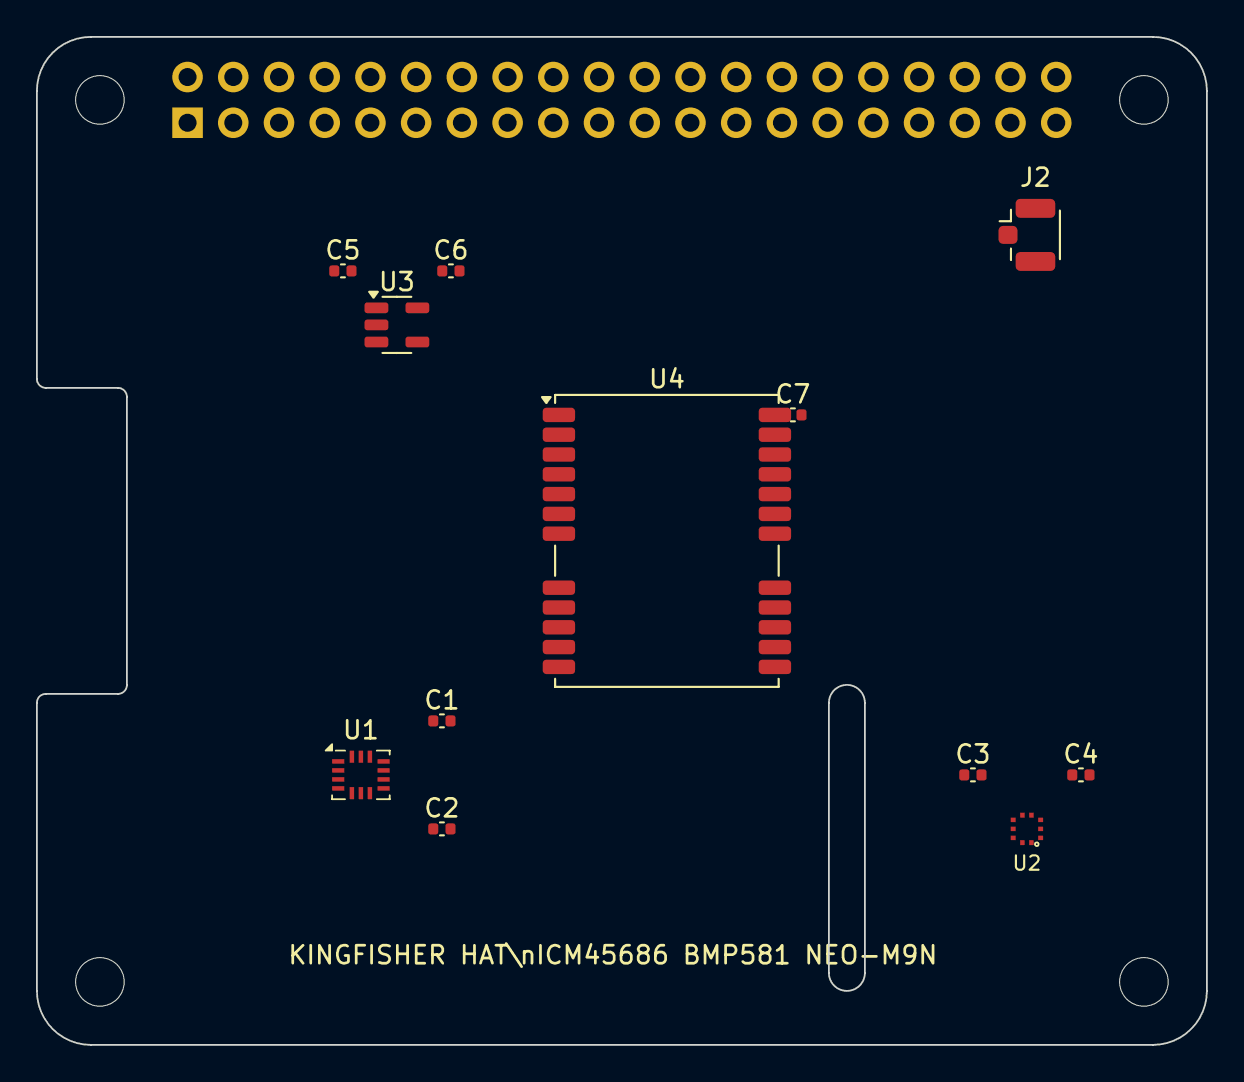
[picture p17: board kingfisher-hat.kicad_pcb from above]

Board: 4 copper layers, 65.0 x 56.0 mm, 17 parts (1 on the bottom side), 3 nets, no tracks yet.

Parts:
C1, C2, C3, C4, C7: 100nF; C_0402_1005Metric
C5, C6: 1uF; C_0402_1005Metric
J1: GPIO; PinSocket_2x20_P2.54mm_Vertical
J2: U.FL; U.FL_Hirose_U.FL-R-SMT-1_Vertical
MH1, MH2, MH3, MH4: MountingHole_2.7mm_M2.5
U1: ICM-45686; Bosch_LGA-14_3x2.5mm_P0.5mm
U2: BMP581
U3: AP2112K-3.3; SOT-23-5
U4: NEO-M9N; ublox_NEO

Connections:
+3V3: J1.1, J1.17
+5V: J1.2, J1.4
GND: J1.6, J1.9, J1.14, J1.20, J1.25, J1.30, J1.34, J1.39

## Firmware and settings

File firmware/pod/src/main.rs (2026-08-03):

//! Phase 4 wing-pod firmware: optional I²C sensors, Ping/Pong, gated Hello,
//! Cmd/Ack (SetRate), dynamic caps, and periodic Status.

#![no_std]
#![no_main]

mod battery_cfg;
mod bmp_cfg;
mod mmc_cfg;
mod burst;
mod cfg;
mod cmd;
mod hello;
mod link;
mod power;
mod radio;
mod rates;
mod sensors;

use embassy_executor::Spawner;
use embassy_futures::select::{select, Either};
use embassy_net::{
    udp::{PacketMetadata, UdpSocket},
    IpAddress, IpEndpoint, Runner, Stack, StackResources,
};
use embassy_time::{with_timeout, Duration, Instant, Ticker, Timer};
use esp_alloc as _;
use esp_backtrace as _;
use esp_hal::{
    clock::CpuClock,
    i2c::master::{Config as I2cConfig, I2c},
    interrupt::software::SoftwareInterruptControl,
    rng::Rng,
    rtc_cntl::{sleep::TimerWakeupSource, wakeup_cause, Rtc},
    system::SleepSource,
    time::Rate,
    timer::timg::TimerGroup,
};
use esp_println::println;
use esp_radio::wifi::{
    sta::StationConfig, AuthenticationMethod, Config, ControllerConfig, Interface, PowerSaveMode,
    WifiController,
};
use pod_wire::{Frame, Status};

/// Deep-sleep wake cadence in Protect: long enough to be negligible power,
/// short enough that plugging in a charger is noticed within minutes.
const PROTECT_WAKE_CHECK_S: u64 = 600;

/// Upper bound on any UDP send in uplink_task. A send that cannot complete
/// this fast is pathological — in particular, a send enqueued while the
/// radio is being torn down parks forever on a full socket buffer that
/// nothing will ever drain. That wedged uplink_task (and with it
/// power::tick, which drives every burst/protect transition) for 53 min on
/// 2026-07-15: stuck in BurstCollect, radio off, rings overwriting, until
/// charger current forced Active from the sensor task. No await in
/// uplink_task may block unbounded.
const SEND_TIMEOUT: Duration = Duration::from_millis(250);

esp_bootloader_esp_idf::esp_app_desc!();

macro_rules! mk_static {
    ($t:ty, $val:expr) => {{
        static STATIC_CELL: static_cell::StaticCell<$t> = static_cell::StaticCell::new();
        STATIC_CELL.uninit().write($val)
    }};
}

#[esp_rtos::main]
async fn main(spawner: Spawner) -> ! {
    esp_println::logger::init_logger_from_env();
    let config = esp_hal::Config::default().with_cpu_clock(CpuClock::max());
    let peripherals = esp_hal::init(config);

    esp_alloc::heap_allocator!(size: 72 * 1024);

    let i2c = I2c::new(
        peripherals.I2C0,
        I2cConfig::default().with_frequency(Rate::from_khz(100)),
    )
    .unwrap()
    .with_sda(peripherals.GPIO5)
    .with_scl(peripherals.GPIO6);
    esp_hal::delay::Delay::new().delay_millis(50);
    // Lifetime-launder the I²C bus to 'static for the StaticCell (peripherals
    // are effectively 'static singletons). Types are spelled out so a shape
    // change on either side fails the build; only the lifetimes are inferred.
    let i2c = mk_static!(sensors::bus::Bus, unsafe {
        core::mem::transmute::<esp_hal::i2c::master::I2c<'_, esp_hal::Blocking>, sensors::bus::Bus>(
            i2c,
        )
    });

    let timg0 = TimerGroup::new(peripherals.TIMG0);
    let sw_int = SoftwareInterruptControl::new(peripherals.SW_INTERRUPT);
    esp_rtos::start(timg0.timer0, sw_int.software_interrupt0);

    let mut rtc = Rtc::new(peripherals.LPWR);

    // Protect-mode wake check: after a deep-sleep timer wake, look at the
    // gauge BEFORE bringing up WiFi (the whole point is not to spend the
    // power). Resume boot only when charging or genuinely recovered; if the
    // gauge doesn't answer, fail open and boot normally. No .await happens
    // before this point, so the sensor task cannot race us for the bus.
    if matches!(wakeup_cause(), SleepSource::Timer) {
        match sensors::bq27441::quick_check(i2c) {
            Some((v, i)) if i < 0.05 && v < cfg::BURST_VOLTAGE_UNCALIBRATED => {
                println!(
                    "pod: protect wake check: {:.2} V {:.0} mA, still low; sleeping {} s",
                    v,
                    i * 1000.0,
                    PROTECT_WAKE_CHECK_S
                );
                let timer =
                    TimerWakeupSource::new(core::time::Duration::from_secs(PROTECT_WAKE_CHECK_S));
                rtc.sleep_deep(&[&timer]);
            }
            Some((v, i)) => {
                println!(
                    "pod: protect wake check: {:.2} V {:.0} mA; resuming normal boot",
                    v,
                    i * 1000.0
                );
            }
            None => println!("pod: protect wake check: gauge unreadable; booting normally"),
        }
    }

    spawner.spawn(sensor_bringup_task(i2c).unwrap());

    let station_cfg = if cfg::PASSWORD.is_empty() {
        StationConfig::default()
            .with_ssid(cfg::SSID)
            .with_auth_method(AuthenticationMethod::None)
    } else {
        StationConfig::default()
            .with_ssid(cfg::SSID)
            .with_password(cfg::PASSWORD.into())
    };
    let station = Config::Station(station_cfg);

    println!("pod: starting wifi (ssid={})", cfg::SSID);
    let (controller, interfaces) = esp_radio::wifi::new(
        peripherals.WIFI,
        ControllerConfig::default().with_initial_config(station),
    )
    .unwrap();
    let wifi_interface = interfaces.station;

    let net_config = embassy_net::Config::dhcpv4(Default::default());
    let rng = Rng::new();
    let seed = ((rng.random() as u64) << 32) | (rng.random() as u64);

    let (stack, runner) = embassy_net::new(
        wifi_interface,
        net_config,
        mk_static!(StackResources<3>, StackResources::<3>::new()),
        seed,
    );

    spawner.spawn(connection_task(controller).unwrap());
    spawner.spawn(net_task(runner).unwrap());

    println!("pod: waiting for ip");
    stack.wait_config_up().await;
    if let Some(ipcfg) = stack.config_v4() {
        println!("pod: got ip {}", ipcfg.address);
    }

    spawner.spawn(uplink_task(stack).unwrap());

    loop {
        Timer::after(Duration::from_secs(1)).await;
        if power::mode() == power::PowerMode::Protect {
            // connection_task saw radio_wanted() drop and is stopping the
            // radio; give it a moment for a clean deauth before the lights
            // go out. Deep sleep powers down everything except the RTC.
            Timer::after(Duration::from_secs(2)).await;
            println!(
                "pod: protect: deep sleep, wake check every {} s (reason={:?})",
                PROTECT_WAKE_CHECK_S,
                power::reason()
            );
            let timer =
                TimerWakeupSource::new(core::time::Duration::from_secs(PROTECT_WAKE_CHECK_S));
            rtc.sleep_deep(&[&timer]);
        }
    }
}

#[embassy_executor::task]
async fn sensor_bringup_task(bus: &'static mut sensors::bus::Bus) {
    crate::battery_cfg::init();
    let board = sensors::bringup_board(bus);
    sensors::run_sensor_poll(bus, board).await;
}

fn clamp_rssi_dbm(rssi: i32) -> i8 {
    rssi.clamp(-128, 127) as i8
}

#[embassy_executor::task]
async fn connection_task(mut controller: WifiController<'static>) {
    // Modem power-save is a driver-global setting; esp_wifi_set_ps persists
    // across stop/start cycles, so set it once on the first association.
    let mut power_save_set = false;
    loop {
        if !power::radio_wanted() {
            if controller.is_connected() {
                let _ = controller.disconnect_async().await;
            }
            radio::stop();
            link::clear_wifi_rssi();
            println!("pod: radio off ({:?})", power::mode());
            while !power::radio_wanted() {
                Timer::after(Duration::from_millis(250)).await;
            }
            radio::start();
            println!("pod: radio on ({:?})", power::mode());
            // Let the StationStart event land before connect.
            Timer::after(Duration::from_millis(100)).await;
        }
        match controller.connect_async().await {
            Ok(info) => {
                println!("pod: wifi connected: {:?}", info);
                if cfg::MODEM_POWER_SAVE && !power_save_set {
                    match controller.set_power_saving(PowerSaveMode::Minimum) {
                        Ok(()) => {
                            power_save_set = true;
                            println!("pod: modem power-save Minimum");
                        }
                        Err(e) => println!("pod: set_power_saving: {:?}", e),
                    }
                }
                if let Ok(rssi) = controller.rssi() {
                    link::set_wifi_rssi(clamp_rssi_dbm(rssi));
                }
                let mut poll_tick = Ticker::every(Duration::from_millis(250));
                let mut ticks: u32 = 0;
                loop {
                    match select(poll_tick.next(), controller.wait_for_disconnect_async()).await {
                        Either::First(()) => {
                            if !power::radio_wanted() {
                                break;
                            }
                            ticks = ticks.wrapping_add(1);
                            if ticks % 4 == 0 {
                                match controller.rssi() {
                                    Ok(rssi) => link::set_wifi_rssi(clamp_rssi_dbm(rssi)),
                                    Err(_) => link::clear_wifi_rssi(),
                                }
                            }
                        }
                        Either::Second(Ok(_)) | Either::Second(Err(_)) => {
                            link::clear_wifi_rssi();
                            println!("pod: wifi disconnected");
                            break;
                        }
                    }
                }
            }
            Err(e) => {
                link::clear_wifi_rssi();
                if power::radio_wanted() {
                    println!("pod: wifi connect error: {:?}", e);
                }
            }
        }
        if power::radio_wanted() {
            Timer::after(Duration::from_secs(5)).await;
        }
    }
}

#[embassy_executor::task]
async fn net_task(mut runner: Runner<'static, Interface<'static>>) {
    runner.run().await
}

#[embassy_executor::task]
async fn uplink_task(stack: Stack<'static>) {
    let mut rx_meta = [PacketMetadata::EMPTY; 4];
    let mut rx_buf = [0u8; 256];
    let mut tx_meta = [PacketMetadata::EMPTY; 4];
    let mut tx_buf = [0u8; 1024];
    let mut socket = UdpSocket::new(stack, &mut rx_meta, &mut rx_buf, &mut tx_meta, &mut tx_buf);
    if let Err(e) = socket.bind(0) {
        println!("pod: socket bind: {:?}", e);
        return;
    }

    let dest = IpEndpoint::new(
        IpAddress::v4(cfg::PI_IP[0], cfg::PI_IP[1], cfg::PI_IP[2], cfg::PI_IP[3]),
        cfg::PI_PORT,
    );

    let mut frame_buf = [0u8; 512];
    let mut udp_rx = [0u8; 512];
    let mut ticker = Ticker::every(Duration::from_millis(cfg::TICK_MS));
    let mut next_log = Instant::now() + Duration::from_secs(5);
    let mut next_status = Instant::now() + Duration::from_secs(5);
    let mut sent_since_log: u32 = 0;
    let mut seq: u32 = 0;
    let mut pi_peer: Option<IpEndpoint> = None;
    let mut last_flush_us: u64 = 0;

    loop {
        match select(ticker.next(), socket.recv_from(&mut udp_rx)).await {
            Either::First(()) => {
                let now = Instant::now();
                let uptime_us = now.as_micros();
                power::tick(uptime_us);
                let radio_up = power::radio_wanted() && stack.is_config_up();

                if radio_up && link::should_send_hello(uptime_us) {
                    let mask = sensors::attached_mask();
                    let hello = hello::build(mask);
                    match pod_wire::encode_to_slice(&hello, &mut frame_buf) {
                        Ok(bytes) => {
                            if matches!(
                                with_timeout(SEND_TIMEOUT, socket.send_to(bytes, dest)).await,
                                Ok(Ok(()))
                            ) {
                                link::mark_hello_sent(uptime_us);
                                println!("pod: sent Hello (caps={})", mask);
                            }
                        }
                        Err(_) => println!("pod: hello encode failed"),
                    }
                }

                // Burst-store backlog drains first (oldest data), whenever the
                // link is up: hard in a drain window, opportunistically after
                // a recovery back to Active left leftovers behind.
                let mut drain_clean = true;
                if radio_up && burst::depth() > 0 {
                    const MAX_DRAIN_BATCHES_PER_TICK: u32 = 32;
                    for _ in 0..MAX_DRAIN_BATCHES_PER_TICK {
                        seq = seq.wrapping_add(1);
                        let batch = burst::build_batch(uptime_us, seq);
                        if batch.samples.is_empty() {
                            break;
                        }
                        let frame = Frame::Sample(batch);
                        let mut sent = false;
                        if let Ok(bytes) = pod_wire::encode_to_slice(&frame, &mut frame_buf) {
                            let peer = pi_peer.unwrap_or(dest);
                            sent = matches!(
                                with_timeout(SEND_TIMEOUT, socket.send_to(bytes, peer)).await,
                                Ok(Ok(()))
                            );
                        }
                        if sent {
                            sent_since_log += 1;
                        } else {
                            drain_clean = false;
                            break;
                        }
                    }
                }

                let depth = sensors::pending_depth();
                let flush_due = last_flush_us == 0
                    || uptime_us.saturating_sub(last_flush_us) >= cfg::FLUSH_INTERVAL_US
                    || depth >= cfg::FLUSH_HIGH_WATERMARK
                    || power::drain_requested();
                if radio_up && flush_due && depth > 0 {
                    // Wire batches cap at MAX_READINGS; drain backlog with short bursts.
                    const MAX_BATCHES_PER_FLUSH: u32 = 12;
                    let mut flushed = false;
                    for _ in 0..MAX_BATCHES_PER_FLUSH {
                        seq = seq.wrapping_add(1);
                        let batch = sensors::with_samples_mut(|s| s.build_batch(uptime_us, seq));
                        if batch.samples.is_empty() {
                            break;
                        }
                        let frame = Frame::Sample(batch);
                        if let Ok(bytes) = pod_wire::encode_to_slice(&frame, &mut frame_buf) {
                            let peer = pi_peer.unwrap_or(dest);
                            if matches!(
                                with_timeout(SEND_TIMEOUT, socket.send_to(bytes, peer)).await,
                                Ok(Ok(()))
                            ) {
                                sent_since_log += 1;
                                flushed = true;
                            }
                        }
                        if sensors::pending_depth() == 0 {
                            break;
                        }
                    }
                    if flushed {
                        last_flush_us = uptime_us;
                    }
                }

                // A drain window ends when everything reached the wire; send
                // a fresh Status alongside so the Pi sees the mode + depth 0.
                if power::drain_requested()
                    && radio_up
                    && drain_clean
                    && sensors::buffer_depth() == 0
                {
                    next_status = now; // force immediate Status below
                    match power::mode() {
                        power::PowerMode::BurstUplink => {
                            println!("pod: burst uplink complete");
                            power::note_uplink_complete(uptime_us);
                        }
                        power::PowerMode::ProtectPending => {
                            println!("pod: protect flush complete");
                            power::note_protect_flushed(uptime_us);
                        }
                        _ => {}
                    }
                }

                if radio_up && now >= next_status {
                    next_status = now + Duration::from_secs(5);
                    let status = Frame::Status(Status {
                        pod_uptime_us: uptime_us,
                        battery_v: sensors::latest_battery_v(),
                        rssi_dbm: link::wifi_rssi_dbm(),
                        tx_seq: seq,
                        rx_seq_last: cmd::last_rx_cmd_seq(),
                        power_mode: power::mode() as u8,
                        sleep_reason: power::reason() as u8,
                        buffer_depth: sensors::buffer_depth(),
                        dropped_readings: sensors::dropped_readings()
                            .saturating_add(burst::overwritten()),
                    });
                    if let Ok(bytes) = pod_wire::encode_to_slice(&status, &mut frame_buf) {
                        let peer = pi_peer.unwrap_or(dest);
                        let _ = with_timeout(SEND_TIMEOUT, socket.send_to(bytes, peer)).await;
                    }
                }

                if now >= next_log {
                    if sent_since_log > 0 || power::radio_wanted() {
                        println!("pod: uplink ok, {} pkts in last 5s", sent_since_log);
                    }
                    sent_since_log = 0;
                    next_log = now + Duration::from_secs(5);
                }
            }
            Either::Second(Ok((n, meta))) => {
                if n == 0 {
                    continue;
                }
                let peer = meta.endpoint;
                pi_peer = Some(peer);
                let now_us = Instant::now().as_micros();
                let uptime_us = now_us;
                let replies = cmd::handle_datagram(&udp_rx[..n], now_us, uptime_us);
                // Reply only while the radio is meant to be up: a datagram
                // that raced the burst radio-stop (or sat queued in the
                // socket across a radio-off window) must still be applied,
                // but answering it can wait for the next uplink — this send
                // is what wedged uplink_task on 2026-07-15.
                if power::radio_wanted() && stack.is_config_up() {
                    for reply in replies {
                        if let Frame::Ack(a) = &reply {
                            println!("pod: ack for_seq={} ok={}", a.for_seq, a.ok);
                        }
                        if let Ok(bytes) = pod_wire::encode_to_slice(&reply, &mut frame_buf) {
                            let _ =
                                with_timeout(SEND_TIMEOUT, socket.send_to(bytes, peer)).await;
                        }
                    }
                }
            }
            Either::Second(Err(e)) => {
                println!("pod: udp recv: {:?}", e);
            }
        }
    }
}

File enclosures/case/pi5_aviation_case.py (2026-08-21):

#!/usr/bin/env python3
# =============================================================================
#  Raspberry Pi 5 aviation enclosure  (Stratux-style: Pi + GPS + IMU)
#  Parametric model -> STEP (editable in Fusion) + STL (print-ready)
#  Printer: AnkerMake M5C / PETG.  Fasteners: M2.5 heat-set inserts + screws
#  (bay/lid); the Pi stack mounts on its own metal standoffs (see below).
#
#  v3 changes from v2 (measured hardware: ../x1200_m2hat_stack.md):
#   - Geekworm X1200 UPS added UNDER the Pi (18650s facing down), official
#     M.2 HAT+ ABOVE it (16 mm standoffs, over the active cooler), IDC ribbon
#     connector on extended GPIO pins above the HAT (RIBBON_ON_TOP)
#   - explicit Z-stack: every deck height derives from the stack parameters;
#     wall cutouts (USB-C, I/O window) follow the Pi deck automatically
#   - stack mounts via 4x M2.5 M-F standoffs threaded into the X1200's
#     threaded bosses from below; case screws come UP through the floor into
#     the standoffs' female ends (counterbored flush -> bottom stays flat for
#     Dual-Lock). No heat-set inserts for the stack; bay/lid keep theirs.
#   - CLR_L 1.0 -> 6.0: PCIe FPC ribbon bulges ~5 mm past the HAT's left edge
#     (also clears the Pi power button and the X1200 button overhang)
#   - microSD L-access removed (NVMe boot; SD is vestigial)
#   - new front-wall cutout for the X1200 USB-C charge input, with an interior
#     pilaster so the plug seats ~flush; new left-wall X1200 power-button
#     finger recess and LED openings; left exhaust slots moved up to cooler
#     level in two groups flanking the FPC keep-out
#   - the X1200's two BACK-edge LEDs face the GPS bay interior: no wall to
#     pipe them through; the left bank carries the same status -> skipped
#
#  v2 changes from first print feedback:
#   - tighter clearances below & around (cooling proven to be fine)
#   - USB-A/Ethernet sit ~flush: I/O wall pulled in, window widened
#   - velcro pad removed (flat solid bottom for Dual-Lock)
#   - lid lip split into segments with corner breaks (cleared the screw posts)
#   - lid exported upside-down (prints with no lip support)
# =============================================================================
import cadquery as cq

# ----------------------------------------------------------------------------- PARAMETERS (mm)
WALL        = 3.0
LID_T       = 4.0       # 2.30 mm socket-cap head fully recesses with solid plastic beneath
LID_LIP_H   = 3.0       # how far the lid lip drops into the case
LID_LIP_GAP = 0.4       # lip-to-wall clearance (tune per printer)
LIP_T       = 1.6       # lip rib thickness
LIP_CORNER_GAP = 7.0    # lip stops this far from each corner (clears the posts)
SCREW_HEAD_H = 2.30     # lid bolts: M2.5 socket cap head thickness
SCREW_HEAD_D = 4.5      # M2.5 socket cap head OD (counterbore is cut a touch wider)

# clearances around the Pi/X1200/HAT footprint (they share the 85x56 outline)
CLR_L       = 6.0       # left (-X): PCIe FPC ribbon bulges FPC_BULGE past the HAT
                        # edge; also covers the Pi power button (~3 mm) and the
                        # X1200 button (2.7 mm, gets a wall recess below)
CLR_F       = 4.3       # front (-Y, USB-C edge) gap. v3: set by DROP-IN clearance —
                        # the assembled stack lowers past the floating front posts,
                        # so the board edge must clear the post OD: POST_OFF +
                        # BOSS_D/2 + 0.3 margin (the old Ethernet limit was 3.5)
IO_CLR      = 0.0       # right (+X): board edge at the inner wall plane, connectors
                        # ride in the open I/O window and end flush with the wall face
BAY_GAP     = 4.0       # gap between the stack and the GPS/IMU bay
BACK_CLR    = 6.0       # behind GPS, for the two rear posts

# --- the Pi stack (Z), floor -> lid.  All decks DERIVE from these. ----------
# Mounting (see ../x1200_m2hat_stack.md): the four corner holes serve the
# WHOLE tower (case standoff / X1200 post / Pi / HAT spacer / HAT), so each
# corner is one M2.5x30 bolt from the HAT top: HAT 1.6 + spacer 15.8 + Pi 1.6
# + X1200 barrel 6.1 = 25.1 to exit the barrel, ~4.9 into a 20 mm F-F case
# standoff below (through-threaded or >=6 mm/end). The barrel threads are
# captured mid-column, not load-bearing. M2.5x8 case screws enter the
# standoff bottoms through the counterbored floor (tips clear by ~9.4).
# (M-F standoffs and shorter bolts DON'T work: the ~6 mm barrel can't serve
# two fasteners, and 20/25 mm bolts leave 1/0 mm of usable engagement.)
PAD_H, PAD_D    = 2.0, 11.0  # raised floor pads the standoffs sit on
UPS_STANDOFF_H  = 20.0  # M-F standoff below the X1200 (18.6 works; 20 is the
                        # common size and floats the cells 1.5 mm higher)
UPS_UNDERSIDE   = 18.5  # X1200 PCB bottom -> 18650 holder/cell bottom (cells DOWN)
UPS_PCB_T       = 1.6
POGO_SPACER_H   = 4.5   # kit spacer X1200->Pi: sets pogo-pin engagement
PI_PCB_T        = 1.6
COOLER_L, COOLER_W, COOLER_H = 63.5, 42.5, 14.0
HAT_STANDOFF_H  = 16.0  # official M.2 HAT+ standoffs (clears the active cooler)
HAT_PCB_T       = 1.6
GPIO_EXT_H      = 9.0   # extended GPIO pins above the HAT
IDC_STRIP_H     = 4.0   # pin-retention strip the ribbon connector presses onto
IDC_H           = 15.4  # IDC ribbon connector height (incl. strain relief)
RIBBON_ON_TOP   = True  # option A: IDC lives on the pins above the HAT.
                        # False = pins only (discrete harness), case ~10 shorter
STACK_HEADROOM  = 2.5   # stack top -> lid underside (also absorbs the ~1 mm
                        # bench-vs-sum measurement disagreement)

# base screws: M2.5x8 pan head, up through the floor into the standoffs
BASE_HOLE_D   = 2.8
BASE_CB_D     = 5.6     # counterbore for the pan head (flush bottom, Dual-Lock)
BASE_CB_DEPTH = 2.7

# --- M2.5 brass heat-set inserts (bay pedestals + lid posts only) -----------
INSERT_OD   = 3.47      # insert outside diameter (knurled body), mm
INSERT_LEN  = 3.98      # insert length = how deep it sits when pressed flush, mm
MELT_ALLOWANCE   = 0.30 # pilot hole is OD minus this (PETG; confirm on a coupon)
HOLE_DEPTH_EXTRA = 0.50 # drill past the insert so it seats flush w/ relief room
INS_HOLE_D  = INSERT_OD  - MELT_ALLOWANCE
INS_DEPTH   = INSERT_LEN + HOLE_DEPTH_EXTRA
SCREW_RELIEF_D     = 2.9   # narrower bore continuing below the insert
SCREW_RELIEF_EXTRA = 4.0   # how far the relief reaches past the insert
SCREW_RELIEF_FLOOR = 1.0   # min plastic left at the far end

BOSS_D      = 6.0       # boss OD around an insert; lean but wall-fused (see v2)
POST_OFF    = 1.0       # lid-post centre, in from the corner
POST_LEN    = 13.0      # lid posts hang from the top this far; 45 deg taper beneath

# Raspberry Pi 5 (the X1200 and the mount-hole pattern share this outline)
PI_L, PI_W  = 85.0, 56.0
PI_HOLE_INSET, PI_HOLE_DX, PI_HOLE_DY = 3.5, 58.0, 49.0
USBC_X      = 11.2      # Pi USB-C centre from the left board edge
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

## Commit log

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2026-05-20 feat(gps): add gpsd TCP client
    Dials gpsd on localhost:2947, watches TPV / SKY reports via
    stratoberry/go-gpsd, and republishes each fix as a Sample on the
    "gps" virtual device. Reconnects automatically every 2 s on
    disconnect. Exposes the latest Fix to other packages (declination,
    AHRS) under a mutex.
2026-05-20 feat(derive): add pressure altitude, declination, and AHRS derivations
    Three goroutines publish to virtual devices:
    - press_alt: bmp280.CalcAltitude applied to the latest pressure
    sample, every 200 ms.
    - geo: wmm declination, inclination, and field magnitudes once per
    second from the latest GPS fix.
    - ahrs: goflying SimpleAHRS fed Measurements built from the latest
    IMU + GPS sample at a configurable rate (default 20 Hz).
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2026-05-20 feat(pod_wire): add Rust wire-format crate with framing
    Shared no_std crate defining the pod <-> Pi protocol: Frame enum
    covering Hello, Status, SampleBatch, Cmd, Ack, Ping, and Pong, plus a
    (u16 length, postcard body, u32 crc32) envelope so corrupted datagrams
    fail closed. Includes round-trip unit tests for every variant, a CRC
    rejection test, and a `pod_wire_dump` example that emits hex-encoded
    reference frames consumed by the Go side's cross-language test.
2026-05-20 feat(pod/wire): add Go decoder for pod wire format
    Mirrors the Rust pod_wire crate: Frame, Reading, and Cmd as Go
    interfaces with concrete struct variants; a postcard codec covering
    varint, signed varint, f32 LE, and the enum/struct dispatch needed for
    each frame; and the (length, body, crc32) envelope. Tests decode the
    Rust-generated fixtures, exercise an Encode/Decode round-trip for
    every variant, and verify CRC rejection.
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2026-05-20 feat(cmd): wire pod ingest into kingfisher main
    Bind a UDP listener for pod telemetry when cfg.PodUDPAddr is set, build
    the pod.Client alongside gpsClient, and run its loop with the same
    stop channel as the rest of the goroutines. A failed bind logs and
    continues so the recorder still starts on machines that don't expose
    the pod port.
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2026-05-20 docs: add top-level README
    Project description, hardware roster for the main cabin unit and the
    wing pod, and pointers to firmware/pod/README.md for the pod-side
    setup. Replaces the local notes file.
2026-05-20 docs: add CLAUDE.md agent guide
    Captures the non-obvious bits future Claude instances need: the local
    go.mod replace directives, live.Hub as the central pub/sub bus, the
    push-vs-pull split between IIO sensors and out-of-process sources,
    the sensors.Reader-as-facade pattern used by internal/pod, the
    cross-language fixture regen workflow for pod_wire, the deferred
    Phase 5 AHRS surgery, and the global git-push/release etiquette rule.
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2026-05-21 feat(cmd/podprobe): add UDP bench listener
    Throwaway Phase 1 listener used to verify the wing-pod's wire output
    before kingfisher itself is brought up against the pod (which happens
    in Phase 2). Binds the same port as kingfisher's pod ingest, so the
    two cannot run together.
    Decodes each datagram via internal/pod/wire.Decode, prints a
    per-packet one-liner (frame summary, seq, gap), and emits a stats
    line every 5 s with received / lost / decode_err counts and inter-
    arrival p50/p99 over a sliding 500-packet ring buffer. SIGINT flushes
    one final stats line and exits.
    Builds clean and the wire path it depends on is covered by existing
    unit + integration tests in internal/pod. End-to-end verifi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
2026-05-21 fix(firmware/pod): use open auth when WiFi password is empty
    StationConfig defaults to WPA2; the Pi bench AP is open, which caused
    NoAccessPointFoundInAuthmodeThreshold until auth_method is set to None.
    [main.rs]
2026-05-21 feat(pod): Phase 3a BMP581 on I²C; Pro Micro Qwiic pins and Pi ingest fixes
    Replace fake sensor data with a BMP581 driver and 10 Hz uplink. Route I²C
    to GPIO5/6 on the SparkFun Pro Micro ESP32-C3 so a Qwiic cable matches
    hardware; retry bring-up and log scan/probe diagnostics.
    Kingfisher binds pod UDP on all interfaces, logs wire decode failures,
    and publishes to the hub on Hello so the pod tab appears before samples.
    [bmp581.rs, bus.rs, main.rs]
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2026-05-21 feat(pod_wire): wrap Cmd in envelope with seq; Ack echoes for_seq
    Pi assigns sequence numbers on outbound commands; the pod echoes them in
    Ack.for_seq so the ingest side can match replies and time out stale SetRate.
    Regenerate cross-language fixtures for the updated wire types.
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2026-05-21 feat(pod): Pi control plane with Cmd/Ack and SetRate
    Send SetRate commands with sequence tracking, revert on Ack timeout, and
    reapply saved pod.attrs on startup and Hello. Register per-sensor rate
    attrs (mag/static/airspeed) for the settings UI.
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2026-05-21 feat(firmware/pod): Phase 4 UDP control, gated Hello, per-sensor rates
    Receive Ping/Cmd on UDP, reply with Pong/Ack, apply SetRate decimation on
    the 100 ms tick, and advertise dynamic Hello caps. Gate periodic Hello to
    avoid spam when the Pi link is up (FW 0x0004_0001).
    [main.rs]
2026-05-22 fix(pod): show settings before Hello and parse legacy config keys
    Infer caps from SampleBatch when boot Hello was missed, load pod.attrs
    including in_mag_x_sampling_frequency, normalize keys on migrate, and
    eager-load attrs for the pod tab in the web UI.
2026-05-22 feat(pod): reject unsustainable combined sampling rates on Pi
    Validate static+mag+airspeed Hz against the wing I²C work budget before
    sending SetRate so pairs like 50+50 static+mag fail fast in the UI.
2026-05-22 feat(firmware/pod): bus budget, rate backoff, and I2C recovery
    Cap per-tick I²C work, reject unsustainable SetRate, poll mag before BMP,
    back off on failures or tick overrun, and re-init sensors (FW 0x0004_0002).
    Request Hello on Pi Ping when kingfisher starts after the pod.
2026-05-22 fix(sensors): use Hz presets for step-1 sampling rate dropdowns
    Avoid listing every integer 1..N when pod Hello caps shrink (e.g. static
    max 25 Hz after mag is set to 25).
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2026-05-26 feat(pod/wire): proto v2 with per-sensor device names
    Bump PROTO_VERSION to 2 and add a fixed 12-byte SensorDeviceName so the
    pod can advertise per-sensor chip names (bmp581, mmc5983, ms4525) in
    Hello. Mirror the change in the Go wire codec/types and regenerate the
    cross-language fixtures.
2026-05-26 feat(firmware/pod): BMP581 FIFO, MMC5983 ODR control, device-name caps
    Advertise per-sensor chip names in Hello via SensorDeviceName. BMP581
    runs NORMAL+FIFO with drained frames decoded per-sample; MMC5983 gains
    continuous-measurement ODR selection and ready-gated reads. Rework the
    sensor scheduler bus-budget accounting and refresh the firmware README.
    [bmp581.rs, main.rs, mmc5983.rs]
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2026-05-26 feat(derive): source pressure altitude from the pod static baro device
    Resolve the wing baro by its per-sensor device name (SensorStatic)
    instead of the legacy aggregate pod device, so press_alt picks up the
    BMP581 readings under the new telemetry device split.
2026-05-26 feat(gps): publish accuracy estimates and add 5/10 Hz rate decimation
    Publish gpsd's per-axis accuracy fields (v_acc/gs_acc/vs_acc/track_acc)
    alongside position. Add software decimation of the fixed-rate receiver
    stream to the configured GPS.RateHz so the cockpit UI can select 5 or
    10 Hz without reconfiguring a read-only gpsd.
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2026-05-26 feat(press-alt): add kollsman setting and indicated altitude
    Persist an editable altimeter setting, log it with the derived device metadata, and publish indicated altitude alongside pressure altitude so the UI and flight DB reflect the configured baro correction.
2026-05-26 feat(web): stabilize dual-unit rows and expose derived fields
    Stop cockpit value rows from shifting as unit widths change and surface the new press-alt and geo fields with clearer derived-device labels.
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2026-05-27 docs: clarify wall-clock TsNs contract across streams
    GPS fix epoch stays in Fix.Time while samples use disciplined host time;
    document the same base for IIO, pod, store, and hub samples.
2026-05-27 feat(gps): probe startup clock and track fix-epoch skew
    Assess wall clock against gpsd before opening the flight DB, persist
    startup metadata, and expose ClockStatus with median lag baseline.
2026-05-27 fix(sensors): use device-native IIO buffer without hrtimer sysfs
    Skip EnsureHRTimer when trigger/current_trigger is absent (e.g. split
    icm45686 devices) and fall back to polled reads only after native stalls.
2026-05-27 feat(web): clock badge, GPS fix time, and offline recording state
    Show Pi-vs-GPS skew in the header, list GNSS fix time on the GPS tab,
    and switch REC to OFFLINE when the WebSocket or /api/status is unreachable.
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2026-05-30 docs: document compass device and magkal dependency in CLAUDE.md
    Note compass derive behavior, WMM alignment, cockpit tab, and the local
    magkal replace directive.
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2026-05-31 fix(pod_wire): satisfy clippy on Frame and SensorDeviceName
    Allow the large Sample variant in no_std (boxing would need alloc) and
    implement FromStr with a new() helper instead of an inherent from_str.
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2026-06-01 fix(pod/wire): decode legacy Status frames without extended tail
    Older pod firmware sends shorter Status bodies; optional tail fields keep
    the Pi decoder compatible while extended Status is rolled out.
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2026-06-01 fix(firmware/pod): debounce BQ27441 design capacity programming
    Skip duplicate SetAttr, back off 60 s after config-update failure, and
    mark success so the poll loop does not hammer the gauge on every Hello.
    [bq27441.rs]
2026-06-01 fix(firmware/pod): debounce I2C recovery and backoff at safe minimum
    Only run bus recovery when backoff actually lowers a rate, debounce full
    recoveries to 30 s, and log read-fail streaks without wiping mag/static.
2026-06-01 fix(firmware/pod): wait for MS4525 conversion before reading
    Wait 2 ms after the measure command and retry fetch-only on busy status so
    airspeed polls are not misclassified as I2C failures.
    [ms4525.rs]
2026-06-01 fix(pod): dedupe design capacity SetAttr after Hello
    Track the last mAh sent on the wire and skip redundant pushes so periodic
    Hello does not reset BQ27441 programming backoff on the pod.
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2026-06-01 fix(firmware/pod): inhibit sleep while charging and allow wake
    Treat positive gauge current as charging to block sleep entry, clear a latched
    sleep request, and use gauge_trusted SOC only after design capacity is programmed.
2026-06-01 fix(firmware/pod): reprogram BQ27441 when full capacity mismatches design
    Queue design capacity on init when full is not near config, reconcile PROGRAM_DONE
    with the full register, and verify the register after config update before success.
    [bq27441.rs]
2026-06-01 fix(firmware/pod): run battery policy and design program while quiesced
    Sample the gauge before sleep gating so charging can wake the pod, and run design
    capacity programming even when other sensors are quiesced.
2026-06-01 fix(pod): treat mismatched gauge full capacity as unlearned
    Hide stale full-capacity readings in the UI until they match configured design,
    and re-send SetAttr when the pod reports a wrong full register.
2026-06-02 feat(web): mobile-first overview UI with hash routing
    Replace horizontal device tabs with a scrollable overview (hub/pod/calc
    sections), per-sensor detail pages, compact header, and bottom nav.
    Multi-row layouts for IMU, GPS, and derived devices; overview-only
    formatting and display names (altitude, geomagnetic).
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2026-06-02 fix(firmware/pod): keep battery poll active and report 0 V when unknown
    Poll the fuel gauge even when sleep is requested so status voltage stays
    current; return 0.0 instead of a fake uncalibrated placeholder when no
    sample exists yet.
    [main.rs]
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2026-06-03 fix(firmware/pod): program BQ27441 design capacity reliably
    Read the State block before checksum, write MSB-first capacity and design energy,
    verify against DesignCapacity (0x3C) not learned FCC, and stop clearing PROGRAM_DONE
    when FCC still differs from design.
    [bq27441.rs]
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2026-06-03 feat(pod): sync Settings design capacity with gauge 0x3C
    Telemetry carries chip design capacity; the UI shows the user value while a
    program is pending, reverts to the chip on failure or timeout, and persists
    config only when the gauge matches.
2026-06-03 fix(pod): correct battery time_remaining_s and stop Pi recompute
    Firmware now uses mAh/mA×3600 for seconds; the old mAh/A×3600 factor was
    1000× too large (~5811 h vs ~5.8 h). Pi passes TimeRemainS through unchanged
    so bad pod values are visible instead of masked.
    [bq27441.rs]
2026-06-03 fix(sensors): improve icm45686 hwfifo buffer capture and stall recovery
    Use hwfifo-int1 path without data_available polling, sync sampling_frequency
    to sample_hz, prefer chip IIO triggers when present, and restart buffered
    capture on stall before falling back to polled reads.
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2026-06-03 fix(sensors): snap icm45686 sampling_frequency to driver ODR table
    Write the nearest sampling_frequency_available token so sample_hz values
    like 10 Hz do not fail with EINVAL; log when the snapped rate differs.
2026-06-03 fix(pod): atomicise offset init and clamp reconstructed TsNs to recv window
    Two related hardenings of onBatch:
    - Move the offsetInited/offsetNs init+EMA update under c.mu so a second
    goroutine cannot read inited=true with offsetNs still zero. Other
    readers of offsetNs (status surface) keep loading atomically.
    - Clamp the reconstructed readingNs to [recvNs-10s, recvNs+1s], falling
    back to recvNs on out-of-window values, and surface a tsClamped
    counter in LinkStats. Prevents EMA cold-start, bogus pod uptime, or
    anomalous AgeMicros from emitting negative TsNs (which present as
    year-2262 rows in offline analysis).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
2026-06-18 refactor(firmware): resolve cargo clippy warnings
    All behavior-preserving:
    - main.rs: drop redundant macro parens; match-on-single-pattern -> if let;
    annotate the lifetime-laundering i2c transmute with a scoped allow + note.
    - cmd.rs: merge two identical if-arms into one || condition.
    - rates.rs: manual div_ceil -> .div_ceil().
    - bmp581.rs: keep the documented `<< 0` register-bit offset under a scoped
    allow(identity_op) rather than dropping the field-layout symmetry.
    - sensors/mod.rs: drop redundant explicit deref and a no-op u64->u64 cast.
    cargo clippy is now clean for both pod_wire and the firmware.
    [bmp581.rs, main.rs]
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2026-06-18 refactor(firmware): spell out the i2c transmute types, drop dead register op
    - main.rs: annotate the lifetime-laundering transmute with both concrete
    types instead of #[allow(missing_transmute_annotations)] — a shape change
    on either side now fails the build rather than silently reinterpreting.
    - bmp581.rs: drop `OSR_TEMP_NONE << 0` (it is 0 << 0, contributing nothing)
    and the identity_op allow; keep the field layout in a comment.
    Both behavior-preserving; cargo clippy is clean for the firmware again.
    [bmp581.rs, main.rs]
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2026-06-19 fix(firmware/pod): make gauge NVM the source of truth for design capacity
    The pod reprogrammed the bq27441 design capacity to a build-time baked
    default on every power-on (ITPOR) and gated runtime SetAttr writes behind a
    sticky PROGRAM_DONE flag that could latch and block further writes, so a UI
    change never persisted.
    Make the gauge's own non-volatile DesignCapacity (0x3C) the source of truth:
    init() reads and trusts it, seeding the build-time default only when the gauge
    is blank; runtime writes are driven by comparing a pending target against the
    live 0x3C readback, so a changed value always reprograms and a transient
    self-corrects. Bump FW_VERSION to 0x00040005 (behavior change; wire pro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
    [bq27441.rs]
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2026-07-14 feat(pod-power): three-stage battery protocol (burst collect+drain, deep-sleep protect)
    Replace the Phase-4 quiesce-sleep (which discarded sensor data while
    leaving radio+CPU powered) with a protocol that never drops data:
    - Active: live streaming as before. Modem power-save exists but is
    config-gated OFF: bench test showed the Pi's brcmfmac AP never
    delivers buffered unicast to a dozing STA (pod misses all Cmd/Ping).
    - Burst (SOC <= burst_soc_pct on battery, debounced): radio off via raw
    esp_wifi_stop (esp-radio 0.18 has no public stop/start; its state
    machine is WiFi-event-driven so the raw calls stay coherent). Sensors
    keep sampling into compact per-sensor RAM rings (~149 KB, 5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
    [bq27441.rs, main.rs]
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2026-07-15 fix(firmware/pod): bound all uplink sends — radio-stop race wedged the power state machine
    A UDP send enqueued as the burst radio-stop tears the link down parks
    forever on a full socket TX buffer that nothing will ever drain. On
    2026-07-15 the Pi's SetRate cmds (sent on every Hello) arrived exactly at
    the BurstUplink->BurstCollect flip; uplink_task blocked in the cmd-reply
    send_to and, since power::tick lives in that task, the whole power state
    machine froze in BurstCollect for 53 min: radio off, rings overwriting
    (~400k readings lost), no protect transition. Charger current recovered it
    only because charge detection runs in the sensor task.
    Evidence: uptime/seq counters continuous across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
    [main.rs]
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2026-08-03 feat(firmware/pod): apply BMP581 OSR/IIR with 25 Hz cruise default
    Program DSP_CONFIG for post-IIR FIFO samples, reject ODR above the OSR
    max, and boot static at 25 Hz for the high-resolution noise profile.
    [bmp581.rs, main.rs]
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2026-08-07 fix(enclosures): shorten pod, ellipse shell, bake 45° print pose
    Pack length to ~205 mm so the diagonal print AABB stays under a 10 mm
    bed margin; rebuild the cross-section as an ellipse with flat-top chord;
    export halves flange-down and pre-rotated 45° (previous flip was inverted).
    [pitot_plug.step, pod_assembly.step, pod_left.step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]
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2026-08-07 fix(enclosures): export pitot plug STL flange-down for printing
    [pitot_plug.step, pitot_plug.stl]
2026-08-07 chore(enclosures): refresh pod STEP exports after plug print flip
    [pod_assembly.step, pod_left.step, pod_right.step]
2026-08-07 fix(enclosures): export single-solid STLs for AnkerMake
    Multi-body compounds from floating cradle ribs caused AnkerMake Studio
    to refuse the meshes. Bond bulkheads into the shell and collapse each
    export to one solid before tessellation.
    [case_base.stl, case_lid.stl, pitot_plug.step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]
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2026-08-07 fix(enclosures): fair nose/tail, flat sides, internal-only bulkheads
    Replace the oversized elliptical extrusion and blunt ends with a flat-top /
    flat-side / curved-bottom midsection plus lofted nose and tail. Keep pitot
    bulkheads inside the skin (no exterior ribs). Document that board mounts
    live only on the right half.
    [pitot_plug.step, pod_assembly.step, pod_left.step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]
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2026-08-07 fix(enclosures): skinny rounded pod with ogive nose/tail
    Cut overall width ~84→52 mm via an asymmetric elliptical section (thin
    left cover, right electronics bay). Replace pyramidal end lofts with
    multi-station rounded ogives; drop the hard chines that read as nose/tail
    tabs. Refresh shape preview PNG.
    [pitot_plug.step, pod_assembly.step, pod_left.step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]
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2026-08-07 fix(enclosures): tip-near-seam ogive and clip blanks to outer skin
    Walk nose/tail tips toward the seam so the left cover gets a real fairing,
    and intersect flange/bulkheads/deck/posts with the outer envelope so
    rectangular stock can no longer poke through the curved shell.
    [pitot_plug.step, pitot_plug.stl, pod_assembly.step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]
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2026-08-09 fix(enclosures): flat chords, mid≡ogive ellipse, clip static bay
    Keep midsection on the ogive end ellipse (no freestream step), add flat
    top/bottom with bottom edge radius, and intersect static-bay walls so they
    cannot poke the curved skin. Regenerate watertight STLs/STEP and flat-chord
    previews.
    [pitot_plug.step, pitot_plug.stl, pod_assembly.step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]
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2026-08-09 feat(enclosures): untested SUN-B cradle (drop tubes-in-tube plug)
    Replace the metal outer-tube + printed pitot plug with a stepped L/R clamp
    for the calipered ESA SUN-B adapter (tip protrude, barb bay, aft recess
    boss). Regenerated halves; validate_pod updated. Dry-fit not yet done.
    [pitot_plug.step, pitot_plug.stl, pod_assembly.step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]
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2026-08-10 feat(enclosures): SUN shoulder seat, nose fairing, convex stern
    Tip-only nose bulkhead seats Ø10.65 at x=2.5; outer mouth fairs into the
    SUN tip with a sharp lip. Blunt ellipsoidal stern replaces the pin tip.
    Regen writes an ortho right-interior QC PNG each revision.
    [pod_assembly.step, pod_left.step, pod_left.stl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]
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2026-08-12 feat(enclosures): open flange, right-side inserts, cradle-clear boards
    Keep the mating face as a rail + screw bosses for battery/board install,
    put clamshell heat-sets in the right half, and park boards outboard of the
    pitot clamp with cable gaps so keepouts no longer hit cradle lands.
    [pod_assembly.step, pod_left.step, pod_left.stl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]
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2026-08-18 feat(pod): restore BQ27441 Qmax per pack and avoid SOC-protect on factory FCC.
    Persist last FullChargeCapacity by design mAh, reprogram Qmax with design
    after ITPOR, and treat unmatched FCC as design/last-learned so a 1340 mAh
    leftover cannot hide capacity or trip Protect on a 2000 mAh pack.
    [bq27441.rs]
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2026-08-19 feat(enclosures): wing pod v3 — single-loft shell, aft service panel
    v2 built the outer mold line as mid ∪ nose ∪ tail ∪ panel-pad, four solids
    fused by boolean, and two classes of defect followed from that.
    The +Y panel pad was unioned at a fixed y (flush with the ellipse only at the
    bottom of the rocker cut) and used the SAME x/z rectangle for the outer body
    and the inner cavity, so outer.cut(inner) left its perimeter with zero wall:
    an ~80 x 3.5 mm slot into the electronics bay under the flat top, plus open
    slots at both X ends. And the body was 216 mm long with a 28 mm nose and a
    12 mm tail — fineness 3.4 with a near-flat base — because both fairings had
    been trimmed to sati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
    [pm_tray.step, pm_tray.stl, pod_assembly.step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]
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2026-08-19 chore(enclosures): refresh printed artifacts for the validated v3 build
    First artifact refresh under the new policy: the four preceding commits carry
    code, docs and QC PNGs only, so this is the single commit that moves the
    binaries.
    These are the parts that came out of a full `wing_pod_v3.py` run with
    validate_pod green, and a second run reproduced all five STLs byte-for-byte.
    Against the artifacts last committed:
    pod_left.stl 9.92 MB -> 6.66 MB the flange rail no longer fills the
    cover with a plate; one cradle bulkhead
    removed for heat-set access
    pod_right.stl 9.21 MB -> 9.35 MB tail rim restored, b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
    [pm_tray.step, pm_tray.stl, pod_assembly.step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]
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2026-08-21 fix(pod): program BQ27441 Design Capacity, not Qmax-as-mAh
    Qmax Cell 0 is a 16384-scaled Num. Writing learned FCC there left FullChargeCapacity stuck at the G1A 1340 leftover and CFGUPDATE retries suspended Impedance Track. Restore Design Capacity and Energy only after ITPOR.
    [bq27441.rs]
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

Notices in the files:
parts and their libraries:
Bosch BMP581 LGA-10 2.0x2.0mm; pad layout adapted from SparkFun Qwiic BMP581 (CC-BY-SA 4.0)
